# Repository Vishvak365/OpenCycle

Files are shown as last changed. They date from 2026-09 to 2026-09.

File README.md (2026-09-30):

# OpenCycle

An open-source GPS bike computer you print, solder and own.

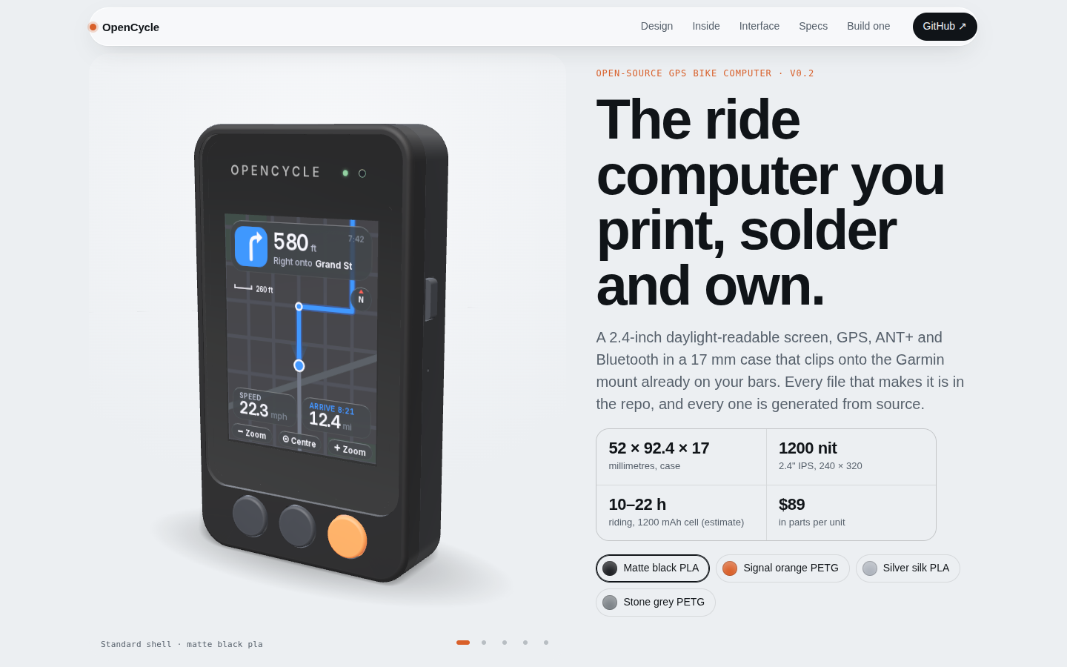
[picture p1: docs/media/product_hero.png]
OpenCycle v0.2, rendered from the CAD files


- **Screen:** 2.4" IPS TFT, 240 × 320, 1200 nit (Newhaven, ST7789), auto-dimmed by an ambient-light sensor.
- **Radios:** ESP32-S3 (Wi-Fi, Bluetooth to the phone, native USB) + Ezurio BL652 for ANT+ and Bluetooth sensors + u-blox MAX-M10S GPS with a 12 mm ceramic patch.
- **Also:** BMP581 barometer, I²S amp and sealed speaker, 3 soft keys + 2 side buttons, USB-C charging.
- **Battery:** 1200 mAh LiPo, ~10–22 h riding (estimate, not measured).
- **Case:** 52 × 92.4 × 17 mm, FDM-printed, Garmin quarter-turn mount; standard, aero and rugged shells.
- **Parts:** ~$89 per unit, every part priced and linked (Mouser + Digi-Key).

Everything is generated from source: the enclosure (CadQuery), the board **and** its schematic (KiCad 7 through Python + Freerouting), the BOMs, the print files and the 3D viewer.

## Status (v0.2)

| Area | State |
|---|---|
| Enclosure | Done. Fit-checked against placeholders and against every real part on the routed board. Print-ready STLs in [`print/`](print/README.md). |
| PCB | Routed, 4 layers. **DRC 0 errors / 0 unconnected**, ERC 0 errors, schematic netlist = board netlist. Gerbers, BOM and CPL in [`pcb/fab/`](pcb/fab). |
| Parts | Complete BOM with prices, links and specs: [`docs/sourcing/bom-v0.2.md`](docs/sourcing/bom-v0.2.md). |
| UI | "Lucent" design language, 10 screens: [`docs/UI.md`](docs/UI.md). |
| Firmware | Not started. The owner is finishing the UI first. Plan: [`docs/FIRMWARE.md`](docs/FIRMWARE.md). |

> **Ready to order a first prototype run, not yet built.** Nothing has been soldered or powered up. Treat the first five boards as prototypes and read the "not verified" list in [`pcb/README.md`](pcb/README.md) (RF, battery lead polarity, JLCPCB part rotations) before you pay.

## Build one

Step-by-step guides are in [`instructions/`](instructions/README.md):

1. [Order the parts](instructions/01-order-parts.md)
2. [Order the PCBs](instructions/02-order-pcb.md)
3. [Print the case](instructions/03-print-case.md)
4. [Assemble the board](instructions/04-assemble-board.md)
5. [Bring it up](instructions/05-bring-up.md)
6. [Final assembly](instructions/06-final-assembly.md)
7. [Next steps](instructions/07-next-steps.md)

## The board

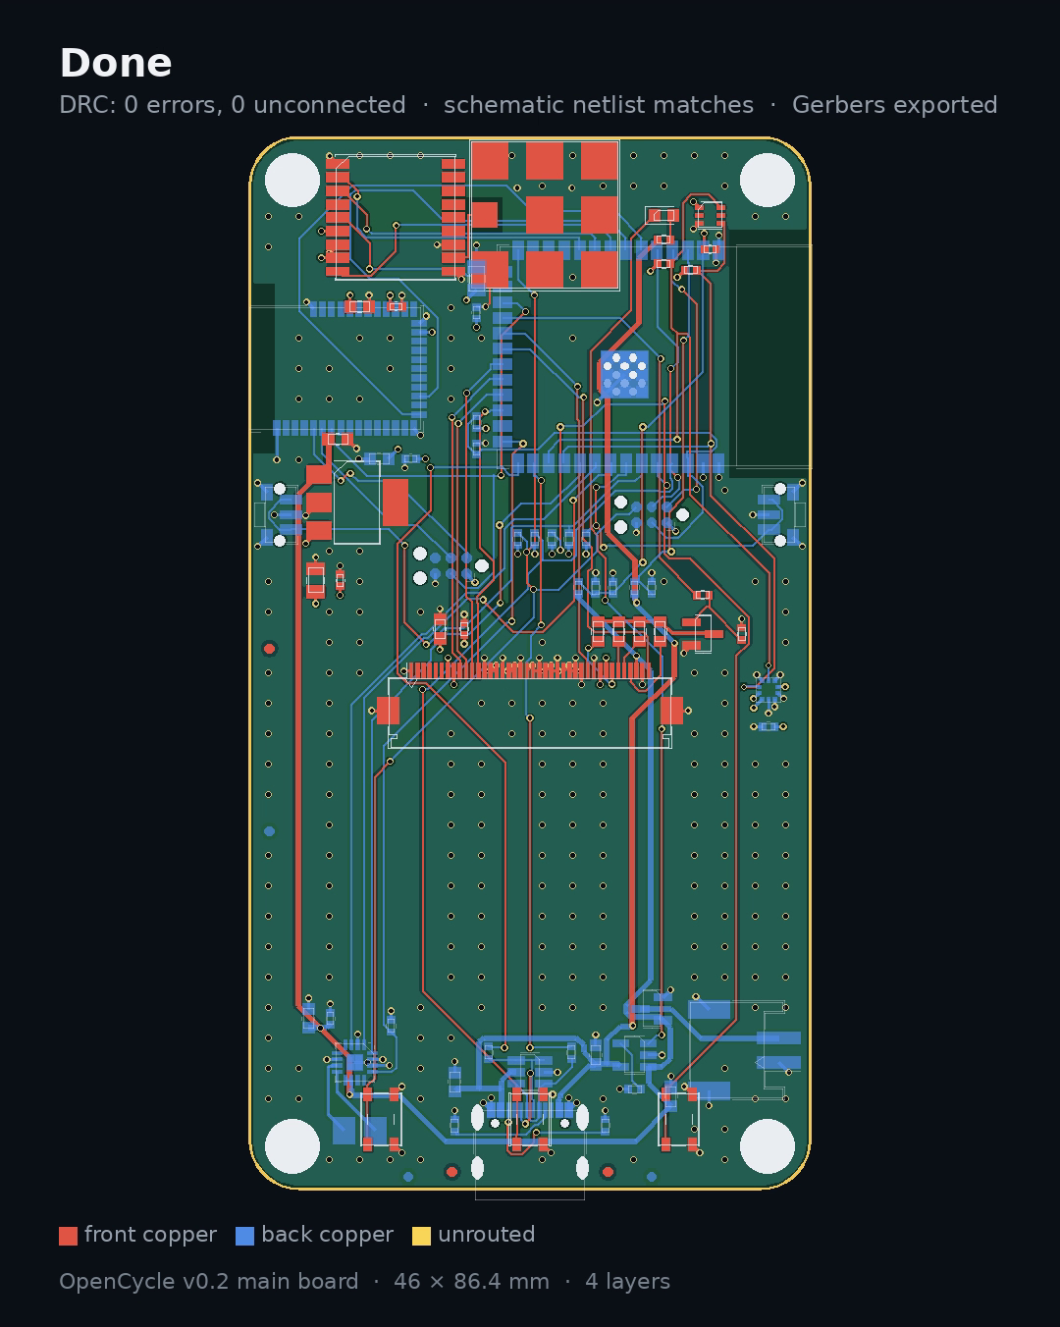
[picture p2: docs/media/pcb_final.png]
Routed v0.2 board


A time-lapse of the board being generated (placement, fan-out, routing, pours) is in [`docs/media/pcb_timelapse.mp4`](docs/media/pcb_timelapse.mp4).

## The interface

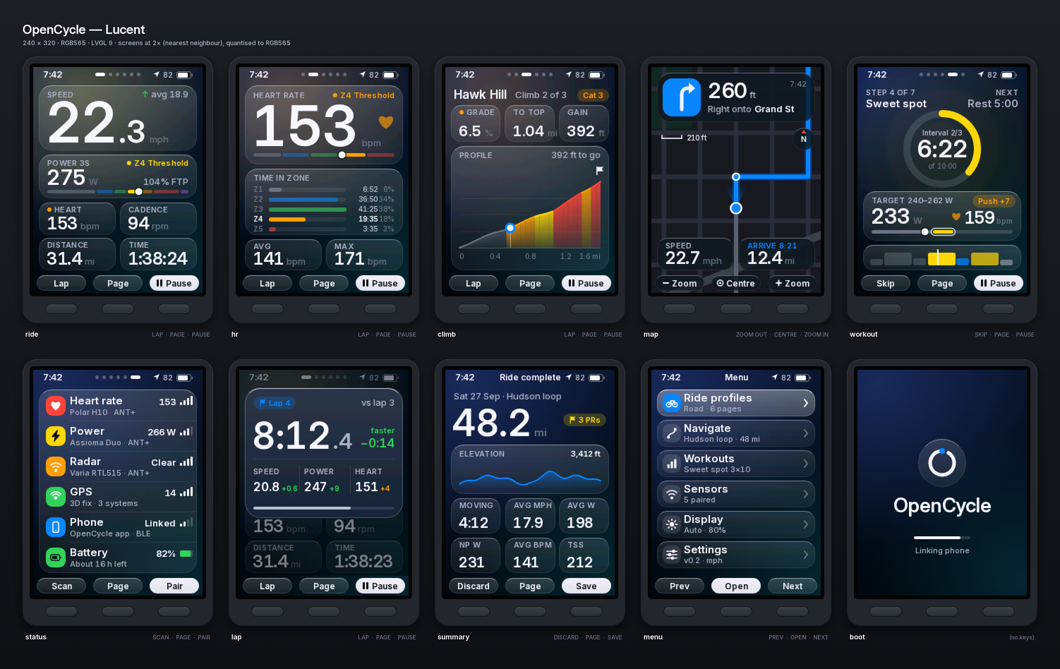
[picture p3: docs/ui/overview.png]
Lucent screens


## What's here

| Path | What it is |
|---|---|
| `cad/` | Parametric enclosure (CadQuery). `params.py` holds every dimension; `check_fit.py` and `board_fit.py` check it. |
| `pcb/` | `design.py` (parts, nets, placement, rules) → board, schematic, fab files. Status in `pcb/README.md`. |
| `print/` | Print-oriented STLs, STEP files and the cover-lens outline. |
| `viewer/` | three.js pages: `index.html` (studio viewer with net explorer) and `product.html` (product page). The Lucent reference renderer is `viewer/ui/screens_color.js`. |
| `instructions/` | How to order, build and bring up a unit. |
| `docs/` | Hardware, PCB, CAD, UI, sourcing and decision docs. Start with [`docs/README.md`](docs/README.md). |
| `tools/` | `build_all.sh` rebuilds everything; exporters for meshes, print files, BOM and the time-lapse. |
| `AGENTS.md` | Where the truth lives and what not to break, for AI agents and new contributors. |

## Quick start

```bash
# view the product (the generated assets are committed)
python3 -m http.server -d viewer 8000     # open http://localhost:8000/product.html or /index.html

# rebuild everything (CadQuery, KiCad 7, Java for Freerouting; see docs/SETUP.md)
./tools/build_all.sh
```

## Licence

No licence file has been chosen yet; until one is added, all rights are reserved by the author. The Inter typeface in `viewer/ui/fonts/` is used under the SIL Open Font License (`OFL-Inter.txt`).

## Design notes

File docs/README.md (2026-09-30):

# Documentation index

| Doc | Read it when |
|---|---|
| [../instructions/](../instructions/README.md) | You want to build one: order, print, assemble, bring up. |
| [SETUP.md](SETUP.md) | Installing the toolchain (CadQuery, KiCad 7, Freerouting). |
| [HARDWARE.md](HARDWARE.md) | What each part does and why, the ESP32 pin map, power budget. |
| [sourcing/](sourcing/README.md) | BOM with prices and links, part specs, stock problems, displays, market research. |
| [PCB.md](PCB.md) | Working on the board: stack-up, pipeline, placement, verification results. |
| [CAD.md](CAD.md) | Working on the enclosure: stack, front layout, variants. |
| [UI.md](UI.md) | The Lucent screen design language and the LVGL recipe. |
| [FIRMWARE.md](FIRMWARE.md) | Planning firmware. |
| [VIEWER.md](VIEWER.md) | Editing the three.js viewer. |
| [DECISIONS.md](DECISIONS.md) | Why things are the way they are, and what's still open. |
| [ROADMAP.md](ROADMAP.md) | What's next. |

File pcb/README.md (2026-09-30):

# OpenCycle main board v0.2 — status

**Ready to order a first prototype run** (5 boards): routed, DRC clean, schematic generated and netlist-matched, parts sourced, fab files exported. **Not yet built or tested** — treat the first run as a prototype and follow [`../instructions/05-bring-up.md`](../instructions/05-bring-up.md).

| What | Where |
|---|---|
| Board | `opencycle.kicad_pcb` (+ `.kicad_pro`, `.kicad_dru`, `fp-lib-table`, `sym-lib-table`: opens in KiCad 7+) |
| Schematic | `opencycle.kicad_sch`, PDF in `fab/opencycle_schematic.pdf` |
| Gerbers + drill | `fab/opencycle_v0.2_gerbers.zip` (upload to JLCPCB as-is) |
| Assembly | `fab/bom_jlcpcb.csv`, `fab/cpl_jlcpcb.csv`, `fab/assembly_front.pdf`, `fab/assembly_back.pdf` |
| Order list | `fab/bom_distributors.csv` and [`../docs/sourcing/bom-v0.2.md`](../docs/sourcing/bom-v0.2.md) |
| Checks | `drc_report.txt`, `erc_report.txt`, `check_place.py`, `check_netlist.py`, `../cad/board_fit.py` |

Everything is generated from `design.py` — do not hand-edit the board and then regenerate, you will lose the edit. If you do route by hand in KiCad, stop using the pipeline for that board and say so in `docs/DECISIONS.md`.

## Verified

- Pinouts of every IC/module against the manufacturer datasheet (see the header of `design.py` for the list and `docs/sourcing/part-specs.md` for details). Two errors in earlier notes were found and fixed: the BMP581 pin order and MAX-M10S pin 15.
- Land patterns drawn from datasheet drawings for the BMP581 and the Taoglas 12 mm patch; all other footprints from the KiCad 7 library.
- Mechanical fit of every real part (datasheet heights) against the enclosure, display, folded FFC, battery and speaker.
- DRC 0 errors / 0 unconnected; ERC 0 errors; schematic netlist == board netlist.

## Not verified (look at these before ordering / during bring-up)

1. **RF performance** of all three antennas (GPS patch ground is 46 mm wide and cut by the radio keep-outs; Taoglas characterised it on 50 × 50 mm). Expect to tune firmware (GPS LNA gain) and possibly move to a pin-fed patch later.
2. **Battery polarity** of the Adafruit lead vs. J2 (pin 1 −, pin 2 +). Q2 blocks a reversed cell, but measure before plugging in.
3. **JLCPCB rotation offsets** in `cpl_jlcpcb.csv` — JLC's preview shows each part; fix any that are rotated (common for SOT-23, QFN and connectors) in their tool before paying.
4. **RF_IN impedance**: 0.2 mm on the 1.0 mm JLC04101H-3313 stack-up is close to 50 Ω; confirm with the JLC impedance calculator or ask for impedance control.
5. **Backlight brightness** with 33 Ω ballasts: ≤ 45 mA per LED in the worst case (4.2 V, Vf 2.7 V), ~21 mA typical, so full brightness is only reached on a full battery. Don't lower the ballasts unless firmware caps the PWM duty from VBAT_SENSE: at 22 Ω the worst case is 68 mA per LED, above the 50 mA per-LED limit.
6. **Charging while running:** there is no USB power path — the system always runs from VBAT and the MCP73831 charges the cell and feeds the load in parallel (the same approach as Adafruit Feather boards). While the device is on and plugged in, the charger may not terminate (it holds 4.20 V). Fine for a few hours of charging; a power-path charger (e.g. BQ24072) is the v0.3 upgrade if this matters.
7. **Firmware**: nothing is written yet; the pin map is in `docs/HARDWARE.md`.

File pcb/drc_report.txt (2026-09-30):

** Drc report for opencycle.kicad_pcb **
** Created on 2026-09-30 06:21:55 **

** Found 6 DRC violations **
[lib_footprint_mismatch]: Footprint 'ESP32-S3-WROOM-1' does not match copy in library 'RF_Module'.
    Local override; Severity: warning
    @(36.2500 mm, 21.0000 mm): Footprint U1
[silk_edge_clearance]: Silkscreen clipped by board edge
    Rule: board setup constraints silk; Severity: warning
    @(49.0000 mm, 7.0000 mm): Line on Edge.Cuts
    @(49.1500 mm, 30.2000 mm): Line on B.Silkscreen
[silk_edge_clearance]: Silkscreen clipped by board edge
    Rule: board setup constraints silk; Severity: warning
    @(49.0000 mm, 7.0000 mm): Line on Edge.Cuts
    @(49.1500 mm, 11.8000 mm): Line on B.Silkscreen
[silk_edge_clearance]: Silkscreen clipped by board edge
    Rule: board setup constraints silk; Severity: warning
    @(3.0000 mm, 85.4000 mm): Line on Edge.Cuts
    @(3.0490 mm, 27.2070 mm): Line on B.Silkscreen
[silk_edge_clearance]: Silkscreen clipped by board edge
    Rule: board setup constraints silk; Severity: warning
    @(3.0000 mm, 85.4000 mm): Line on Edge.Cuts
    @(7.6210 mm, 16.7930 mm): Line on B.Silkscreen
[via_dangling]: Via is not connected or connected on only one layer
    Local override; Severity: warning
    @(45.6000 mm, 46.3875 mm): Via [I2C_SDA] on F.Cu - B.Cu

** Found 0 unconnected pads **

** Found 0 Footprint errors **

** End of Report **

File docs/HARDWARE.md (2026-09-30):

# Hardware (board v0.2, colour build)

Source of truth: [`pcb/design.py`](../pcb/design.py). Schematic: [`pcb/fab/opencycle_schematic.pdf`](../pcb/fab/opencycle_schematic.pdf) (generated from the same table, netlist-checked against the board). Prices, links and stock: [`sourcing/bom-v0.2.md`](sourcing/bom-v0.2.md).

## Block diagram

```
USB-C ─ ESD ─┬─ VBUS ── MCP73831 charger ──┐                  ┌─ AP7361C 3.3 V LDO ── +3V3 plane ─┐
             │                              ├── VBAT ─────────┼─ MAX98357A amp ── speaker          │
             └─ D+/D- (0R) ─ ESP32 USB      │                 └─ TFT backlight (4 × 33 R, PWM FET)  │
JST-PH ─ BATT+ ─ P-FET (reverse-battery) ───┘                                                      │
                                                                                                   │
   ┌──────────────── ESP32-S3-WROOM-1-N16R8 (UI, logging, Wi-Fi, BLE, USB) ◄──────────────────────┘
   │  SPI  ──► Newhaven 2.4" IPS TFT (ST7789, 240 × 320) via 40-pin FFC
   │  UART ──► u-blox MAX-M10S GPS ◄── 12 mm Taoglas patch
   │  UART ──► BL652 (nRF52832): ANT+ and BLE sensor bridge   [SWD on Tag-Connect J4]
   │  I²C  ──► BMP581 barometer, LTR-303 ambient light
   │  I²S  ──► MAX98357A class-D amp
   │  GPIO ◄── 3 front soft keys + 2 side buttons, battery / USB sense (ADC)
```

## Parts and why

| Ref | Part | Job | Why this one |
|---|---|---|---|
| U1 | Espressif ESP32-S3-WROOM-1-N16R8 | Main MCU: UI (LVGL), logging, Wi-Fi sync, BLE, native USB | Enough RAM (8 MB PSRAM) for two 150 KB frame buffers and map tiles; USB flashing without a programmer. Antenna at the right board edge. |
| U2 | Ezurio BL652-SA (nRF52832) | ANT+ and BLE sensor bridge | The ESP32 has no ANT+. Pre-certified module with integrated antenna at the left edge. |
| U3 | u-blox MAX-M10S | GPS / Galileo / BeiDou / GLONASS | Lowest-power receiver in its class (~25 mW tracking). |
| AE1 | Taoglas DSGP.1575.12.4.A.02 | 12 × 12 mm ceramic GPS patch | Best reception that fits the 15.6 mm top band; land pattern from the Taoglas datasheet. |
| J3 | Hirose FH12-40S-0.5SH(55) | 40-pin FFC connector for the display | Bottom contact, matches the Newhaven tail after it folds behind the panel. |
| — | Newhaven NHD-2.4-240320AF-CSXP | 2.4" IPS TFT 240 × 320, 1200 nit | In stock at Mouser, datasheet with full drawing; readable in daylight at full backlight. |
| Q1, R5–R10 | DMG2302UK + 4 × 33 Ω (0603) | Backlight PWM | LEDA from VBAT: ≤ 45 mA per LED even at 4.2 V with the lowest Vf (datasheet max 50 mA per LED / 200 mA total); ~21 mA typ. at 3.7 V. |
| U4 | Lite-On LTR-303ALS | Ambient light → auto backlight | Biggest lever on battery life with a TFT. Sits under a clear window in the lens mask. |
| U8 | Bosch BMP581 | Barometer: altitude, climb | Best-in-class noise; the only well-stocked option (Digi-Key). Next to the case vent. |
| U7 | MAX98357A | I²S class-D amp | Real sampled audio (alerts, turn prompts). |
| LS1 | Same Sky CMS-151125-078L100 | 15 × 11 mm IP67 speaker | Fires through the back-shell grille. |
| U6 | MCP73831-2 | Li-ion charger, 500 mA (R15 = 2 k) | Simple, proven. |
| U5 | Diodes AP7361C-33E (SOT-223) | 3.3 V, 1 A LDO | ESP32 Wi-Fi peaks ~500 mA. Note: the "E" (not "ER") package, pin 1 IN / 2 GND / 3 OUT. |
| Q2 | DMG2305UX | Reverse-battery protection | P-FET, gate to ground: a reversed cell can't damage the board. |
| J1, D2 | GCT USB4105 + USBLC6-2SC6 | USB-C with ESD | 5.1 k CC pull-downs for 5 V from any USB-C charger. |
| J2 | JST S2B-PH-SM4-TB | Battery socket | Matches the Adafruit 258 cell's JST-PH plug. Pin 1 −, pin 2 +. |
| SW1–SW3 | C&K PTS810 (2.5 mm) | Front soft keys | Top-actuated; the display draws their labels. |
| SW4, SW5 | Alps SKRTLAE010 | Side buttons (power/back, menu) | Side-actuated, sits behind the wall plungers. |
| J4, J5 | Tag-Connect TC2030-NL pads | BL652 SWD / ESP32 recovery UART | Nothing to assemble; one cable for all boards. |

## ESP32-S3 pin map

| GPIO | Net | Notes |
|---|---|---|
| IO0 | KEY_L | Strapping pin: hold the left key while resetting = download mode |
| IO1 / IO2 | VBAT_SENSE / VBUS_SENSE | ADC1 (1 M/1 M and 100 k/100 k dividers) |
| IO3 | AMP_EN | Strapping pin (JTAG source, only with eFuse); 100 k pull-down keeps the amp off at boot |
| IO4 / IO5 | KEY_C / KEY_R | RTC GPIOs: can wake from deep sleep |
| IO6 / IO7 | BTN_PWR / BTN_MENU | RTC GPIOs |
| IO8 / IO18 | I2C_SDA / I2C_SCL | 4.7 k pull-ups; BMP581 0x46, LTR-303 0x29 |
| IO9–IO14 | LCD_DC, CS, MOSI, SCK, TE, RST | IO10–IO12 are the FSPI IO_MUX pins (fast SPI) |
| IO21 | LCD_BL | Backlight PWM (LEDC) |
| IO15–IO17 | I2S_BCLK, LRCLK, DIN | |
| IO19 / IO20 | USB D− / D+ | Native USB (serial/JTAG + flashing) |
| IO38 / IO39 / IO40 / IO48 | GPS_TX (in) / GPS_RX (out) / GPS_RST / GPS_EXTINT | |
| IO41 / IO42 / IO47 | BLE_TX (in) / BLE_RX (out) / BLE_RST | BL652 UART on SIO_06 / SIO_08, reset on SIO_21 |
| TXD0 / RXD0 / EN | Console / reset | On Tag-Connect J5 for recovery |
| IO35–IO37 | — | Used by the octal PSRAM on the N16R8, not available |
| IO45 / IO46 | — | Strapping pins, left at their default pull-downs |

## Power budget (estimate, riding)

| Load | Avg current |
|---|---|
| GPS continuous tracking | 7–8 mA |
| ESP32-S3 (UI, BLE, logging; Wi-Fi only to sync) | 15–25 mA |
| BL652 ANT+/BLE sensors | 1–2 mA |
| TFT logic | ~10 mA |
| Backlight (auto-dimmed) | 20–85 mA (≤ 180 mA at 100 % PWM on a full battery) |
| **Total** | **~55–130 mA** |

With the 1200 mAh cell: **~10–22 h**. Sleep: ESP32 deep sleep + GPS backup mode + BL652 System OFF, in the tens of µA (plus the LDO's quiescent current). Details: [`sourcing/power-budget.md`](sourcing/power-budget.md).

## Things a reviewer should look at first

1. RF: the ESP32 and BL652 antennas are at the board edges with keep-outs, but the case walls and battery are close; the GPS patch ground is smaller than Taoglas's 50 × 50 mm test board. Nothing is measured yet.
2. Battery polarity at J2 (see [`instructions/05-bring-up.md`](../instructions/05-bring-up.md)); Q2 protects the board either way.
3. Backlight current: firmware should cap the PWM duty on a full battery if the panel gets warm.
4. No USB power path: the board always runs from the battery; the charger feeds cell and load in parallel and may not terminate while the device is on (see `pcb/README.md`).
5. The BMP581 INT pin is tied to ground (Bosch-recommended when unused): firmware must keep `INT_CONFIG.int_en = 0`.

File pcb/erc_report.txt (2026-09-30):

ERC report (2026-09-30T06:03:15+0000, Encoding UTF8)
Report includes: Errors, Warnings, Exclusions

***** Sheet /
[lib_symbol_issues]: The current configuration does not include the symbol library 'RF_Module'
    ; warning
    @(66.04 mm, 74.93 mm): Symbol U1 [ESP32-S3-WROOM-1]
[lib_symbol_issues]: The current configuration does not include the symbol library 'Device'
    ; warning
    @(50.80 mm, 119.38 mm): Symbol C1 [C]
[lib_symbol_issues]: The current configuration does not include the symbol library 'Connector_Generic'
    ; warning
    @(138.43 mm, 52.07 mm): Symbol J5 [Conn_01x06]
[lib_symbol_issues]: The current configuration does not include the symbol library 'Device'
    ; warning
    @(50.80 mm, 139.70 mm): Symbol C2 [C]
[lib_symbol_issues]: The current configuration does not include the symbol library 'Device'
    ; warning
    @(50.80 mm, 160.02 mm): Symbol R1 [R]
[lib_symbol_issues]: The current configuration does not include the symbol library 'Device'
    ; warning
    @(50.80 mm, 180.34 mm): Symbol C3 [C]
[lib_symbol_issues]: The current configuration does not include the symbol library 'Device'
    ; warning
    @(205.74 mm, 116.84 mm): Symbol C4 [C]
[lib_symbol_issues]: The current configuration does not include the symbol library 'RF_Bluetooth'
    ; warning
    @(231.14 mm, 74.93 mm): Symbol U2 [BL652]
[lib_symbol_issues]: The current configuration does not include the symbol library 'Device'
    ; warning
    @(205.74 mm, 137.16 mm): Symbol C5 [C]
[lib_symbol_issues]: The current configuration does not include the symbol library 'Connector'
    ; warning
    @(58.42 mm, 243.84 mm): Symbol J1 [USB_C_Receptacle_USB2.0_16P]
[lib_symbol_issues]: The current configuration does not include the symbol library 'Device'
    ; warning
    @(125.73 mm, 232.41 mm): Symbol R14 [R]
[lib_symbol_issues]: The current configuration does not include the symbol library 'Connector'
    ; warning
    @(208.28 mm, 163.83 mm): Symbol J4 [Conn_ARM_SWD_TagConnect_TC2030-NL]
[lib_symbol_issues]: The current configuration does not include the symbol library 'Device'
    ; warning
    @(125.73 mm, 252.73 mm): Symbol C14 [C]
[lib_symbol_issues]: The current configuration does not include the symbol library 'Device'
    ; warning
    @(50.80 mm, 283.21 mm): Symbol R11 [R]
[lib_symbol_issues]: The current configuration does not include the symbol library 'Device'
    ; warning
    @(50.80 mm, 303.53 mm): Symbol R12 [R]
[lib_symbol_issues]: The current configuration does not include the symbol library 'Battery_Management'
    ; warning
    @(135.89 mm, 276.86 mm): Symbol U6 [MCP73831-2-OT]
[lib_symbol_issues]: The current configuration does not include the symbol library 'Transistor_FET'
    ; warning
    @(203.20 mm, 233.68 mm): Symbol Q2 [DMG2301L]
[lib_symbol_issues]: The current configuration does not include the symbol library 'Regulator_Linear'
    ; warning
    @(205.74 mm, 251.46 mm): Symbol U5 [AP7361C-33E]
[lib_symbol_issues]: The current configuration does not include the symbol library 'Device'
    ; warning
    @(125.73 mm, 300.99 mm): Symbol R15 [R]
[lib_symbol_issues]: The current configuration does not include the symbol library 'Power_Protection'
    ; warning
    @(55.88 mm, 325.12 mm): Symbol D2 [USBLC6-2SC6]
[lib_symbol_issues]: The current configuration does not include the symbol library 'Device'
    ; warning
    @(198.12 mm, 275.59 mm): Symbol C11 [C]
[lib_symbol_issues]: The current configuration does not include the symbol library 'Device'
    ; warning
    @(328.93 mm, 99.06 mm): Symbol C6 [C]
[lib_symbol_issues]: The current configuration does not include the symbol library 'Device'
    ; warning
    @(125.73 mm, 321.31 mm): Symbol C15 [C]
[lib_symbol_issues]: The current configuration does not include the symbol library 'Device'
    ; warning
    @(328.93 mm, 119.38 mm): Symbol C7 [C]
[lib_symbol_issues]: The current configuration does not include the symbol library 'RF_GPS'
    ; warning
    @(344.17 mm, 64.77 mm): Symbol U3 [MAX-M10S]
[lib_symbol_issues]: The current configuration does not include the symbol library 'Device'
    ; warning
    @(265.43 mm, 232.41 mm): Symbol C17 [C]
[lib_symbol_issues]: The current configuration does not include the symbol library 'Device'
    ; warning
    @(50.80 mm, 349.25 mm): Symbol R13 [R]
[lib_symbol_issues]: The current configuration does not include the symbol library 'Device'
    ; warning
    @(198.12 mm, 295.91 mm): Symbol C12 [C]
[lib_symbol_issues]: The current configuration does not include the symbol library 'Device'
    ; warning
    @(125.73 mm, 341.63 mm): Symbol C16 [C]
[lib_symbol_issues]: The current configuration does not include the symbol library 'Device'
    ; warning
    @(265.43 mm, 252.73 mm): Symbol R18 [R]
[lib_symbol_issues]: The current configuration does not include the symbol library 'Device'
    ; warning
    @(198.12 mm, 316.23 mm): Symbol C13 [C]
[lib_symbol_issues]: The current configuration does not include the symbol library 'Device'
    ; warning
    @(265.43 mm, 273.05 mm): Symbol R19 [R]
[lib_symbol_issues]: The current configuration does not include the symbol library 'Connector_Generic_MountingPin'
    ; warning
    @(130.81 mm, 358.14 mm): Symbol J2 [Conn_01x02_MountingPin]
[lib_symbol_issues]: The current configuration does not include the symbol library 'Device'
    ; warning
    @(198.12 mm, 336.55 mm): Symbol R16 [R]
[lib_symbol_issues]: The current configuration does not include the symbol library 'Device'
    ; warning
    @(269.24 mm, 289.56 mm): Symbol D1 [LED]
[lib_symbol_issues]: The current configuration does not include the symbol library 'Device'
    ; warning
    @(265.43 mm, 306.07 mm): Symbol R2 [R]
[lib_symbol_issues]: The current configuration does not include the symbol library 'Device'
    ; warning
    @(198.12 mm, 356.87 mm): Symbol R17 [R]
[lib_symbol_issues]: The current configuration does not include the symbol library 'Sensor_Optical'
    ; warning
    @(355.60 mm, 238.76 mm): Symbol U4 [LTR-303ALS-01]
[lib_symbol_issues]: The current configuration does not include the symbol library 'Device'
    ; warning
    @(345.44 mm, 265.43 mm): Symbol C8 [C]
[lib_symbol_issues]: The current configuration does not include the symbol library 'Connector_Generic_MountingPin'
    ; warning
    @(435.61 mm, 95.25 mm): Symbol J3 [Conn_01x40_MountingPin]
[lib_symbol_issues]: The current configuration does not include the symbol library 'Device'
    ; warning
    @(345.44 mm, 285.75 mm): Symbol R3 [R]
[lib_symbol_issues]: The current configuration does not include the symbol library 'Device'
    ; warning
    @(345.44 mm, 306.07 mm): Symbol R4 [R]
[lib_symbol_issues]: The current configuration does not include the symbol library 'Device'
    ; warning
    @(430.53 mm, 167.64 mm): Symbol C9 [C]
[pin_to_pin]: Pins of type Bidirectional and Power output are connected
    ; warning
    @(345.44 mm, 330.20 mm): Symbol U8 Pin 5 [SDO, Bidirectional, Line]
    @(670.56 mm, 548.64 mm): Symbol #FLG01 Pin 1 [pwr, Power output, Line]
[lib_symbol_issues]: The current configuration does not include the symbol library 'Device'
    ; warning
    @(487.68 mm, 50.80 mm): Symbol C10 [C]
[pin_to_pin]: Pins of type Tri-state and Power input are connected
    ; warning
    @(365.76 mm, 327.66 mm): Symbol U8 Pin 7 [INT, Tri-state, Line]
    @(360.68 mm, 335.28 mm): Symbol U8 Pin 9 [VSS, Power input, Line]
[lib_symbol_issues]: The current configuration does not include the symbol library 'Device'
    ; warning
    @(487.68 mm, 71.12 mm): Symbol R5 [R]
[lib_symbol_issues]: The current configuration does not include the symbol library 'Device'
    ; warning
    @(345.44 mm, 351.79 mm): Symbol C20 [C]
[lib_symbol_issues]: The current configuration does not include the symbol library 'Device'
    ; warning
    @(487.68 mm, 91.44 mm): Symbol R6 [R]
[lib_symbol_issues]: The current configuration does not include the symbol library 'Device'
    ; warning
    @(487.68 mm, 111.76 mm): Symbol R7 [R]
[lib_symbol_issues]: The current configuration does not include the symbol library 'Device'
    ; warning
    @(487.68 mm, 132.08 mm): Symbol R8 [R]
[lib_symbol_issues]: The current configuration does not include the symbol library 'Audio'
    ; warning
    @(450.85 mm, 241.30 mm): Symbol U7 [MAX98357A]
[lib_symbol_issues]: The current configuration does not include the symbol library 'Device'
    ; warning
    @(438.15 mm, 270.51 mm): Symbol C18 [C]
[lib_symbol_issues]: The current configuration does not include the symbol library 'Transistor_FET'
    ; warning
    @(492.76 mm, 153.67 mm): Symbol Q1 [DMG2302U]
[lib_symbol_issues]: The current configuration does not include the symbol library 'Device'
    ; warning
    @(487.68 mm, 175.26 mm): Symbol R9 [R]
[pin_to_pin]: Pins of type Unspecified and Power input are connected
    ; warning
    @(453.39 mm, 254.00 mm): Symbol U7 Pin 17 [PAD, Unspecified, Line]
    @(448.31 mm, 254.00 mm): Symbol U7 Pin 3 [GND, Power input, Line]
[lib_symbol_issues]: The current configuration does not include the symbol library 'Device'
    ; warning
    @(438.15 mm, 290.83 mm): Symbol C19 [C]
[lib_symbol_issues]: The current configuration does not include the symbol library 'Device'
    ; warning
    @(438.15 mm, 311.15 mm): Symbol R20 [R]
[lib_symbol_issues]: The current configuration does not include the symbol library 'Device'
    ; warning
    @(547.37 mm, 50.80 mm): Symbol R10 [R]
[lib_symbol_issues]: The current configuration does not include the symbol library 'Device'
    ; warning
    @(443.23 mm, 327.66 mm): Symbol LS1 [Speaker]
[lib_symbol_issues]: The current configuration does not include the symbol library 'Switch'
    ; warning
    @(539.75 mm, 228.60 mm): Symbol SW1 [SW_Push]
[lib_symbol_issues]: The current configuration does not include the symbol library 'Switch'
    ; warning
    @(539.75 mm, 241.30 mm): Symbol SW2 [SW_Push]
[lib_symbol_issues]: The current configuration does not include the symbol library 'Switch'
    ; warning
    @(539.75 mm, 254.00 mm): Symbol SW3 [SW_Push]
[lib_symbol_issues]: The current configuration does not include the symbol library 'Switch'
    ; warning
    @(539.75 mm, 266.70 mm): Symbol SW4 [SW_Push]
[lib_symbol_issues]: The current configuration does not include the symbol library 'Switch'
    ; warning
    @(539.75 mm, 279.40 mm): Symbol SW5 [SW_Push]
[lib_symbol_issues]: The current configuration does not include the symbol library 'Device'
    ; warning
    @(534.67 mm, 295.91 mm): Symbol R21 [R]
[lib_symbol_issues]: The current configuration does not include the symbol library 'Device'
    ; warning
    @(534.67 mm, 316.23 mm): Symbol R22 [R]
[lib_symbol_issues]: The current configuration does not include the symbol library 'Device'
    ; warning
    @(534.67 mm, 336.55 mm): Symbol R23 [R]
[lib_symbol_issues]: The current configuration does not include the symbol library 'Device'
    ; warning
    @(596.90 mm, 232.41 mm): Symbol R25 [R]
[lib_symbol_issues]: The current configuration does not include the symbol library 'Device'
    ; warning
    @(534.67 mm, 356.87 mm): Symbol R24 [R]
[lib_symbol_issues]: The current configuration does not include the symbol library 'power'
    ; warning
    @(670.56 mm, 548.64 mm): Symbol #FLG01 [PWR_FLAG]
[lib_symbol_issues]: The current configuration does not include the symbol library 'power'
    ; warning
    @(693.42 mm, 548.64 mm): Symbol #FLG02 [PWR_FLAG]
[lib_symbol_issues]: The current configuration does not include the symbol library 'power'
    ; warning
    @(716.28 mm, 548.64 mm): Symbol #FLG03 [PWR_FLAG]

 ** ERC messages: 73  Errors 0  Warnings 73

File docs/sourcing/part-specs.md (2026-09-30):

# Part specs

Engineering data for every part considered. Units are mm unless noted. "Verified" / "Library" / "Open" are explained in [README.md](README.md).

---

## Colour build (v0.2)

### ESP32-S3-WROOM-1-N16R8 — main MCU
- Buy: Mouser 356-ESP32S3WRM1N16R8, $6.72, 47,727 in stock (Verified). Digi-Key ~$6.76.
- Size: **25.5 × 18.0 × 3.1**, PCB antenna at one short end (Verified, Mouser).
- Memory: 16 MB quad-SPI flash, 8 MB octal PSRAM. Dual-core LX7 at 240 MHz, 512 KB SRAM.
- Radio: Wi-Fi 802.11 b/g/n, BLE 5.0, 20.5 dBm. **No ANT+.**
- Supply: 3.0–3.6 V; Wi-Fi transmit peaks ~500 mA, so the regulator must handle 1 A.
- Operating temperature −40 to +65 °C (N16R8 variant).
- Interfaces: native USB (flash and debug over USB-C, no programmer needed), SPI, I²C, I²S, UART, PWM.
- Footprint: KiCad `RF_Module:ESP32-S3-WROOM-1`, 62 pads, fab body 18.1 × 25.6 (Library). Keep copper off every layer under the antenna and ≥ 15 mm clear around it where possible; antenna end at a board edge.
- Boot: GPIO0 strap (tie to a side button); EN with 10 k + 1 µF RC.

### Ezurio (Laird) BL652-SA-01-T/R — ANT+ / BLE coprocessor
- Buy: Mouser 239-BL652-SA-01-T/R, $10.40, 5,583 in stock (Verified). Newark $9.46. Digi-Key T/R ~$11.61 (1000 MOQ).
- Chip: Nordic nRF52832 (Mouser lists the part as Bluetooth v4.2; the chip supports BLE 5 with Nordic SoftDevices, including the ANT variants S212/S332).
- Size: fab body 14.1 × 10.1 (Library), integrated antenna, NFC pins.
- Footprint: KiCad `RF_Module:Laird_BL652`, 39 pads (Library).
- Programming: SWD via Tag-Connect pads, or from the ESP32 later.
- Link to ESP32: UART (TX/RX, optional RTS/CTS) plus a reset line.
- Note: ANT SoftDevices need Garmin's ANT+ licence for commercial products; free for development and hobby use.

### u-blox MAX-M10S-00B — GPS
- Buy: Mouser 377-MAX-M10S-00B, $9.12 (2,746 at the second check, 16,866 at the first); Digi-Key 672-MAX-M10S-00B-CT-ND $11.42, 4,987 (Verified). LCSC C4153167.
- Size: 9.7 × 10.1 × ~2.5, LCC-18 (Verified/Library). KiCad `RF_GPS:ublox_MAX`.
- Constellations: GPS, Galileo, BeiDou, GLONASS, QZSS, NavIC. Integrated TCXO, LNA, SAW.
- Pins (Verified, data sheet UBX-20035208 R02 Table 9): 1 GND, 2 TXD, 3 RXD, 4 TIMEPULSE, 5 EXTINT, 6 V_BCKP, 7 V_IO (must be tied to VCC), 8 VCC, 9 RESET_N, 10 GND, 11 RF_IN, 12 GND, 13 LNA_EN, 14 VCC_RF, **15 Reserved (leave open; KiCad's symbol calls it VIO_SEL)**, 16 SDA, 17 SCL, 18 SAFEBOOT_N (leave open).
- Power: ~25 mW continuous tracking (u-blox figure); Mouser lists "100 mA" as the maximum operating current.
- RF: 50 Ω RF_IN; for a passive patch, leave VCC_RF and LNA_EN open.

### Taoglas DSGP.1575.12.4.A.02 — GPS patch antenna (SMT) — used on v0.2
- Buy: Digi-Key, $4.25, 1,474 in stock (2026-09-30, via findchips). Newark 289. Mouser did not list stock.
- Size **12 × 12 × 4**, 3.3 g, ceramic, passive, GPS L1 / Galileo E1, 1575.42 ± 1.023 MHz, 2.73 dBi peak, 62 % efficiency, RHCP, tuned on a **50 × 50 mm** ground plane (ours is 46 × 86 but cut by the antenna keep-outs: expect less than datasheet performance).
- Pins: 1 = RF feed, 2–9 = ground.
- Land pattern (Verified from the §6.5 footprint drawing): eight 3.0 × 3.0 mm ground pads on a 4.5 mm grid around the centre, the feed pad 2.0 × 2.0 mm centred 4.9 mm from the centre on the feed side, 0.5 mm copper keep-out ring around the feed. Antenna underside: ground metallisation with a 2.0 × 0.8 mm feed contact at the edge (§5).
- The earlier 15 mm part (DSGP.1575.15.4.A.02) is not used any more.

### Newhaven NHD-2.4-240320AF-CSXP — 2.4" IPS TFT
- Buy: Mouser 763-24240320AFCSXP, **$15.86, 1,032 in stock** (Verified). Digi-Key: 0 in stock ($16.91). Newhaven direct $13.94. Touch variants: resistive -T $20.12, capacitive -CTP $32.08.
- Technology: IPS, transmissive, normally black, anti-glare; 1200 cd/m²; contrast 1500; 80° viewing all round; 262K colours; −20 to +70 °C operating.
- Controller: Sitronix ST7789VI. Interfaces: 8/16-bit 8080 parallel, 3/4-wire SPI.
- Mechanical (Verified, drawing Rev 2B 03/11/2025):
  - Outline 42.80 ± 0.2 × 59.91 ± 0.2 × 2.55 ± 0.2.
  - Bezel opening 38.92 × 51.16 (margins 1.94 sides, 1.92 top). Polariser 38.42 × 50.66 (2.19 / 2.17). Active area 36.72 × 48.96 (3.04 sides, 3.02 top, 7.93 bottom); active-area centre 27.50 below the top edge.
  - SUS304 frame 0.15.
  - FFC exits the bottom edge: EMI-shielded section 39.0 ± 0.2 wide, 13.2 long, then a tail 20.5 ± 0.07 wide. Unfolded, the tail end is 30.0 ± 0.5 below the panel; tail left edge 11.15 ± 0.3 from the outline's left edge (front view).
  - Contacts: 40 × 0.35 ± 0.03 wide at 0.50 ± 0.05 pitch (span 19.50 ± 0.05); pin 1 on the left in front view; PI stiffener 0.30 ± 0.03 on the opposite side; stiffened length ≥ 5.5; R0.3 corners.
  - Folded behind the panel: contact end 27.80 ± 0.3 above the panel's bottom edge; 11.15 ± 0.3 from the rear-view left edge; pin 40 left, pin 1 right; ≤ 0.8 extra thickness behind the panel; bend ~2.43.
- Pinout (Verified): 1 GND · 2–5 NC · 6 SDO · 7 VDD (3.3 V) · 8 VDDI (1.65–3.6 V) · 9 SDA · 10 CSX · 11 DCX/SCL · 12 WRX/DCX · 13 RDX · 14–29 DB0–DB15 · 30 RESX · 31–33 IM0–IM2 · 34–37 LEDK1–4 · 38 LEDA · 39 GND · 40 TE.
- 4-wire SPI: IM0 = 0, IM1 = 1, IM2 = 1.
- Logic supply ~10 mA typ (5–15 mA).
- Backlight: 4 LEDs in parallel, common anode, Vf 2.7 / 3.0 / 3.4 V (min/typ/max), If 160 mA typ, 200 mA max, 50,000 h to half brightness.
- Recommended connector: Molex 54132-4062 (bottom contact).
- [Datasheet](https://newhavendisplay.com/content/specs/NHD-2.4-240320AF-CSXP.pdf) · [Product page](https://newhavendisplay.com/2-4-tft-lcd-ips-high-brightness-display/). The drawing carries Newhaven's "do not reproduce" notice, so only the numbers are transcribed here.

### Hirose FH12-40S-0.5SH(55) — display FFC connector
- Buy: Mouser 798-FH12-40S-0.5SH55, $2.50, 25,967 (Verified). Bottom contact, right angle, ZIF, 0.5 mm pitch, gold, 500 mA, −40 to +85 °C.
- Footprint: KiCad `Connector_FFC-FPC:Hirose_FH12-40S-0.5SH_1x40-1MP_P0.50mm_Horizontal` (Library).
- Newhaven's recommended alternative: Molex 54132-4062, Mouser 538-54132-4062, $2.42, 30,165 in stock, bottom contact (no KiCad footprint).

### Diodes DMG2305UX-7 — reverse-battery P-FET (v0.2)
- Digi-Key DMG2305UX-7DICT-ND, $0.30, 75,458 in stock (2026-09-30). P-channel 20 V 4.2 A SOT-23, pinout 1 G · 2 S · 3 D (Diodes SOT-23 standard; KiCad symbol DMG2301L used, same pinout). Gate to GND, drain to the battery, source to VBAT.

### Diodes DMG2302UK-7 — backlight switch
- Mouser 621-DMG2302UK-7, $0.39, 238,766 (Verified). N-channel, SOT-23, 20 V, 2.8 A, 90 mΩ, Vgs(th) 0.3 V, 660 mW.
- Circuit: LEDA from 3.3 V (or VBAT); each LEDKx through its own ballast resistor to the drain; PWM on the gate from the ESP32 (LEDC peripheral).

### Lite-On LTR-303ALS-01 — ambient light sensor
- Mouser 859-LTR-303ALS-01, $0.68, 29,622 (Verified). I²C, 0.01–64k lux, 50/60 Hz flicker rejection, −30 to +70 °C.
- Footprint: KiCad `OptoDevice:Lite-On_LTR-303ALS-01` (Library), 2 × 2 ChipLED-6. Needs a clear window in the lens mask.

### Bosch BMP581 — barometer
- Buy: **Digi-Key 828-BMP581CT-ND, $3.07, 462** (Verified). Mouser 262-BMP581: 0 in stock, 159,933 on order.
- Package: 10-pin metal-lid LGA, 2.0 × 2.0 (1.9–2.1), height 0.75 typ (0.7–0.8) (Verified, datasheet).
- Pins (Verified against Table 28 of BST-BMP581-DS004-13, 2026-09-30): 1 VDDIO · 2 SCK · 3 VSS · 4 SDI · 5 SDO · 6 CSB · 7 INT · 8 VSS · 9 VSS · 10 VDD. **Correction:** an earlier version of this file listed a different (wrong) order.
- Supply: VDD 1.71–3.6 V, VDDIO 1.08–3.6 V. I²C address 0x46 (SDO = 0) or 0x47 (SDO = 1); SPI up to 12 MHz; I3C.
- Land pattern (Verified, datasheet §8.1–8.2 drawings): package pads 0.25 × 0.275 at ±0.7625 mm, 0.5 mm pitch; land = pad + 25 µm per side (0.30 × 0.325); top view pin 1 top-left, pins 10-9-8 along the top edge. Implemented in `pcb/lib/gen_footprints.py`. I²C: CSB to VDDIO, SDO to GND (0x46), INT to GND with the interrupt disabled (Bosch §6.2).
- Needs a vent to outside air: a hole in the case with a breathable membrane.

### Analog Devices / Maxim MAX98357AETE+T — I²S class-D amp
- Mouser 700-MAX98357AETE+T, $4.08, 10,971 (Verified; Mouser says it will stop carrying it). Digi-Key MAX98357AETE+TCT-ND $3.73, 30,936. LCSC C910544.
- TQFN-16 3 × 3, EP. 2.5–5.5 V supply (run from VBAT). 3.2 W into 4 Ω; ~1 W into 8 Ω at 3.7 V. THD+N 0.013 %.
- Pins (KiCad symbol): 1 DIN · 2 GAIN_SLOT · 3 GND · 4 SD_MODE · 7/8 VDD · 9 OUTP · 10 OUTN · 11/15 GND · 14 LRCLK · 16 BCLK · 17 EP (GND) · 5/6/12/13 NC.
- Gain: GAIN_SLOT to GND = 12 dB, to VDD = 6 dB, open = 9 dB, 100 k to GND = 15 dB, 100 k to VDD = 3 dB. SD_MODE high = left channel; low = shutdown.

### Same Sky CMS-151125-078L100 — speaker
- Mouser 490-CMS151125078L100, $2.96, 597 (Verified). Variants: -078S-67 spring contacts $2.25 (890); -078SP-67 solder pads $2.99 (1,392); -078L100A-67 wire + Molex 51021 $3.15 (796).
- **15 × 11 × 2.5**, 8 Ω, 0.7 W rated / 1.0 W max, 88–94 dB SPL (91 typ), resonance 800–1,200 Hz in a 1 cc enclosure, 100 Hz–20 kHz, IP67 front, PEEK cone, NdFeB magnet (Verified, datasheet).
- Polarity: cone moves forward with positive DC on "+".
- L100 = 32 AWG UL1571 wire leads, no connector. [Datasheet](https://www.mouser.com/datasheet/3/6118/1/cms-151125-078x-67.pdf).

### Microchip MCP73831T-2ACI/OT — charger
- Mouser 579-MCP73831T-2ACIOT, $0.76, 116,042 (Verified). LCSC C424093. SOT-23-5, 4.20 V, 15–500 mA set by R_PROG (2 kΩ → 500 mA), 3.75–6 V input.

### Diodes AP7361C-33E-13 — 3.3 V LDO (v0.2 uses the SOT-223 'E' part)
- Mouser 621-AP7361C-33E-13, $0.52, 733 in stock (2026-09-30). 1 A, SOT-223. Pinout (Verified, Diodes datasheet pin table): 1 IN, 2 GND (tab), 3 OUT — matches KiCad `AP7361C-33E`. The earlier 'ER' (SOT-223R) variant has a different pin order and is **not** used.
- Chosen because TI TLV75733PDBVR (1 A, SOT-23-5, 25 µA Iq, $0.36) had 0 stock until Dec 2026.

### GCT USB4105-GF-A — USB-C receptacle
- Mouser 640-USB4105-GF-A, $0.80, 420,427; Digi-Key 2073-USB4105-GF-ADKR-ND $0.80, 121,048 (Verified). USB 2.0, 16 contacts, top mount, right angle, 5 A.
- Footprint: KiCad `Connector_USB:USB_C_Receptacle_GCT_USB4105-xx-A_16P_TopMnt_Horizontal` (Library).

### ST USBLC6-2SC6 — USB ESD
- Mouser 511-USBLC6-2SC6, $0.49, 81,014 (Verified). LCSC C7519. SOT-23-6, 5.25 V working, 3.5 pF, 15 kV.

### C&K PTS810 SJM 250 SMTR LFS — front soft keys (v0.2)
- Mouser $0.52, 30,244 in stock (2026-09-30). 4.2 × 3.2 mm, **2.5 mm tall**, top-actuated, 250 gf (the "SJM 250" variant), SPST-NO, −40 to +85 °C.
- Footprint: KiCad `Button_Switch_SMD:SW_SPST_PTS810`. Mounted rotated 90° on the board so the USB-C receptacle's NPTH pegs (on the back) clear its pads.

### Alps SKRTLAE010 — side buttons
- Mouser 688-SKRTLA, $0.34, 2,396; Digi-Key ~$0.34, 432 (Verified). LCSC C110293.
- **4.5 × 3.55 × 3.3**, 1.6 N (160 gf), 100k cycles, −20 to +70 °C, guide bosses (NPTH pegs). Footprint: KiCad `Button_Switch_SMD:SW_Push_1P1T-MP_NO_Horizontal_Alps_SKRTLAE010` (Library). Its pegs sit 0.1 from its own pads, which triggers a hole-clearance DRC warning.

### Adafruit 258 — LiPo battery
- Mouser 485-258, $9.95, 388 (Verified). **34 × 62 × 5, 1200 mAh**, 23 g, 3.7 V nominal, JST-PH 2-pin, protection circuit (over-charge, over-discharge at 3.0 V, short). Charge at ≤ 500 mA (Verified, Adafruit).
- Other Mouser cells: TinyCircuits ASR00012 1000 mAh $9.95; TinyCircuits ASR00036 850 mAh $8.49; Adafruit 328 2500 mAh $14.95.

### JST S2B-PH-SM4-TB(LF)(SN) — battery connector
- Mouser 306-S2BPHSM4TBLFSN, $0.49, **269** (Verified). Matches the Adafruit JST-PH lead. KiCad `Connector_JST:JST_PH_S2B-PH-SM4-TB_1x02-1MP_P2.00mm_Horizontal`.
- **Check polarity:** Adafruit's JST-PH pinout differs from some other vendors' batteries.

### Lite-On LTST-C191KGKT — LED
- Mouser 859-LTST-C191KGKT, $0.15, 1.19 M (Verified). 0603, green 571 nm, 2 V, 20 mA, 35 mcd.

---

## Mono build (v0.1) parts not reused

| Part | Data |
|---|---|
| Sharp LS027B7DH01A | 2.7" 400 × 240 memory LCD, 1-bit. Pins 1 SCLK, 2 SI, 3 SCS, 4 EXTCOMIN, 5 DISP, 6 VDDA, 7 VDD, 8 EXTMODE, 9 VSS, 10 VSSA (Verified). 5 V panel (VDD/VDDA). Module ~62.8 × 42.82 × 1.6. Hirose FH12-10S-0.5SH connector. |
| Raytac MDBT50Q-1MV2 | nRF52840 module, 10 × 15.5 × 2.05, KiCad `RF_Module:Raytac_MDBT50Q`, 61 pads. SparkFun WRL-21605 $8.95; TME $6.92–9.45; not stocked at Digi-Key/Mouser. |
| Winbond W25Q128JVSIQ | 16 MB NOR, SOIC-8 208 mil. Digi-Key $2.88 (85,500); Mouser $3.94. LCSC C97521. |
| TI TPS61220DCKR | Adjustable boost, SC-70-6. LCSC C15421. Vout = 0.5 × (1 + R1/R2). |
| TI SN74LV1T34DCKR | Single buffer with TTL-level inputs (3.3 → 5 V), SC-70-5. LCSC C78541. |
| Torex XC6220B331MR-G | 700 mA LDO, 8 µA Iq, SOT-23-5. LCSC C86534. |
| Sunlord SWPA3012S4R7MT | 4.7 µH, 3 × 3 × 1.2. LCSC C83415. |
| ST LIS3DHTR | Accelerometer, LGA-16 3 × 3. Mouser $1.94 (150, then 0); Digi-Key 0. |
| Bosch BMP280 | Barometer, LGA-8 2 × 2.5. LCSC C83291; Digi-Key 0 stock / 10k MOQ. |
| Ole Wolff OWS-111535W50A-8 | 11 × 15 × 3.5 speaker, 8 Ω 1 W, 100 Hz–20 kHz, Digi-Key (price not shown). |
| Jauch LP603048JK+PCM / LP103048JU+PCM | 6 × 30 × 48 (~850 mAh) / 10 × 30 × 48 (~1500 mAh) LiPo with protection and wires, Digi-Key. |

## Open items
1. ~~Taoglas land pattern~~ — done from the §6.5 footprint drawing (12 mm part).
2. ~~BMP581 pad numbering~~ — done from Bosch's own §8.1–8.2 drawings (SparkFun's package not used).
3. BL652 ANT SoftDevice (firmware stage): the nRF52832 has 512 KB flash / 64 KB RAM; Nordic's combined ANT+BLE SoftDevice S332 needs roughly a third of that, so it fits, but the ANT SoftDevice licence terms (free for evaluation/hobby, key required for commercial products) must be read before any public firmware release.

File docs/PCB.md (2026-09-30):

# PCB (v0.2)

Status: **routed, DRC clean, schematic netlist-matched, fab files exported.** Not yet built. Review checklist and what is still unverified: [`pcb/README.md`](../pcb/README.md).

## Stack-up and rules

- 4 layers, 1.0 mm FR-4: F.Cu (front, display side) / In1 GND plane / In2 +3V3 plane / B.Cu (back, battery side). Order as JLCPCB **JLC04101H-3313** (or any 1.0 mm 4-layer).
- Outline 46 × 86.4 mm, 4 mm corner radius. M2 plated holes at (6.5, 6.5), (45.5, 6.5), (6.5, 85.9), (45.5, 85.9).
- Rules: 0.15 mm clearance / 0.2 mm default track, vias 0.5 / 0.3 mm, 0.3 mm copper to edge, min drill 0.2 mm (only the ESP32 thermal-pad vias). Power: VBAT / BATT+ / VBUS 0.5 mm, +3V3 0.4 mm, backlight 0.4 mm, speaker 0.3 mm.
- RF_IN (patch → GPS) is a 4 mm, 0.2 mm-wide trace on F.Cu directly over the In1 ground plane (≈ 50 Ω on a 0.1 mm prepreg; check with the JLC impedance calculator for the stack-up you order).
- Board coordinates: KiCad x right, y down, seen from the front. Enclosure CAD: `cad_x = x`, `cad_y = 92.4 − y`.

## Pipeline (all scripted; `tools/build_all.sh` runs it)

```bash
cd pcb
python3 build_pcb.py                       # design.py -> placed.kicad_pcb (+ local footprints, keep-outs, RF feed)
python3 check_place.py                     # courtyards, enclosure height zones, keep-outs, holes vs. other side
python3 fanout.py placed.kicad_pcb fanned.kicad_pcb      # escapes + a via for every GND / +3V3 pad
python3 autoroute.py fanned.kicad_pcb routed.kicad_pcb 60  # Freerouting 1.9 (headless) round trip
python3 finish.py routed.kicad_pcb opencycle.kicad_pcb   # rules, planes, pours, stitching, clean-up, DRC
python3 gen_schematic.py && python3 check_netlist.py     # schematic from design.py; netlist == board
python3 export_fab.py                      # Gerbers, drill, BOMs, CPL, assembly PDFs -> pcb/fab/
python3 export_viewer.py opencycle.kicad_pcb             # viewer/pcb.json + textures
```

| Script | What it does |
|---|---|
| `design.py` | Every part: symbol, footprint, side, position, rotation, pin → net, MPN, height. Keep-outs, height zones, rules. |
| `lib/gen_symbols.py`, `lib/gen_footprints.py` | Local symbols/footprints KiCad doesn't ship: BMP581 (from Bosch's drawing), Taoglas 12 mm patch (from Taoglas's drawing), speaker pads. |
| `check_place.py` | Fails on courtyard overlaps, parts too tall for the enclosure zone they sit in, parts in antenna keep-outs, screw/standoff clashes, through-holes under parts on the other side. |
| `fanout.py` | Stubs + vias from every plane pad to its plane, via-in-pad for the LDO tab, escapes for boxed-in pads (BMP581 I²C, backlight anode), stitching vias under the patch. |
| `autoroute.py` + `ses_import.py` | DSN export with net classes, Freerouting headless, SES import without the KiCad GUI. |
| `finish.py` | Re-applies the design rules, pours, removes dangling autorouter pieces, stitches outer GND pours to In1 on a 2.5 mm grid and into every island, DRC with `rules.kicad_dru`. |
| `gen_schematic.py`, `check_netlist.py` | Label-connected schematic from the same table; KiCad netlist export compared pin-by-pin with the board. |
| `export_fab.py`, `sourcing.py` | Fab package and distributor BOM (prices, links, stock). |

## Placement

- **Front, top band (above the display):** 12 mm patch (centre-right), MAX-M10S left of it (short RF feed), charge LED and light sensor on the right under lens-mask windows.
- **Front, under the display (≤ 2.15 mm tall; ≤ 1.3 mm under the folded FFC):** display connector J3 in the centre, LDO + caps on the left, backlight FET and ballasts on the right.
- **Front, bottom band:** three PTS810 keys under the key caps (turned 90° so the USB-C locating pegs clear them).
- **Back, top:** ESP32 module (antenna at the right edge) and BL652 (antenna at the left edge), each with a keep-out on every layer.
- **Back, middle (over the battery, ≤ 3.3 mm):** passives, Tag-Connect pads, side switches at the edges, BMP581 at the right edge beside the case vent.
- **Back, bottom:** USB-C (mouth 0.9 mm past the board edge), ESD, charger, reverse-battery FET, JST-PH socket, amp and speaker pads.

## Verification results (committed with the board)

| Check | Result | File |
|---|---|---|
| Placement (courtyards, heights, keep-outs, holes) | placement OK | `pcb/check_place.py` |
| KiCad DRC | **0 errors, 0 unconnected**, 6 warnings (ESP32 footprint deliberately differs from the library: keep-out replaced; 4 × module silk clipped at the board edge; 1 redundant BMP581 escape via on SDA, connected on B.Cu only, harmless) | `pcb/drc_report.txt` |
| Schematic vs. board | **netlist match: 55 nets, 282 pin connections** | `pcb/check_netlist.py` |
| ERC (KiCad 9 CLI) | **0 errors**; 3 explained warnings (BMP581 SDO/INT tied to GND, amp thermal pad) + library-table notices | `pcb/erc_report.txt` |
| Real parts vs. enclosure (3D) | **board fit OK** (67 parts, all three case styles) | `cad/board_fit.py` |

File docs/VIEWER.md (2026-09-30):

# 3D viewer

Two static pages (three.js r160 from jsDelivr via an import map), sharing the same generated assets:

- `viewer/index.html` — the studio viewer: finishes, variants, exploded view, PCB net explorer, every Lucent screen.
- `viewer/product.html` — the product page: a scroll-driven tour (hero → shells → exploded → board → back) with the device in a sticky studio stage, the live Lucent UI with working soft keys, specs and build steps. Serve the folder and open `/product.html`.

Inputs (all generated, don't hand-edit):
- `meshes.json` — base64 STL of the enclosure and mechanical parts (`tools/export_meshes.py`).
- `pcb.json` — every board part (position, size, side, height, nets, MPN), tracks, vias and pads (`pcb/export_viewer.py`, from the routed `pcb/opencycle.kicad_pcb`).
- `pcb_{front,back}_{color,orm}.png` — board textures at 24 px/mm: solder mask, copper under mask, ENIG pads, silkscreen. ORM = (occlusion, roughness, metalness).
- `ui/screens_color.js` + `ui/fonts/` — the Lucent screen renderer, drawn onto the 3D display and the "On-device screens" section.

Rendering notes:
- ACES tone mapping, RoomEnvironment reflections, soft shadow on a shadow-catcher floor.
- Printed parts use a patched `MeshPhysicalMaterial` that perturbs normals with 0.2 mm layer lines on walls and 45° top-skin lines on flat faces.
- The display is emissive (not tone-mapped) so its colours match the renderer.
- Board components are procedural boxes sized from each footprint's pads + fab outline, with heights from `design.py`.
- URL hashes: `#board`, `#exploded` open those views directly.

Serve locally: `python3 -m http.server -d viewer 8000`.

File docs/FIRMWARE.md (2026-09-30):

# Firmware plan (not started)

The owner is finishing the UI design first; nothing here is implemented yet.

## Stack

- **ESP32-S3 (main MCU):** ESP-IDF (FreeRTOS) + **LVGL 9**. ST7789 over SPI (FSPI IO_MUX pins, 40–80 MHz), two 150 KB frame buffers in PSRAM, partial refresh. Port `viewer/ui/screens_color.js` screen by screen following `docs/UI.md` (Lucent).
- **Storage:** LittleFS on the module's 16 MB flash (app partitions + data). Rides as FIT (Garmin FIT SDK), routes as GPX, map tiles pre-rendered by the phone app.
- **GPS (MAX-M10S):** UBX over UART (IO38 RX / IO39 TX), 1 Hz while riding; software backup when stopped; EXTINT on IO48 to wake it.
- **ANT+ / BLE sensors:** the **BL652 (nRF52832)** runs Nordic's SoftDevice S332 (ANT + BLE) as a sensor bridge and streams parsed data (HR, power, cadence, speed, radar) to the ESP32 over UART (IO41 RX / IO42 TX, reset IO47). Programmed over SWD through Tag-Connect J4. ANT licence terms must be checked before publishing.
- **BLE to the phone + Wi-Fi sync:** ESP32 native radios.
- **Sensors:** BMP581 (I²C 0x46, keep INT disabled — the pin is grounded) for altitude/climb; LTR-303 (0x29) for backlight auto-dimming.
- **Audio:** I²S (IO15/16/17) to the MAX98357A, amp enable on IO3; short PCM clips for alerts and turn prompts.
- **Keys:** five inputs with 10 k pull-ups; RTC-capable GPIOs so any key can wake from deep sleep. Holding the left key (IO0) at reset enters the ROM bootloader.
- **Power:** VBAT_SENSE (IO1, ÷2) and VBUS_SENSE (IO2, ÷2) on ADC1; backlight PWM on IO21 with a duty cap from VBAT_SENSE.

Full pin map: [`HARDWARE.md`](HARDWARE.md#esp32-s3-pin-map).

## Bring-up order

Follow [`instructions/05-bring-up.md`](../instructions/05-bring-up.md): rails → ESP32 over USB → I²C scan → display → GPS NMEA → BL652 over SWD → audio → keys → charging.

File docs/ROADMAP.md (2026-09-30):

# Roadmap

## v0.2 prototype (now)
- [x] Colour build parts chosen, pinouts verified against datasheets, all parts priced with links.
- [x] Enclosure v0.2 (52 × 92.4 × 17 mm), fit-checked against the real board; print files.
- [x] Board routed, DRC clean, schematic generated + netlist-matched, ERC clean; Gerbers, BOM, CPL.
- [x] Screen design language (Lucent) with 10 screens and an LVGL recipe.
- [ ] Order parts + boards, print, assemble, bring up ([instructions/](../instructions/README.md)).
- [ ] Measure: GPS fix / C/N0 in the case, BLE + Wi-Fi range, backlight current and temperature, battery life.

## Firmware (after the UI is final)
- [ ] ESP-IDF + LVGL: display, ride screen, page model, soft-key bar.
- [ ] GPS + FIT logging; BMP581 altitude; light-sensor backlight.
- [ ] BL652 ANT+/BLE bridge firmware + UART protocol.
- [ ] Map tiles and navigation; audio prompts.

## App
- [ ] Route import, tile generation, ride sync (React Native or Web Bluetooth).

## v0.3 ideas
- Power-path charger (run from USB without cycling the battery).
- Pin-fed or larger GPS patch if reception in the case is weak.
- Transflective display option if one becomes buyable in small quantities.

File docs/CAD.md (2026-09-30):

# Enclosure CAD (v0.2)

All dimensions: [`cad/params.py`](../cad/params.py). Geometry: [`cad/model.py`](../cad/model.py). Checks: [`cad/check_fit.py`](../cad/check_fit.py) (placeholder assembly) and [`cad/board_fit.py`](../cad/board_fit.py) (every real board part vs. the case). Print files: [`print/`](../print/README.md).

```bash
cd cad
python3 model.py                                   # out/step/*.step, out/stl/*.stl, full assemblies as STEP
python3 check_fit.py                               # must print OK for standard / aero / rugged
python3 board_fit.py ../pcb/opencycle.kicad_pcb    # must print "board fit: OK"
python3 ../tools/export_print.py                   # print-oriented STLs + STEP into print/
```

Body: **52 × 92.4 × 17 mm**, 7 mm plan radius, Garmin quarter-turn boss on the back.

## Stack, back to front (z, mm)

| z | Layer |
|---|---|
| −3.0 → 0.0 | Garmin quarter-turn boss (approximate — verify against a known mount before relying on it) |
| 0.0 → 1.5 | Back shell floor (1.0 mm under the battery pocket), speaker grille slots |
| 1.1 → 6.1 | LiPo 34 × 62 × 5 mm (Adafruit 258) in a 0.5 mm floor pocket |
| 1.8 → 4.3 | Speaker 15 × 11 × 2.5 mm (fires through the floor grille) |
| 6.75 → 10.0 | Back-side parts (ESP32 module 3.25 mm tall over the battery, 0.65 mm clearance) |
| 10.0 → 11.0 | PCB |
| 11.0 | Case split line with the O-ring |
| 11.0 → 13.0 | Front-side parts (≤ 2.15 mm under the display, ≤ 1.3 mm under the folded FFC); key switches 2.5 mm |
| 12.95 → 13.45 | Foam ring |
| 13.45 → 16.0 | Newhaven 2.4" TFT (2.55 mm) |
| 16.0 → 17.0 | Cover lens, black mask on the underside with windows for the screen, light sensor and charge LED |

## Front layout (CAD coordinates, y up from the bottom edge)

- Display outline x 4.6 → 47.4, y 16.89 → 76.8 (top band 15.6 mm); active area 36.72 × 48.96 mm.
- 12 mm GPS patch centre (27.2, 83.0), tucked under the lens ledge in a relief pocket in the bezel.
- Front keys: 9 mm caps at x 13.76 / 26.0 / 38.24, y 8.7, 0.8 mm proud; each sits on a PTS810 switch with a retaining flange under the 1.5 mm bezel face.
- Side buttons at y 58.4 (left: power/back, right: menu); switch stems 0.1 mm from the plungers.
- USB-C mouth 2.1 mm behind the case face with a 12.8 × 7.0 × 1.9 mm counterbore so any USB-C plug overmold reaches.
- Barometer vent: 0.8 mm hole in the right wall at y 44 (cover with a breathable PTFE sticker).

## Variants

- **Standard:** 1.5 mm back-edge radius, 1.2 mm front radius.
- **Aero:** 4.5 mm back-edge radius, 2.5 mm front radius.
- **Rugged:** standard shells + 2 mm TPU bumper with corner guards, 0.6 mm lens lip, knurled TPU button covers.

Printing: see [`print/README.md`](../print/README.md).

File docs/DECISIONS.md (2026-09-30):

# Decisions and open questions

Append new entries at the bottom. Format: date — decision — why.

## Decided

- 2026-09-29 — Build a custom device rather than buy (a GEOID CC700 Pro is ~$70 and a DIY unit costs more). Why: open-source project and learning; target long battery life and open firmware as differentiators.
- 2026-09-29 — Sharp 2.7" memory LCD (1-bit) for v1. Why: sunlight-readable, microwatt power, proven in hobby projects. Colour MIP (JDI) is the v2 candidate.
- 2026-09-29 — nRF52840 module (Raytac MDBT50Q) for BLE + ANT+. Why: pre-certified, one chip for both sensor protocols.
- 2026-09-29 — u-blox MAX-M10S GPS. Why: lowest-power multi-constellation receiver in its class.
- 2026-09-29 — 16 MB QSPI flash instead of microSD. Why: no card slot to seal in a printed case.
- 2026-09-29 — Add I²S speaker (MAX98357A + 11 × 15 mm speaker, ~$4). Cost: battery narrowed from 34 to 30 mm.
- 2026-09-29 — 4-layer board with GND and 3V3 planes. Why: RF parts and routing density.
- 2026-09-29 — Source from Digi-Key/Mouser where possible. Swaps agreed: BMP280 → LPS22HH, HRO USB-C → GCT USB4105, Sunlord inductor → Taiyo Yuden NR3015, GPS patch → Taoglas DSGP.1575.15.4.A.02.

## Open (as of 2026-09-29, v0.1; superseded by the v0.2 decisions below)

- Module source: MDBT50Q from SparkFun (no board change) vs u-blox NINA-B306 (Digi-Key/Mouser, needs a new footprint).
- Battery: 6 mm (~850 mAh, 16 mm case) vs 8 mm (~1100 mAh, current) vs 10 mm (~1500 mAh, +2 mm case).
- Sharp LS027 availability (Digi-Key showed 0 stock / 28-week lead). Fallbacks: Mouser, Tindie, AliExpress.
- Assembly: JLCPCB PCBA (needs LCSC part numbers) vs hand/US assembly from Digi-Key parts.
- Front light for night riding.
- License (likely CERN-OHL-S hardware + MIT software).

- 2026-09-30 — Colour display direction (candidate v0.2): ESP32-S3-WROOM-1-N16R8 + BL652 (nRF52832) as ANT+ coprocessor + Newhaven NHD-2.4-240320AF-CSXP IPS TFT. Parts sourced from Mouser + Digi-Key only; see sourcing/bom-colour-v0.2.md (since replaced by sourcing/bom-v0.2.md). Why: colour UI, Wi-Fi, LVGL headroom; ANT+ kept via coprocessor. Cost: ~10–22 h battery vs ~100 h.
- 2026-09-30 — Front layout: buttons on the front, under the screen; keep a 12 mm ceramic patch GPS antenna under the top band (~15 mm top border, ~52 × 92 mm body) rather than a chip antenna. Why: best GPS reception; the owner accepted the taller top band. Power button on the left side. Button arrangement still being chosen from the D1–D4 mockups.
- 2026-09-30 — Controls: three unlabelled front soft keys under the screen, with context labels drawn in a bar at the bottom of the display (e.g. ride: Lap / Page / Start; map: zoom out / re-centre / zoom in), plus two side buttons (left: power/back, right: menu). Five switches total.
- 2026-09-30 — Colour build (v0.2) is the design going forward: ESP32-S3-WROOM-1-N16R8 + BL652 (ANT+/BLE) + MAX-M10S + Newhaven NHD-2.4-240320AF-CSXP. The mono v0.1 files stay in git history only. Why: owner chose colour + Wi-Fi; ANT+ kept via the BL652.
- 2026-09-30 — Screen UI language "Lucent" (glass cards over deep navy, Inter, colour only for meaning) replaces the first colour pass "Meridian". Why: owner found Meridian too Tron-like; asked for Apple Liquid Glass but more functional. Glass is faked without blur so LVGL can reproduce it 1:1 (docs/UI.md §5).
- 2026-09-30 — GPS antenna: Taoglas DSGP.1575.12.4.A.02 (12 × 12 × 4 mm SMT patch, Digi-Key) under a 15.6 mm top band, fed by a 4 mm trace from the MAX-M10S next to it. Why: best reception that still fits the band; the land pattern comes from the Taoglas datasheet §6.5.
- 2026-09-30 — Front soft keys: C&K PTS810 top-actuated switches (4.2 × 3.2 × 2.5 mm), mounted rotated 90° so the USB-C receptacle's locating pegs clear the centre switch. Side buttons stay Alps SKRTLAE010.
- 2026-09-30 — Radios at opposite edges: ESP32 antenna at the right edge, BL652 antenna at the left edge, each with a copper keep-out on all layers; the GPS patch sits between them at the top.
- 2026-09-30 — Protection and power: P-FET (DMG2305UX) reverse-battery protection, 1 A AP7361C LDO, MCP73831 500 mA charger, backlight from VBAT through four 33 Ω 0603 ballasts and a PWM FET (≤ 45 mA per LED worst case, within the panel's 200 mA total).
- 2026-09-30 — Battery: Adafruit 258 (1200 mAh, 34 × 62 × 5 mm, protected, JST-PH) in a 0.5 mm floor pocket. Connector wired pin 1 = −, pin 2 = + (common JST-PH LiPo convention); Q2 blocks a reversed cell.
- 2026-09-30 — Programming: ESP32 over native USB-C; BL652 over SWD with a Tag-Connect TC2030-NL footprint (no connector to buy per board). A second TC2030 footprint carries the ESP32 UART0/EN/IO0 for recovery.
- 2026-09-30 — Board process: 4 layers (In1 GND, In2 +3V3), 1.0 mm, 0.15 mm clearance, 0.5/0.3 mm vias, 0.2 mm drills in the ESP32 thermal pad. Routed with Freerouting after a scripted fan-out; DRC 0 errors / 0 unconnected; schematic generated from the same table and netlist-checked against the board.
- 2026-09-30 — Sourcing: two vendors. Mouser for almost everything, Digi-Key for the BMP581, the 12 mm patch and the DMG2305UX. JLCPCB for bare boards (+ stencil); assembly by hand/hot plate or by a US assembler from the distributor BOM (JLC PCBA possible via MPN matching, not verified part by part).

## Open (as of 2026-09-30, after the v0.2 board)

- First prototype bring-up: nothing is built yet. See instructions/05-bring-up.md for the checklist.
- GPS/Wi-Fi/BLE antenna performance is not measured; the patch ground plane is far smaller than Taoglas's 50 × 50 mm test board.
- Battery polarity: check the Adafruit lead against J2 with a meter before first plug-in (Q2 protects either way).
- License (CERN-OHL-S for hardware + MIT for software suggested).
- Front light for night riding is not needed with the backlit TFT; dropped.

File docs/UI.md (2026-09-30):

# On-device UI — "Lucent"

**Status:** design reference. It renders in the browser only; there is no firmware yet. Pixel values here were checked against the renderer, not against a real panel.

- **Source of truth:** [`viewer/ui/screens_color.js`](../viewer/ui/screens_color.js). The 3D viewer and the screenshots below both render from it, and the firmware (LVGL 9 on the ESP32-S3) is meant to port it 1:1. If this document and the code disagree, the code wins, so fix the document.
- **Screenshots:** [`docs/ui/`](ui/). `overview.png` shows every screen in a device frame with the three front keys. Each screen also has `<id>.png` (1×) and `<id>@3x.png` (nearest neighbour). Every frame is quantised to RGB565 before export, so gradient banding in the PNGs is what the panel will show.
  - Regenerate: serve the repo root with `python3 -m http.server 8765`, then run `node docs/ui/shoot.mjs`. This needs Playwright with Chromium, installed locally or globally.
  - [`docs/ui/harness.html`](ui/harness.html) sets the frame time used for each screen.
  - [`docs/ui/make_fonts.py`](ui/make_fonts.py) rebuilds the bundled fonts.
- **Replaces "Meridian".** The earlier neon, chamfered language was dropped after owner review ("like Tron… trying way too hard"). The API, screen ids, soft-key mapping and data model are unchanged.
- The monochrome renderer for the old Sharp memory LCD, `viewer/ui/screens.js`, is legacy.

overview

## Display facts

| | |
|---|---|
| Panel | 2.4" IPS TFT, ST7789, 1200 nit |
| Resolution | **240 × 320 px, portrait**, ≈ 166 ppi (1 px ≈ 0.153 mm) |
| Colour | RGB565 (16-bit) |
| Frame buffer | 150 KB. Use two partial draw buffers (240 × 40) in internal RAM. Keep the wallpaper, fonts and A8 bitmaps in flash or PSRAM |
| Input | 3 unlabelled front keys under the screen (L / C / R), a left side button (power/back) and a right side button (menu) |

## 1. Design language: Lucent

*Frosted glass floating over deep colour.* Lucent borrows the calm of Apple's Liquid Glass and watchOS widgets, and builds it only from things a microcontroller can draw cheaply and honestly.

Principles:

1. **Function first.** Every data page has one hero number (80 px, ≈ 8.9 mm cap height) and a small set of tiles. Values are white, labels are grey, and units are dimmer still. A rider should be able to read the screen in half a second at speed and in sunlight.
2. **Glass, not glow.** Content sits on translucent rounded panels over a soft, dark backdrop. Depth comes from layering, a fill gradient, a 1 px inner edge and a 1 px top highlight. Nothing is blurred at runtime and nothing glows.
3. **Colour means something.** The chrome is neutral. Chroma appears only for effort zones, gradient, the route and selection (one blue accent), and status (good / warn / bad). The one ambient use of colour is the **zone light**, a soft wash in the current zone colour behind the glass. It is still information: the whole page warms as your effort climbs.
4. **Soft geometry.** Large radii (18 px cards, 14 px tiles, full capsules for keys, chips and gauges). No chamfers, ticks or brackets.
5. **Quiet motion.** Things slide and settle without bounce. The only loop is the heartbeat, which beats at your real heart rate.
6. **Keys are glass pills** centred over the physical keys. The primary action is the one near-white pill.

## 2. Palette

Values are snapped to RGB565 (truncation, the same as `lv_color_to_16`). The hex column is what the panel shows. Put them in one `theme.h` table. Where translucency is used, it is written as an opacity (`opa`) on top of these colours. It is never baked into a new colour.

| Token | Hex | RGB565 | Use |
|---|---|---|---|
| `night` | `#081429` | `0x08A5` | backdrop top; lap sheet base |
| `deep` | `#000810` | `0x0042` | backdrop bottom; scrim |
| `glowA` | `#293C84` | `0x29F0` | backdrop cool light (baked, top left) |
| `glowB` | `#084952` | `0x0A4A` | backdrop teal light (baked, bottom right) |
| `ink` | `#080C10` | `0x0862` | label on the prominent key, icon on light tiles, knob ring |
| `text` | `#F7F7FF` | `0xF7BF` | numerals, primary text, prominent key fill |
| `text2` | `#ADB2C6` | `0xAD98` | labels, secondary text |
| `text3` | `#6B7584` | `0x6BB0` | units, captions, inactive |
| `glass` | `#FFFFFF` | `0xFFFF` | glass fill / edge / highlight (always with an opa) |
| `mapGlass` | `#101821` | `0x10C4` | card fill over the live map (opa 78–84 %) |
| `accent` | `#0886FF` | `0x0C3F` | route ahead, selection, progress, rider |
| `good` | `#31D35A` | `0x368B` | on target, faster, GPS OK |
| `warn` | `#FF9E08` | `0xFCE1` | off target, slower, low battery |
| `bad` | `#FF4539` | `0xFA27` | compass north, errors |
| `z1` | `#8C96A5` | `0x8CB4` | Z1 recovery |
| `z2` | `#0886FF` | `0x0C3F` | Z2 endurance |
| `z3` | `#31D35A` | `0x368B` | Z3 tempo |
| `z4` | `#FFD708` | `0xFEA1` | Z4 threshold |
| `z5` | `#FF9E08` | `0xFCE1` | Z5 VO2 max |
| `z6` | `#FF4539` | `0xFA27` | Z6 anaerobic |
| `z7` | `#BD59F7` | `0xBADE` | Z7 neuromuscular |
| `mapBg` / `road` / `roadMajor` | `#181821` / `#292C39` / `#39414A` | `0x18C4` / `0x2967` / `0x3A09` | map ground and streets |
| `water` / `park` | `#102039` / `#102821` | `0x1107` / `0x1144` | map areas |
| `routeDone` / `routeEdge` | `#5A6173` / `#083C84` | `0x5B0E` / `0x09F0` | travelled route; 2 px darker edge of the route ahead |

The zone colours follow Apple's dark-mode system colours, so they are familiar and hold up against the dark backdrop. The same colours carry across scales:

- HR zones use `z1 z2 z3 z5 z6`.
- Gradient uses `z3` (< 3 %), `z4` (< 6 %), `z5` (< 9 %), `z6` (< 12 %) and `z7` (steeper).
- The accent is the same blue as `z2`. The two never compete on one screen: the map has no zones, and zone screens use no accent.

## 3. Type

One OFL family: **Inter** (rsms/inter). It is a neutral grotesk close to SF Pro in spirit.

- **Inter Display** (optical size 32) is used for numerals ≥ 20 px.
- **Inter** (optical size 14) is used for text.
- Static TTFs are built from the Google Fonts variable font by `docs/ui/make_fonts.py`, which:
  - instances the two optical sizes at weights 500 and 600,
  - **freezes tabular figures into the cmap**, so changing numbers never jitter (lv_font_conv does not apply OpenType features), and
  - subsets the fonts to the ranges below.
- The files live in `viewer/ui/fonts/`, with the licence in `OFL-Inter.txt`.
- Letter-spacing maps to LVGL `text_letter_space`. Negative values are fine.

| Token | Face | Weight | px | Tracking | Use |
|---|---|---|---|---|---|
| `hero` | Inter Display | 600 | 80 | −2 | ride speed, heart rate |
| `heroDec` | Inter Display | 600 | 44 | −1 | decimal part of the hero (".3"), on the same baseline |
| `xl` | Inter Display | 600 | 52 | −1.5 | lap time, summary distance |
| `timer` | Inter Display | 600 | 34 | −0.8 | workout countdown inside the ring |
| `lg` | Inter Display | 600 | 30 | −0.5 | power value, turn distance |
| `md` | Inter Display | 600 | 24 | −0.5 | tile values (also 20–21 px variants for 3-up tiles) |
| `sm` | Inter | 600 | 17 | 0 | compact values (lap stats, climb title) |
| `title` | Inter | 600 | 15 | 0 | list items, workout step |
| `body` | Inter | 500 | 13 | 0 | units after big numbers, secondary text |
| `label` | Inter | 600 | 11 | +0.3 | UPPERCASE field labels |
| `key` | Inter | 600 | 12 | 0 | soft-key labels (Title Case) |
| `caption` | Inter | 500 | 10–11 | 0 | axes, sub-lines, time-in-zone rows |

lv_font_conv (4 bpp), for example:

```bash
# numerals only (hero, heroDec, xl, timer, lg): digits . : − + % and space
lv_font_conv --bpp 4 --size 80 --no-compress --format lvgl --font InterDisplay-SemiBold.ttf \
  -r 0x20,0x25,0x2B,0x2D-0x3A,0x2212 -o font_hero_80.c
# text faces: printable ASCII plus · × – — ’ … • ← ↑ → ↓ − ° and NBSP
lv_font_conv --bpp 4 --size 13 --format lvgl --font Inter-Medium.ttf \
  -r 0x20-0x7E,0xA0,0xB0,0xB7,0xD7,0x2013,0x2014,0x2019,0x2022,0x2026,0x2190-0x2193,0x2212 -o font_body_13.c
```

Budget: about 14 fonts. The numeral-only faces are small (the 80 px face is about 25 KB at 4 bpp), and the text faces run 8–20 KB each. All of them fit in flash (XIP).

## 4. Spacing, radii, layout grid

| Token | Value | Notes |
|---|---|---|
| grid | 4 px | all offsets are multiples of 2, most of 4 |
| `margin` | 8 px | screen edge to card; content column x 8..232 (224 px) |
| `gutter` | 6 px | between tiles; two-up tile = 109 px, three-up = 70/71/71 px |
| `pad` | 12 px | card inner padding (text starts at card x + 12) |
| status bar | y 0..22 | clock at x 14 baseline 15; page dots centred at y 8; battery at x 203 |
| content | y 24..288 | nothing is drawn below y 288 except the keys |
| key area | y 292..320 (`BAR` = 28) | pills at y 295, 70 × 22, centred on x 40 / 120 / 200 |
| `R.card` | 18 | hero and large cards (sheet 22) |
| `R.field` | 14 | tiles, list rows (`R.row`) |
| `R.pill` | 11 | keys (= half height); chips and gauge segments are capsules too |
| `R.tile` | 9 | 26–28 px icon tiles |

## 5. Glass in LVGL (how every effect is built)

LVGL 9 has no backdrop blur, and we do not want one: it would mean reading back the frame buffer and running a multi-pass filter on every refresh. Lucent fakes glass with three honest layers.

### 5.1 Backdrop, pre-rendered and already soft

The backdrop is a full-screen `lv_image` of a 240 × 320 RGB565 bitmap in flash (150 KB, `LV_COLOR_FORMAT_RGB565`). The bitmap is:

- a vertical gradient `night → deep`,
- plus two large radial lights (`glowA` at (30, 20) r 230, opa 55 %; `glowB` at (230, 300) r 210, opa 45 %),
- baked offline with a **4 × 4 ordered dither**, so the gradient does not band in 565.

The renderer bakes the same bitmap once at start-up (`bakeWallpaper`). Because the backdrop is already blurry, a translucent panel over it looks frosted: there is no detail behind it that would reveal the missing blur.

### 5.2 Zone light (ride, heart, climb, workout)

The zone light is a soft wash in the current zone colour behind the glass.

- One 240 × 200 **A8** bitmap with a radial falloff (≈ 47 KB, 1, 0.55 at 45 % radius, 0 at the edge) is drawn as an `lv_image` with `image_recolor` = zone colour and `image_opa` = 24 % (12 % on the workout page, 22 % on climb).
- Changing zone only changes a style property. The bitmap never changes.
- It is blended at runtime without dither, so expect slight banding (visible in the renders).

### 5.3 Glass panel

A glass panel is one `lv_obj` plus one child for the highlight:

```c
// recipe: GLASS.card (values from screens_color.js)
lv_style_set_radius(&st_glass, 18);
lv_style_set_bg_color(&st_glass, lv_color_white());
lv_style_set_bg_grad(&st_glass, &grad_glass);      // VER, stop0 = white opa 38 (15 %), stop1 = white opa 18 (7 %)
lv_style_set_bg_opa(&st_glass, LV_OPA_COVER);      // per-stop opa carries the translucency (LVGL 9 grad stops have opa)
lv_style_set_border_width(&st_glass, 1);
lv_style_set_border_color(&st_glass, lv_color_white());
lv_style_set_border_opa(&st_glass, 26);            // 10 %: the inner edge
lv_style_set_shadow_width(&st_glass, 0);           // no shadow on panels
// highlight child: same size, IGNORE_LAYOUT, not clickable
lv_style_set_bg_opa(&st_hi, LV_OPA_TRANSP);
lv_style_set_border_side(&st_hi, LV_BORDER_SIDE_TOP);
lv_style_set_border_width(&st_hi, 1);
lv_style_set_border_opa(&st_hi, 87);               // 34 %: the specular line along the top edge
lv_style_set_radius(&st_hi, 18);
```

If the gradient stop opacities misbehave on a given LVGL build, the fallback is a flat `bg_opa` at the average value (≈ 11 %). This loses a little depth but nothing else.

| Recipe | Fill top → bottom | Edge | Highlight | Used for |
|---|---|---|---|---|
| `card` | white 15 % → 7 % | 10 % | 34 % | hero, power, lists, profile |
| `field` | white 12 % → 6 % | 9 % | 28 % | tiles, menu rows |
| `raised` | white 26 % → 16 % | 14 % | 50 % | selected menu row |
| `key` | white 18 % → 10 % | 12 % | 40 % | soft-key pills |
| `prominent` | `text` 96 % → 90 % | — | — | primary key (ink label) |
| `map` | `mapGlass` 84 % → 78 % | white 10 % | white 26 % | cards and keys over the live map: **plain translucent fill, no blur** |
| `sheet` | `night` 100 % (opaque), then `card` on top | white 14 % | white 45 % | lap sheet (must read over anything) |

**Shadows:** only the lap sheet has one (`shadow_width 18`, `shadow_ofs_y 6`, black opa 45 %). It is drawn only while the sheet is visible. LVGL caches shadow shapes (`LV_DRAW_SW_SHADOW_CACHE_SIZE`), so set that cache to at least 22 so the sheet's corner shadow is reused while it slides.

**Corners:** LVGL radii are circular arcs, not Apple's continuous-curvature squircle. At 14–22 px on this panel the difference is sub-pixel, so we accept it.

### 5.4 Components

| Component | LVGL |
|---|---|
| **Field (tile)** | glass `field`, UPPERCASE `label` at (x+12, y+14), value baseline at y+h−8, unit after it in `body`/`text3`. An optional 3 px zone dot before the label carries meaning. The value stays white |
| **Gauge** | a row of capsule `lv_obj`s, one per zone (radius = h/2, 5 px tall, 2 px apart). The active one is at opa 100 %, the others at 40 %. The knob is a circle `lv_obj` (white, r 5.5) over an `ink` circle at 70 % (r 7). A target window is a transparent capsule with a 1.5 px white border at 85 % |
| **Ring** | `lv_arc`, width 10, `arc_rounded`, background arc white at 12 %, indicator in the zone colour |
| **Chip** | capsule 18 px tall, fill = colour at 22 %, label 11 px/600 in the colour, optional 11 px icon |
| **Key pill** | glass `key` 70 × 22 radius 11, label `key` Title Case, optional 8–10 px glyph (pause bars, −, +, ◎). The primary is `prominent` with an `ink` label |
| **Status bar** | clock 13/600 at (14, 15); page control = 5 px dots at 30 %, the current one a 14 × 5 capsule; battery = 21 × 10 rounded outline at 45 % with a level fill (warn under 20 %) |
| **Icons** | A8 bitmaps drawn with `image_recolor`, 11–26 px |

## 6. Screens

The coordinates below are for the 240 × 320 frame. Every screen reserves y 292..320 for the key pills, and content ends at y 288 or above.

### ride — keys: Lap · Page · **Pause**
- Zone light in the current power-zone colour.
- **Speed card** (8, 26, 224 × 92):
  - `SPEED` label at (20, 43); trend `↑ avg 18.9` on the right (arrow in `good`/`warn`).
  - Hero `22` + `.3` with its baseline at y 107, x 17; `mph` after it in `body`/`text3`.
- **Power card** (8, 124, 224 × 62):
  - `POWER 3S` label at y 140; zone chip (`● Z4 Threshold` in the zone colour) right-aligned.
  - `275` in `lg` with its baseline at y 167, then `W`; `104% FTP` on the right.
  - 7-zone gauge at (20, 174, 200 × 5); the axis runs from 0 to 1.6 × FTP.
- **Tiles**, 109 × 46: Heart (zone dot) at (8, 192), Cadence at (123, 192), Distance at (8, 242), Time at (123, 242).

### hr — keys: Lap · Page · **Pause**
- Zone light in the HR-zone colour.
- **HR card** (8, 26, 224 × 112):
  - Label and zone chip at y 44.
  - Hero with its baseline at y 112, then `bpm`.
  - Heart icon 24 px at (196, 66). It beats at the measured BPM (scale 1 → 1.14, opa 60 → 100 %, exp decay).
  - 5-zone gauge at (20, 122).
- **Time in zone card** (8, 144, 224 × 94): 5 rows at a 14 px pitch from y 168. Each row has:
  - the zone name (10 px),
  - a capsule bar at x 42 (110 × 6, zone colour at 55 %, the current zone at 100 %, on a white 8 % track),
  - the time right-aligned at x 196,
  - the share of the ride at x 220.
- **Tiles**: Avg at (8, 244) and Max at (123, 244), 109 × 44.

### climb — keys: Lap · Page · **Pause**
- Zone light in the current gradient colour (22 %).
- **Title row**: `Hawk Hill` (17/600) at (12, 45); `Climb 2 of 3` in `body`; `Cat 3` chip (`z5`) right-aligned at y 31.
- **Tiles** (y 54, h 52, widths 70/71/71 at x 8/84/161): Grade (gradient-colour dot), To top, Gain. Values use Display 21 px.
- **Profile card** (8, 112, 224 × 176):
  - `PROFILE` label, and `ft to go` on the right.
  - The profile spans x 20..220, y 162..256. Each segment is filled with a vertical gradient in its gradient colour (85 % → 18 %) and has a 2 px top line.
  - Ridden segments go grey (`text3`, 45 % → 8 %).
  - 1 px guides at white 6 %; the axis line at white 25 %; axis labels in `caption` at y 272.
  - Summit flag at the top right.
  - Rider: accent dot (r 7.5) with a white core (r 4.5), and a 1 px white 50 % drop line to the axis.

### map — keys: − Zoom · ◎ Centre · + Zoom (no primary)
- **Map**: full-bleed, heading-up, at k = 0.5 × zoom around the rider at (120, 200).
  - Streets are 6 px `road` and arterials 10 px `roadMajor`, with `water` and `park` areas.
  - Route ahead: 10 px `routeEdge` under 6 px `accent`. Travelled route: 6 px `routeDone`.
  - Rider puck: a white disc (r 9) with an accent core (r 6.5), and a 34 px heading cone (accent 45 % → 0, one `lv_image` A8).
- **Turn card** (8, 8, 224 × 70, `map` glass, r 20):
  - Accent tile 54 × 54 r 14 at (16, 16) with a 5 px white rounded arrow.
  - Distance in `lg` at (80, 44).
  - `Right onto` (`text2`) followed by the **street** (13/600) at y 64.
  - Clock at the top right in 11 px `text3`.
- **Scale bar** at (14, 96), with its label to the right.
- **Compass** (`map` glass disc, 32 px) at (216, 102). The red N needle rotates by −heading.
- **Bottom tiles** (`map` glass, 108 × 46) at (8, 242) and (124, 242): Speed, and `ARRIVE 8:21` (accent label) with distance to go.
- The key pills use the `map` glass recipe here, so they read over the map.

### workout — keys: Skip · Page · **Pause**
- Zone light in the target colour at 12 %, centred on the ring.
- **Header**: `STEP 4 OF 7` label and `Sweet spot` (`title`) on the left; `NEXT` and `Rest 5:00` on the right.
- **Ring** at centre (120, 116), r 50, width 10, showing interval progress:
  - `Interval 2/3` (10/600) at y 97.
  - Countdown in `timer` with its baseline at y 128.
  - `of 10:00` at y 144.
- **Target card** (8, 176, 224 × 70):
  - `TARGET 240–262 W` label; status chip on the right (`On target` in `good`, or `Push +n` / `Ease −n` in `warn`).
  - Power in `lg` with its baseline at y 222.
  - Heart value `md` with a beating icon, right-aligned.
  - Full-width gauge at y 231: neutral grey outside the window, the target colour inside it, and a white window outline.
- **Session card** (8, 252, 224 × 36): steps as rounded blocks whose height is the intensity. Past steps are white 16 %, the current one is its colour at full, and future ones are at 70 %. A 2 px white "now" line marks the position.

### status (sensors) — keys: Scan · Page · **Pair**
- One grouped glass list (8, 28, 224 × 260) with six 43 px rows. Hairlines (white 8 %) are inset to x 52.
- Each row has:
  - a 28 px coloured icon tile (r 9, white glyph; `ink` glyph on yellow and green),
  - the name (`title`) and a sub-line (11 px `text2`),
  - the value right-aligned at x 202,
  - 4 signal bars at x 208 (white; empty bars at 20 %), or a battery capsule.

### lap (overlay on ride) — keys: Lap · Page · **Pause**
- **Timeline** (loops every 6 s):
  - 0–0.35 s: the sheet slides from above to y 26 (`settle`, no bounce).
  - It holds until 4.4 s.
  - 4.4–4.75 s: it slides out (`inOut`).
- **Scrim**: `deep` at 50 % × progress over y 0..292.
- **Sheet** (8, 26, 224 × 184, r 22, `sheet` + `card` glass, the only shadow in the UI):
  - Header: `Lap 4` chip (accent, flag icon) and `vs lap 3` on the right.
  - Lap time in `xl` with its baseline at y+86, plus `.4` in `lg` `text2`.
  - `faster` and `−0:14` in `good` on the right.
  - Hairline, then 3 stat columns (Speed / Power / Heart), each with its delta in `good` or `warn`.
  - Auto-dismiss capsule (4 px) at y+168 that shrinks over the hold.

### summary — keys: Discard · Page · **Save**
- **Status title**: `Ride complete`.
- **Header**: `Sat 27 Sep · Hudson loop` (`body`, `text2`) at y 42.
- **Distance**: `48.2` in `xl` with its baseline at y 94, then `mi`. A `3 PRs` chip (`z4`, flag icon) sits on the right at y 62.
- **Elevation card** (8, 106, 224 × 70):
  - Label and `3,412 ft`.
  - The trace is a 2 px accent line with an accent fill (60 % → 4 %).
  - The trace draws itself left to right over 1.5 s.
- **3 × 2 tiles** (70/71/71 × 50, rows at y 182 and 238): Moving, Avg mph, Avg W, NP W, Avg bpm, TSS. The units are in the labels because a 71 px tile cannot fit "17.9 mph" at 20 px.

### menu — keys: Prev · **Open** · Next
- **Status title**: `Menu`.
- **Rows**: six glass `field` rows (224 × 38, r 14) at a 43 px pitch from y 28.
- **Selection**: a `raised` glass row that glides 220 ms (`ease_out`) to the new row.
- **Each row**: a 26 px icon tile (white 12 %, or accent when selected), the name (`title`) at y+17, a sub-line (11 px) at y+31, and a chevron at x 217–221.

### boot — no keys
- **Timeline** (6 s loop):
  - 0–0.8 s: the backdrop fades up from black.
  - 0.5–1.3 s: the mark and wordmark fade in and rise 10 px (`settle`).
  - 1.2–4.6 s: the progress runs.
  - 5.2–6 s: everything fades out.
- **Mark**: a 68 px glass disc at (120, 132), holding a 5 px white ring (r 17) with a small gap and an accent dot at the top.
- **Wordmark**: `OpenCycle` in Inter Display 28/600 with its baseline at y 202.
- **Progress**: an 80 × 4 capsule at (80, 236).
- **Status line** (11 px `text2`) at y 260: `Finding satellites` → `Connecting sensors` → `Linking phone` → `Ready`.

## 7. Soft-key mapping

| Screen | Left | Centre | Right (primary unless noted) |
|---|---|---|---|
| ride, hr, climb, lap | Lap | Page | **Pause** |
| map | Zoom out | Centre | Zoom in (no primary) |
| workout | Skip | Page | **Pause** |
| status | Scan | Page | **Pair** |
| summary | Discard | Page | **Save** |
| menu | Prev | **Open** (centre is primary) | Next |
| boot | — | — | — |

`Page` cycles through ride → hr → climb → map → workout → status (`PAGES`). The left side button is back/power, and the right side button opens the menu. A key press gives feedback: the pill flips to `raised` for 120 ms. This is not shown in the renders.

## 8. Motion

All motion is a pure function of `t` in the renderer. The firmware uses `lv_anim` with the named path.

| What | Duration | Path |
|---|---|---|
| lap sheet in / out | 350 / 350 ms | `settle` (≈ `ease_out` quartic, no overshoot) / `ease_in_out` |
| menu selection glide | 220 ms | `ease_out` |
| page change | 200 ms cross-fade of the content layer (optional; a hard cut is fine) | `ease_out` |
| heartbeat | 60 / BPM | exp decay, scale 1.14 → 1 |
| summary trace reveal | 1.5 s | `ease_in_out` |
| zone light colour change | 400 ms | recolour cross-fade (`image_recolor` animated) |
| boot | 6 s | see above |

## 9. Constraints and open risks

- **Blending cost.** Every glass pixel is an alpha blend over the backdrop, which is also a blend over the zone light. When a number changes, LVGL redraws that area: image → A8 recolour blend → gradient fill → border → text.
  - The ESP32-S3 with software rendering should manage the per-second updates easily.
  - Full-screen redraws (page change, lap sheet slide) are about 3 blend passes over 76,800 px, estimated at 25–40 ms per frame. Not yet measured. If it is too slow, drop the lap sheet to an 8 fps slide or pre-render the static card chrome into an `lv_canvas` layer.
- **Gradient stop opacity.** The glass relies on LVGL 9 gradients having per-stop `opa`. The fallback (flat `bg_opa`) is documented in 5.3.
- **Banding.** The runtime blends are not dithered (LVGL 9 removed `LV_DITHER_GRADIENT`), so the zone light shows faint 565 steps. The baked backdrop is dithered. If the banding is objectionable on the real panel, bake one dithered backdrop per zone colour (7 × 150 KB = 1 MB flash) and drop the runtime A8 light.
- **Sunlight.** The design has dark translucent panels on a 1200-nit IPS. White numerals on about 15 % glass stay high contrast. But the `text3` units (≈ 4.2:1 on glass) and 10 px captions are the weakest elements, and need checking outdoors on the real panel. A light theme is *not* implemented. The tokens allow one: the backdrop becomes a pale bitmap, the glass becomes black at 4–8 % with a white 60 % highlight, and the text flips. This is untested.
- **Glyph coverage.** The fonts are subset to the ranges in section 3. Street names with accents (é, ü, ß…) need `0xA0–0xFF` added to the text faces (≈ +6 KB each).
- **Map rendering.** The live vector map with 6–10 px roads, round joins and translucent cards over it is the heaviest screen, and has not been profiled. Tiles and style are not decided (see `docs/FIRMWARE.md`).
- **Nothing here is verified on hardware.** Pixel sizes, contrast and timing are from the browser renderer only.

## Adding a screen

1. Add `{ id, name, desc }` to `SCREENS`, labels to `SOFTKEYS`, and the primary index to `PRIMARY` (and to `PAGES` if `Page` should reach it).
2. Write `DRAW.<id>(d, t, data)` using only `glass`, `field`, `gauge`, `ring`, `chip`, `icon` and text tokens. Keep content inside y 24..288.
3. Add a representative time to `SHOT_T` in `docs/ui/harness.html`, run `node docs/ui/shoot.mjs`, and look at the 1× PNG before committing.

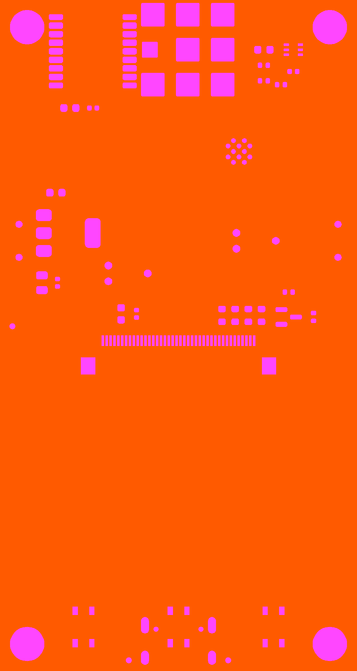
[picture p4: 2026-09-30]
viewer/pcb_front_orm.png

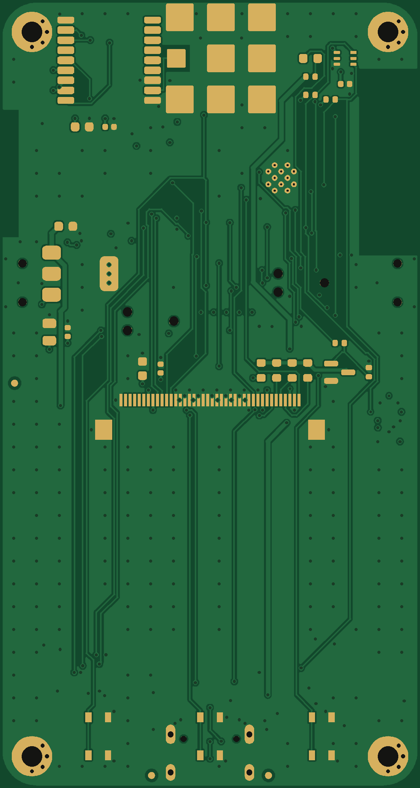
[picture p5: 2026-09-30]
viewer/pcb_front_color.png

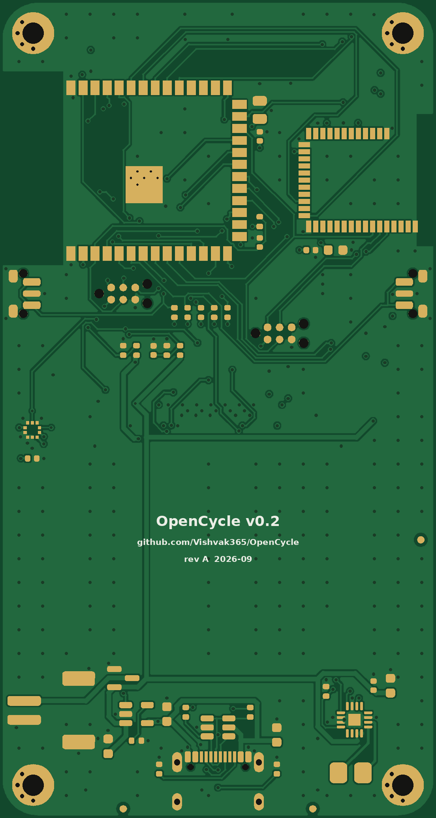
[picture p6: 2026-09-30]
viewer/pcb_back_color.png

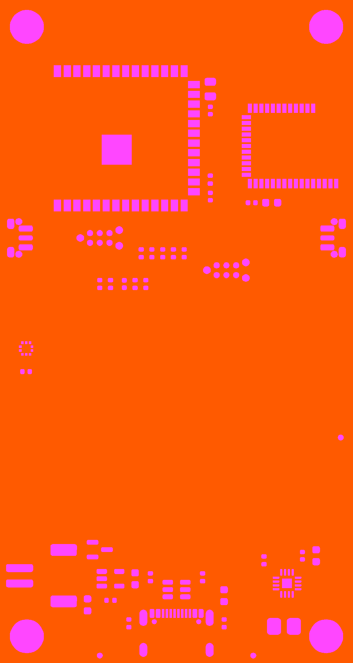
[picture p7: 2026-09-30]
viewer/pcb_back_orm.png

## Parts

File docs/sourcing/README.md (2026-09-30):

# Sourcing

Everything gathered while choosing and pricing parts. **Snapshot date: 2026-09-29/30 (v0.2 board parts re-checked 2026-09-30).** Prices are qty-1 USD, and stock moves daily, so re-check before ordering.

| File | Contents |
|---|---|
| [bom-v0.2.md](bom-v0.2.md) | **The board you order.** Every part on the v0.2 board plus the off-board items, with Mouser/Digi-Key part numbers, links, prices, stock and datasheets, grouped by function, with a cost roll-up. Generated from `pcb/design.py` + `pcb/sourcing.py`. |
| [../../pcb/fab/bom_distributors.csv](../../pcb/fab/bom_distributors.csv) | Same list as a spreadsheet, with quantities for 5 boards (import into a Mouser/Digi-Key cart). |
| [part-specs.md](part-specs.md) | Per-part engineering data for both builds: dimensions, pinouts, footprints, supply, datasheet links, and what's verified vs. still open. |
| [bom-mono-v0.1.md](bom-mono-v0.1.md) | The original Sharp memory-LCD build: LCSC (JLCPCB) numbers, then the Digi-Key/Mouser pricing pass. |
| [displays.md](displays.md) | Every display option looked at (mono, colour MIP, e-paper, TFT, OLED), with sources, prices, power, and availability. |
| [stock-issues-and-alternatives.md](stock-issues-and-alternatives.md) | Parts that were out of stock or rejected, why, and what replaced them. |
| [power-budget.md](power-budget.md) | Current-draw estimates and battery-life tables for both builds. |
| [market-reference.md](market-reference.md) | Commercial bike computers and existing open-source projects used as reference points. |

## Ordering rules

- Use at most three reputable vendors: **Mouser** (primary), **Digi-Key** (secondary), **Adafruit** (breakouts and dev hardware). Avoid marketplace sellers for production parts.
- Two vendors cover the v0.2 board: **Mouser** (everything else) and **Digi-Key** (BMP581, Taoglas 12 mm patch, DMG2305UX P-FET).
- Order the thin-stock parts first: BMP581 (462 at Digi-Key), AP7361C-33E-13 (733 at Mouser), JST-PH SMT header (269 at Mouser), speaker (597 at Mouser).
- Buy spares of the MAX98357A now; Mouser is dropping it from its catalogue.

## Verification levels used in these docs

- **Verified:** read from the distributor page or the manufacturer datasheet/drawing during this pass.
- **Library:** geometry taken from the official KiCad library footprint (assumed correct, not re-checked against the datasheet).
- **Open:** still needs checking; listed at the end of each file.

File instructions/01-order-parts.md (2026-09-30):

# 1 · Order the parts

The full list with prices, stock and links: [`docs/sourcing/bom-v0.2.md`](../docs/sourcing/bom-v0.2.md). The same list as a spreadsheet with quantities for **5 boards** (plus spares for tiny passives): [`pcb/fab/bom_distributors.csv`](../pcb/fab/bom_distributors.csv).

## Electronics — two carts

1. **Mouser** (almost everything, ~$73 per unit): open the CSV, filter `Vendor = Mouser`, and paste *Vendor part number* + *Qty to order* into Mouser's **BOM Tool** (or Quick Order). This includes the display (NHD-2.4-240320AF-CSXP) and the Adafruit 258 battery.
2. **Digi-Key** (~$8 per unit): BMP581 barometer, Taoglas DSGP.1575.12.4.A.02 patch antenna, DMG2305UX-7 P-FET.

Order the thin-stock parts first and buy spares: BMP581 (hard to hand-solder — get 2 extra), MAX98357A (Mouser is phasing it out), AP7361C-33E-13, the JST PH socket, the speaker.

**Don't substitute:** `AP7361C-33E-13` (SOT-223, pin 1 = IN). The similar `AP7361C-33ER-13` has a different pin order and would be wired wrong.

## Mechanical bits

| Item | Where | Notes |
|---|---|---|
| Cover lens, 1.0 mm clear acrylic/PC, 48.0 × 75.9 mm, 5 mm corners | SendCutSend / Ponoko (upload `print/cover_lens_outline.dxf`) | Or cut from a 1 mm sheet with a knife and file. |
| Black vinyl or paint for the lens mask | any | Mask template: `print/step/lens_mask.step` (screen window + two small windows top-right). |
| M2 × 5 mm + M2 × 6 mm pan-head screws | any | 4 of each. |
| 1.2 mm nitrile O-ring cord (~280 mm) | any | Case seal. |
| 0.5 mm closed-cell foam tape | any | 2 mm strips around the display. |
| ePTFE vent sticker (3–5 mm) | any | Over the barometer vent hole. |
| Acoustic mesh 12 × 9 mm | any | Under the speaker grille. |

## Tools (one-time)

- Soldering iron with a fine tip, flux, 0.3 mm solder, tweezers, magnifier or microscope.
- **Hot plate or hot-air station** + the JLC stencil (step 2): needed for the BMP581 (LGA-10), MAX98357A (QFN), ESP32 module ground pad.
- Solder paste: SAC305 for the back side, **low-temperature (Sn42Bi58, 138 °C)** for the front side (see step 4).
- Multimeter; a current-limited bench supply (or a USB-C power meter).
- **Tag-Connect TC2030-IDC-NL** cable + a SWD probe (J-Link EDU Mini, or an nRF52 DK) to program the BL652. The ESP32 flashes over USB-C.
- USB-C data cable.

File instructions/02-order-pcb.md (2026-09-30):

# 2 · Order the boards (JLCPCB)

Upload [`pcb/fab/opencycle_v0.2_gerbers.zip`](../pcb/fab/opencycle_v0.2_gerbers.zip) at jlcpcb.com → *Order now*. It detects 4 layers and a 46 × 86.4 mm board.

| Option | Choose | Why |
|---|---|---|
| Layers | 4 | GND and 3.3 V planes |
| Thickness | **1.0 mm** | The enclosure stack is built around 1.0 mm |
| Impedance control / stack-up | **JLC04101H-3313** (or ask for impedance control) | The GPS feed (RF_IN) is a 0.2 mm trace over In1; check ~50 Ω in JLC's calculator |
| Surface finish | **ENIG** | Flat pads for the LGA barometer, QFN amp and 0.5 mm FFC connector |
| Via covering | Tented | Default |
| Min via / hole | 0.3 mm vias; the ESP32 thermal pad has 0.2 mm holes (JLC standard for 4-layer) | |
| Mark on PCB ("order number") | "Specify a location" or "Remove" | The back is crowded |
| Stencil | **Yes**, framework-less, top **and** bottom (or two stencils) | Needed for paste on both sides |
| Quantity | 5 | |

## If JLCPCB should assemble it (optional)

Upload [`pcb/fab/bom_jlcpcb.csv`](../pcb/fab/bom_jlcpcb.csv) and [`pcb/fab/cpl_jlcpcb.csv`](../pcb/fab/cpl_jlcpcb.csv). JLC matches parts by the *Manufacturer Part Number* column. Expect some parts to be "global sourcing" or not stocked (the BL652, the Taoglas patch, the BMP581); either let JLC source them or send them your own (consigned parts).

**Check every rotation in JLC's 3D preview before paying** — KiCad and JLC disagree on the zero orientation of some packages (SOT-23, QFN, connectors). Pin 1 dots must match the silkscreen/assembly drawing.

Two sides of assembly costs more; a cheaper split is JLC for the back side (modules, QFN, LGA) and your iron for the front side.

## Check before paying

- JLC's Gerber viewer shows the rounded 46 × 86.4 mm outline, four M2 holes, and antenna cut-outs in the inner planes at the left and right edges.
- Four copper layers present (F.Cu, In1 GND, In2 3V3, B.Cu).

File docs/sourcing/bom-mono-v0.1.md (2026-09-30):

# Mono build (v0.1) — Sharp memory LCD

The first design, as implemented in `pcb/design.py`. Kept for reference; the current design is the [v0.2 colour build](bom-v0.2.md).

## LCSC / JLCPCB numbers (first pass, for JLC assembly)

| Ref | Part | LCSC | Notes |
|---|---|---|---|
| U1 | Raytac MDBT50Q-1MV2 | — | Not stocked by LCSC; JLC global sourcing or hand-place |
| U2 | u-blox MAX-M10S-00B | C4153167 | Verified |
| U3 | Winbond W25Q128JVSIQ | C97521 | |
| J1 | HRO TYPE-C-31-M-12 | C165948 | |
| D1 | USBLC6-2SC6 | C7519 | |
| J2 | JST SM02B-SRSS-TB | C160402 | |
| U4 | MCP73831T-2ACI/OT | C424093 | Verified |
| U5 | XC6220B331MR-G | C86534 | Verified |
| U6 | TPS61220DCKR | C15421 | TPS61222 not found at LCSC |
| L1 | Sunlord SWPA3012S4R7MT | C83415 | |
| U7–U11 | SN74LV1T34DCKR | C78541 | Verified |
| J3 | Hirose FH12-10S-0.5SH(55) | C506791 | Verified |
| U12 | Bosch BMP280 | C83291 | |
| U13 | ST LIS3DH | C15134 | |
| U14 | MAX98357AETE+T | C910544 | Verified |
| SW1–3 | Alps SKRTLAE010 | C110293 | Verified |
| AE1 | 15 mm patch | — | Hand-solder |
| LS1 | 11 × 15 speaker | — | Ole Wolff OWS-111535TA-8A at LCSC C5705967 (~$1.44) |
| D2 | Green 0603 LED | C72043 | |
| Passives | 100 nF C1525 · 1 µF C52923 · 4.7 µF C23733 · 10 µF 0603 C19702 · 10 k C25744 · 5.1 k C25905 · 4.7 k C25900 · 2 k C4109 · 1 k C11702 · 1 M C26083 · 100 k C25741 | | 110 k: match by value |

## Digi-Key / Mouser pass (qty 1)

| Part | Where | Price | Stock |
|---|---|---|---|
| MAX-M10S-00B | Mouser 377-MAX-M10S-00B / DK 672-MAX-M10S-00B-CT-ND | $9.12 / $11.42 | 16,866 / 4,987 |
| Taoglas DSGP.1575.15.4.A.02 | DK 931-DSGP.1575.15.4.A.02TR-ND | $5.43 | 427 |
| W25Q128JVSIQ | DK 256-W25Q128JVSIQTR-ND / Mouser 454-W25Q128JVSIQTR | $2.88 / $3.94 | 85,500 / 5,302 |
| GCT USB4105-GF-A | DK 2073-USB4105-GF-ADKR-ND | $0.80 | 121,048 |
| MAX98357AETE+T | DK MAX98357AETE+TCT-ND | $3.73 | 30,936 |
| Hirose FH12-10S-0.5SH(55) | DK/Mouser 798-FH12-10S-0.5SH55 | $1.75 | 6,378 |
| Alps SKRTLAE010 | Digi-Key | ~$0.34 | 432 |
| LIS3DHTR | Mouser 511-LIS3DHTR | $1.94 | 150 (DK 0) |
| Sharp LS027B7DH01 | DK 425-2907-ND | $32.24 | 0, 28-week lead |
| Raytac MDBT50Q-1MV2 | SparkFun WRL-21605 | $8.95 | in stock |
| u-blox NINA-B306-00B (alt. module) | DK ~$8.11–9.93 / Mouser $8.12–8.65 | | DK 203 |

Estimated parts cost: **$85–95 per unit** at qty 1, excluding PCB and case.

## Swaps agreed for v0.1 (not applied to the board)
BMP280 → LPS22HH · HRO USB-C → GCT USB4105 · Sunlord inductor → Taiyo Yuden NR3015 4.7 µH · pin-fed patch → Taoglas DSGP (SMT). LPS22HH later turned out to be out of stock everywhere mainstream; see [stock-issues-and-alternatives.md](stock-issues-and-alternatives.md).

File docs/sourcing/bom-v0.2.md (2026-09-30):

# Bill of materials — board v0.2 (colour build)

_Generated from `pcb/design.py` + `pcb/sourcing.py` by `tools/gen_bom_md.py`. Do not edit by hand._

Prices are quantity-1 USD. **Checked** = read from the distributor on that date; **typical** = commodity part stocked in the millions, price not re-read. Stock moves daily: check the cart before you order.

Machine-readable versions: [`pcb/fab/bom_distributors.csv`](../../pcb/fab/bom_distributors.csv) (order list) and [`pcb/fab/bom_jlcpcb.csv`](../../pcb/fab/bom_jlcpcb.csv) (assembly).

## Radios and GPS

| Refs | Qty | Part | MPN | Buy | Price | Checked | Notes |
|---|---|---|---|---|---|---|---|
| AE1 | 1 | Taoglas 12 x 12 x 4 mm GPS L1 / Galileo E1 ceramic patch, SMT | `DSGP.1575.12.4.A.02` | [Digi-Key DSGP.1575.12.4.A.02](https://www.digikey.com/en/products/result?keywords=DSGP.1575.12.4.A.02) · [datasheet](https://www.taoglas.com/datasheets/DSGP.1575.12.4.A.02.pdf) | $4.25 | 2026-09-30, 1,474 in stock | 12 mm ceramic patch, feed toward the receiver. RF_IN is a short hand-placed 0.2 mm trace over the In1 ground plane. |
| U1 | 1 | ESP32-S3 module, 16 MB flash, 8 MB octal PSRAM, PCB antenna | `ESP32-S3-WROOM-1-N16R8` | [Mouser 356-ESP32S3WRM1N16R8](https://www.mouser.com/c/?q=356-ESP32S3WRM1N16R8) · [datasheet](https://www.espressif.com/sites/default/files/documentation/esp32-s3-wroom-1_wroom-1u_datasheet_en.pdf) | $6.72 | 2026-09-30, 47,727 in stock | Main MCU: UI, logging, Wi-Fi, BLE, native USB. PCB antenna at the right board edge with a copper keep-out. |
| U2 | 1 | Ezurio (Laird) BL652, nRF52832 module, integrated antenna | `BL652-SA-01-T/R` | [Mouser 239-BL652-SA-01-T/R](https://www.mouser.com/c/?q=239-BL652-SA-01-T/R) · [datasheet](https://www.ezurio.com/wireless-modules/bluetooth-modules/bluetooth-5-modules/bl652-series-bluetooth-v5-nfc-module) | $10.40 | 2026-09-30, 5,583 in stock | nRF52832 module running an ANT+/BLE sensor bridge; talks to the ESP32 over UART. |
| U3 | 1 | u-blox M10 GNSS module, LCC-18 | `MAX-M10S-00B` | [Mouser 377-MAX-M10S-00B](https://www.mouser.com/c/?q=377-MAX-M10S-00B) · [datasheet](https://content.u-blox.com/sites/default/files/MAX-M10S_DataSheet_UBX-20035208.pdf) | $9.12 | 2026-09-30, 2,746 in stock | u-blox M10. Pin 15 is 'Reserved' on the MAX-M10S (KiCad names it VIO_SEL): left open. |

## Display and backlight

| Refs | Qty | Part | MPN | Buy | Price | Checked | Notes |
|---|---|---|---|---|---|---|---|
| J3 | 1 | Hirose 40-pin 0.5 mm bottom-contact FFC connector | `FH12-40S-0.5SH(55)` | [Mouser 798-FH12-40S-0.5SH55](https://www.mouser.com/c/?q=798-FH12-40S-0.5SH55) · [datasheet](https://www.hirose.com/product/series/FH12) | $2.50 | 2026-09-30, 25,967 in stock | Newhaven NHD-2.4-240320AF-CSXP, bottom-contact FFC. Pin 1 left. Cable enters from below after folding behind the panel. |
| Q1 | 1 | N-MOSFET 20 V SOT-23 (backlight PWM) | `DMG2302UK-7` | [Mouser 621-DMG2302UK-7](https://www.mouser.com/c/?q=621-DMG2302UK-7) · [datasheet](https://www.diodes.com/assets/Datasheets/DMG2302UK.pdf) | $0.39 | 2026-09-30, 238,766 in stock | Backlight PWM switch |
| R5, R6, R7, R8 | 4 | Yageo resistor 33R 0603 | `RC0603FR-0733RL` | [Mouser 603-RC0603FR-0733RL](https://www.mouser.com/c/?q=603-RC0603FR-0733RL) | $0.10 | typical | Backlight LED 1 ballast (0603 for dissipation) |
| R9 | 1 | Yageo resistor 100R 0402 | `RC0402FR-07100RL` | [Mouser 603-RC0402FR-07100RL](https://www.mouser.com/c/?q=603-RC0402FR-07100RL) | $0.10 | typical |  |
| R10 | 1 | Yageo resistor 100k 0402 | `RC0402FR-07100KL` | [Mouser 603-RC0402FR-07100KL](https://www.mouser.com/c/?q=603-RC0402FR-07100KL) | $0.10 | typical | Backlight off while the ESP32 boots |

## Power, USB, battery

| Refs | Qty | Part | MPN | Buy | Price | Checked | Notes |
|---|---|---|---|---|---|---|---|
| D1 | 1 | Green LED 0603 | `LTST-C191KGKT` | [Mouser 859-LTST-C191KGKT](https://www.mouser.com/c/?q=859-LTST-C191KGKT) · [datasheet](https://optoelectronics.liteon.com/upload/download/DS22-2000-229/LTST-C191KGKT.pdf) | $0.15 | 2026-09-30, 1,190,000 in stock | Charge LED behind the lens window (lit while charging). |
| D2 | 1 | USB ESD protection, SOT-23-6 | `USBLC6-2SC6` | [Mouser 511-USBLC6-2SC6](https://www.mouser.com/c/?q=511-USBLC6-2SC6) · [datasheet](https://www.st.com/resource/en/datasheet/usblc6-2.pdf) | $0.49 | 2026-09-30, 81,014 in stock | USB ESD |
| J1 | 1 | GCT USB-C receptacle, USB 2.0, top mount | `USB4105-GF-A` | [Mouser 640-USB4105-GF-A](https://www.mouser.com/c/?q=640-USB4105-GF-A) · [datasheet](https://gct.co/files/drawings/usb4105.pdf) | $0.80 | 2026-09-30, 420,427 in stock | USB 2.0 (ESP32 native USB) + charging |
| J2 | 1 | JST PH 2-pin side-entry SMT header | `S2B-PH-SM4-TB(LF)(SN)` | [Mouser 306-S2BPHSM4TBLFSN](https://www.mouser.com/c/?q=306-S2BPHSM4TBLFSN) · [datasheet](https://www.jst-mfg.com/product/pdf/eng/ePH.pdf) | $0.49 | 2026-09-30, 269 in stock | JST-PH battery socket for the Adafruit 258 cell. Pin 1 = -, pin 2 = + (common JST-PH LiPo convention). Q2 blocks a reversed battery; still check polarity with a meter before first plug-in. |
| Q2 | 1 | P-MOSFET 20 V 4.2 A SOT-23 (reverse battery) | `DMG2305UX-7` | [Digi-Key DMG2305UX-7DICT-ND](https://www.digikey.com/en/products/result?keywords=DMG2305UX-7DICT-ND) · [datasheet](https://www.diodes.com/assets/Datasheets/DMG2305UX.pdf) | $0.30 | 2026-09-30, 75,458 in stock | Reverse-battery protection (P-FET, gate to GND) |
| R2 | 1 | Yageo resistor 1k 0402 | `RC0402FR-071KL` | [Mouser 603-RC0402FR-071KL](https://www.mouser.com/c/?q=603-RC0402FR-071KL) | $0.10 | typical |  |
| R11, R12 | 2 | Yageo resistor 5.1k 0402 | `RC0402FR-075K1L` | [Mouser 603-RC0402FR-075K1L](https://www.mouser.com/c/?q=603-RC0402FR-075K1L) | $0.10 | typical |  |
| R13, R14 | 2 | Yageo resistor 0R 0402 | `RC0402JR-070RL` | [Mouser 603-RC0402JR-070RL](https://www.mouser.com/c/?q=603-RC0402JR-070RL) | $0.10 | typical | USB D+ link (0R, lets the ESD part sit next to the connector) |
| R15 | 1 | Yageo resistor 2k 0402 | `RC0402FR-072KL` | [Mouser 603-RC0402FR-072KL](https://www.mouser.com/c/?q=603-RC0402FR-072KL) | $0.10 | typical | 500 mA charge current |
| R16, R17 | 2 | Yageo resistor 1M 0402 | `RC0402FR-071ML` | [Mouser 603-RC0402FR-071ML](https://www.mouser.com/c/?q=603-RC0402FR-071ML) | $0.10 | typical | Battery voltage divider |
| R18, R19 | 2 | Yageo resistor 100k 0402 | `RC0402FR-07100KL` | [Mouser 603-RC0402FR-07100KL](https://www.mouser.com/c/?q=603-RC0402FR-07100KL) | $0.10 | typical | USB present detect |
| U5 | 1 | 3.3 V 1 A LDO, SOT-223 | `AP7361C-33E-13` | [Mouser 621-AP7361C-33E-13](https://www.mouser.com/c/?q=621-AP7361C-33E-13) · [datasheet](https://www.diodes.com/assets/Datasheets/AP7361C.pdf) | $0.52 | 2026-09-30, 733 in stock | 1 A LDO (ESP32 Wi-Fi peaks ~500 mA) |
| U6 | 1 | Li-ion charger 4.20 V, SOT-23-5 | `MCP73831T-2ACI/OT` | [Mouser 579-MCP73831T-2ACIOT](https://www.mouser.com/c/?q=579-MCP73831T-2ACIOT) · [datasheet](https://ww1.microchip.com/downloads/en/DeviceDoc/MCP73831-Family-Data-Sheet-DS20001984H.pdf) | $0.76 | 2026-09-30, 116,042 in stock | Li-ion charger, 4.20 V, 500 mA |

## Sensors

| Refs | Qty | Part | MPN | Buy | Price | Checked | Notes |
|---|---|---|---|---|---|---|---|
| R3, R4 | 2 | Yageo resistor 4.7k 0402 | `RC0402FR-074K7L` | [Mouser 603-RC0402FR-074K7L](https://www.mouser.com/c/?q=603-RC0402FR-074K7L) | $0.10 | typical |  |
| U4 | 1 | Lite-On ambient light sensor, I2C | `LTR-303ALS-01` | [Mouser 859-LTR-303ALS-01](https://www.mouser.com/c/?q=859-LTR-303ALS-01) · [datasheet](https://optoelectronics.liteon.com/upload/download/DS86-2013-0004/LTR-303ALS-01_DS_V1.pdf) | $0.68 | 2026-09-30, 29,622 in stock | Ambient light sensor behind the lens window; auto-dims the backlight. I2C 0x29. |
| U8 | 1 | Bosch barometric pressure sensor, LGA-10 2 x 2 mm | `BMP581` | [Digi-Key 828-BMP581CT-ND](https://www.digikey.com/en/products/result?keywords=828-BMP581CT-ND) · [datasheet](https://www.bosch-sensortec.com/media/boschsensortec/downloads/datasheets/bst-bmp581-ds004.pdf) | $3.07 | 2026-09-30, 462 in stock | Barometer, I2C 0x46. No vias/traces under it (Bosch). Next to the vent in the right wall. |

## Audio

| Refs | Qty | Part | MPN | Buy | Price | Checked | Notes |
|---|---|---|---|---|---|---|---|
| LS1 | 1 | Same Sky 15 x 11 x 2.5 mm speaker, 8 ohm 0.7 W, IP67, wire leads | `CMS-151125-078L100` | [Mouser 490-CMS151125078L100](https://www.mouser.com/c/?q=490-CMS151125078L100) · [datasheet](https://www.mouser.com/datasheet/3/6118/1/cms-151125-078x-67.pdf) | $2.96 | 2026-09-30, 597 in stock | Pads for the speaker's 32 AWG leads (red = +). |
| R20 | 1 | Yageo resistor 100k 0402 | `RC0402FR-07100KL` | [Mouser 603-RC0402FR-07100KL](https://www.mouser.com/c/?q=603-RC0402FR-07100KL) | $0.10 | typical | Amp off until firmware enables it |
| U7 | 1 | I2S class-D amplifier, TQFN-16 | `MAX98357AETE+T` | [Mouser 700-MAX98357AETE+T](https://www.mouser.com/c/?q=700-MAX98357AETE+T) · [datasheet](https://www.analog.com/media/en/technical-documentation/data-sheets/MAX98357A-MAX98357B.pdf) | $4.08 | 2026-09-30, 10,971 in stock | I2S class-D amp, 12 dB (GAIN to GND); SD_MODE high = left channel |

## Keys

| Refs | Qty | Part | MPN | Buy | Price | Checked | Notes |
|---|---|---|---|---|---|---|---|
| R1, R21, R22, R23, R24, R25 | 6 | Yageo resistor 10k 0402 | `RC0402FR-0710KL` | [Mouser 603-RC0402FR-0710KL](https://www.mouser.com/c/?q=603-RC0402FR-0710KL) | $0.10 | typical | Key pull-ups |
| SW1, SW2, SW3 | 3 | C&K top-actuated tact switch 4.2 x 3.2 x 2.5 mm | `PTS810 SJM 250 SMTR LFS` | [Mouser 611-PTS810SJM250SMTR](https://www.mouser.com/c/?q=611-PTS810SJM250SMTR) · [datasheet](https://www.ckswitches.com/media/1476/pts810.pdf) | $0.52 | 2026-09-30, 30,244 in stock | Front soft key (KEY_L). Top-actuated, 2.5 mm tall. Turned 90 deg so the USB-C locating pegs clear its pads. |
| SW4, SW5 | 2 | Alps side-actuated tact switch | `SKRTLAE010` | [Mouser 688-SKRTLA](https://www.mouser.com/c/?q=688-SKRTLA) · [datasheet](https://tech.alpsalpine.com/e/products/detail/SKRTLAE010/) | $0.34 | 2026-09-30, 2,396 in stock | Left side: power / back |

## Capacitors

| Refs | Qty | Part | MPN | Buy | Price | Checked | Notes |
|---|---|---|---|---|---|---|---|
| C1, C12 | 2 | 22 uF 25 V X5R 0805 | `CL21A226MAQNNNE` | [Mouser 187-CL21A226MAQNNNE](https://www.mouser.com/c/?q=187-CL21A226MAQNNNE) | $0.22 | typical |  |
| C2, C5, C7, C8, C10, C13, C17, C19, C20 | 9 | 100 nF 16 V X7R 0402 | `CL05B104KO5NNNC` | [Mouser 187-CL05B104KO5NNNC](https://www.mouser.com/c/?q=187-CL05B104KO5NNNC) | $0.10 | typical |  |
| C3 | 1 | 1 uF 16 V X5R 0402 | `CL05A105KO5NNNC` | [Mouser 187-CL05A105KO5NNNC](https://www.mouser.com/c/?q=187-CL05A105KO5NNNC) | $0.10 | typical | EN reset delay (10k x 1uF) |
| C4, C6, C9, C11, C18 | 5 | 10 uF 10 V X5R 0603 | `CL10A106KP8NNNC` | [Mouser 187-CL10A106KP8NNNC](https://www.mouser.com/c/?q=187-CL10A106KP8NNNC) | $0.12 | typical |  |
| C14, C15, C16 | 3 | 4.7 uF 16 V X5R 0603 | `CL10A475KO8NNNC` | [Mouser 187-CL10A475KO8NNNC](https://www.mouser.com/c/?q=187-CL10A475KO8NNNC) | $0.10 | typical |  |

## Off the board

| Item | Qty | Buy | Price | Notes |
|---|---|---|---|---|
| Newhaven 2.4 in IPS TFT 240 x 320, ST7789, 1200 nit, 40-pin FFC | 1 | [Mouser 763-24240320AFCSXP](https://www.mouser.com/c/?q=763-24240320AFCSXP) · [datasheet](https://newhavendisplay.com/content/specs/NHD-2.4-240320AF-CSXP.pdf) | $15.86 | checked 2026-09-30, 1,032 in stock. Plugs into J3. |
| Adafruit 258 LiPo 1200 mAh 34 x 62 x 5 mm, protected, JST-PH | 1 | Mouser 485-258 | $9.95 | checked 2026-09-30, 388 in stock |
| M2 x 5 mm pan-head screws (stainless) | 4 | any e.g. McMaster 92000A017 | $0.10 | PCB to back shell |
| M2 x 6 mm pan-head screws (stainless) | 4 | any | $0.10 | front bezel to back shell (through the corner posts) |
| 1.0 mm clear acrylic or polycarbonate cover lens, 48.0 x 75.9 mm, 5 mm corner radius | 1 | SendCutSend / Ponoko cad/out/stl/cover_lens.step | $3.00 | black mask: vinyl or paint on the inside, window per cad/out/stl/lens_mask.stl |
| Closed-cell foam tape 0.5 mm, 2 mm strips | 1 | any | $1.00 | display gasket |
| Nitrile O-ring cord 1.2 mm | 1 | any | $1.00 | case seal, ~280 mm length, ends glued |
| Breathable PTFE vent sticker, 3-5 mm | 1 | any e.g. Amazon 'ePTFE vent patch' | $0.50 | over the 0.8 mm barometer vent |
| Acoustic mesh / speaker membrane 12 x 9 mm | 1 | any | $0.50 | under the speaker grille |
| PLA / PETG / TPU filament | 1 | any | $2.00 | ~35 g for a standard case |

## Cost for one unit (parts only)

| Vendor | Subtotal |
|---|---|
| Mouser | $72.95 |
| Digi-Key | $7.62 |
| any | $5.80 |
| SendCutSend / Ponoko | $3.00 |
| **Total** | **$89.37** |

Not included: PCBs (JLCPCB, 5 boards 4-layer 1.0 mm ≈ $15–25 + shipping), stencil (≈ $8), tools (see [instructions/01-order-parts.md](../../instructions/01-order-parts.md)).

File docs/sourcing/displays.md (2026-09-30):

# Display options

## Comparison

| Option | Colour | Direct sun | Night | Screen power | Refresh | Price | Board impact |
|---|---|---|---|---|---|---|---|
| Sharp LS027B7DH01A memory LCD (2.7", 400×240) | 1-bit | Excellent | Needs front light | ~0.05–0.2 mW | Fast | $15–35 | 5 V: boost + 5 level shifters |
| JDI LPM027M128C colour MIP (2.7", 400×240) | 8 colours | Excellent | Front-light versions exist | ~0.1–0.5 mW | Fast | $25–65 | 3.0 V: no boost/shifters |
| E-paper 2.9" (296×128) | 1-bit / 4-grey | Excellent | Needs light | ~0 static | 0.3 s partial, 1–2 s full | $10–20 | Small |
| Transflective colour TFT (2.0–2.4") | Full | Good (backlight off) | Backlight | 15–30 mW + backlight | Fast | $15–35 | Bigger MCU |
| **IPS TFT, high brightness (chosen for v0.2)** | Full | OK at 1200 nit, backlight-hungry | Great | ~33 mW logic + up to ~500 mW backlight | Fast | ~$16 | Bigger MCU |
| OLED | Full | Poor | Great | 20–150 mW | Fast | $5–20 | Colour panels ≤ ~1.5" |

## Sources found

**Sharp LS027B7DH01(A)**
- [AliExpress LS027B7DH01A](https://www.aliexpress.com/item/1005005611440829.html) · [Tindie SIKTEC board](https://www.tindie.com/products/siktec/new-sharp-memory-lcd-27inch-400x240-display-ls027/) · [Amazon](https://www.amazon.com/2-7in-400X240-LS027B7DH01A-LS027B7DH01-Display/dp/B0F1FRLBHP)
- [Adafruit 4694 breakout](https://adafruit.com/product/4694): $44.95, out of stock at the check; includes 3 V regulator, 5 V boost, level shifting.
- Digi-Key LS027B7DH01 425-2907-ND: $32.24, 0 stock, 28-week lead. Mouser lists 852-LS027B7DH01 (stock not shown).
- Pinout verified from the Sharp datasheet (alldatasheet mirror). Used in the Playdate.

**JDI LPM027M128C (colour MIP)**
- [AliExpress](https://www.aliexpress.com/item/1005009104635881.html) · [Switch Science](https://www.switch-science.com/catalog/5395/): ¥9,460, sold out / discontinued; confirms **3.0 V supply** and a backlight.
- Reference projects: [pizero_bikecomputer](https://github.com/hishizuka/pizero_bikecomputer/blob/master/doc/hardware_installation.md) uses this panel; drivers [JDI_MIP_Display](https://github.com/Gbertaz/JDI_MIP_Display), [memory-lcd-spi](https://github.com/andelf/memory-lcd-spi).

**E-paper**
- [2.9" partial refresh 4-grey (AliExpress)](https://www.aliexpress.com/i/3256801652983286.html) · [2.9" 296×128 (AliExpress)](https://www.aliexpress.com/item/32811674328.html) · [GDEY029T94 with touch and front light](https://buyepaper.com/products/gdey029t94-ft01)

**Transflective / sunlight-readable TFT**
- [DisplayModule 2.0" transflective ST7789](https://www.displaymodule.com/products/2-0-inch-240x320-tft-st7789-spi-mcu-rgb-dm-tft20-435)
- Newhaven [NHD-2.4-240320CF-CSXN#-F](https://newhavendisplay.com/2-4-inch-sunlight-readable-tft-without-touchscreen/): 1000 nit, transmissive TN, parallel only, $16.64, same 42.8 × 59.91 × 2.55 outline.
- Newhaven [2.4" sunlight-readable resistive](https://newhavendisplay.com/2-4-inch-sunlight-readable-resistive-tft-display/).
- Many AliExpress "sunlight readable" listings are just bright transmissive panels.

**IPS TFT (+ touch)**
- **[Newhaven NHD-2.4-240320AF-CSXP](https://newhavendisplay.com/2-4-tft-lcd-ips-high-brightness-display/)**: IPS, 1200 nit, SPI, $13.94 direct / $15.86 Mouser. Full data in [part-specs.md](part-specs.md).
- [Adafruit 2090 2.8" + cap touch](https://adafruit.com/product/2090): $29.95, CST026 touch, 4-LED backlight, board 81.3 × 62.5.
- [Waveshare 2.8" ST7789 + touch](https://www.waveshare.com/2.8inch-capacitive-touch-lcd.htm) · [BuyDisplay 2.8" ST7789V capacitive](https://www.buydisplay.com/2-8-inch-tft-lcd-display-capacitive-touch-screen-st7789v-spi-240x320) · [AliExpress search](https://www.aliexpress.com/w/wholesale-2.8-capacitive-touch-screen.html)

## Why IPS TFT for v0.2
It's cheap, in stock at Mouser, well documented (drawing, pinout, backlight data), SPI with ST7789 (LVGL driver exists), and the same outline family as Newhaven's sunlight-readable TN panel. The cost is backlight power; the ambient-light sensor handles auto-dimming.

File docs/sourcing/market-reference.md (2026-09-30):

# Market reference

Prices as seen 2026-09-29.

## Commercial bike computers

| Device | Price seen | Screen | Notes |
|---|---|---|---|
| [GEOID CC700 Pro](https://bicyclingaustralia.com.au/?p=42178) | $69–85 AliExpress sale ([Slickdeals $68.90](https://slickdeals.net/f/20018094-geoid-cc700-pro-bike-computer-gps-2-8-touchscreen-navigation-69-free-shipping-68-9)); ~$99 list | 2.8" colour touch, 240 × 320 | Dual-band GNSS, offline maps, Wi-Fi/BLE/ANT+, IPX7, 8 GB, DJI camera control ([specs](https://e-katalog.kz/GEOID-CC700-PRO.htm)). Weak: resolution, contrast, no live tracking. |
| GEOID CC700 (non-Pro) | ~$52–60 | 2.8" colour, buttons | |
| [iGPSPORT iGS630S](https://force.dev.programia.eu/EN/bike-computer-igpsport-igs630s) | ~$160–200 | 2.8" colour 240 × 400, buttons | Dual-band, 45 h battery. [iGS630 review](https://thesweetcyclists.com/igpsport-igs630-gps-bike-computer-review/) (35 h, $219 list). |
| [Magene C606 / V2](https://the5krunner.com/2024/03/14/magene-c606-review/) | ~$160 | 2.8" colour touch | Climb tracker, radar, workouts; app rough. [C606 V2 features](https://bike-addict.co.za/products/magene-c606-v2-smart-gps-bike-computer). |
| Coospo BC107 / CS300 | < £100 ([road.cc](https://road.cc/buyers-guide/best-cheap-cycling-computers)) | mono / 2.4" colour | Budget. |
| Garmin Edge 540 / 1050 | ~$300 / $700 | 2.6" / 3.5" colour | Reference for features and battery (~26 h on the 540). |

Takeaway: a DIY build doesn't beat these on price. At one unit, a CC700-class device costs ~$95–165 in parts plus ~$100–300 in prototype overhead. The case for OpenCycle is open firmware, repairability, battery life (mono), and learning.

## Open-source projects

| Project | Hardware | Notes |
|---|---|---|
| [OpenTrailPaper](https://www.cnx-software.com/2026/09/05/opentrailpaper-transforms-lilygo-t5-e-paper-s3-pro-devkit-into-a-diy-e-paper-bike-computer/) | LILYGO T5 E-Paper S3 Pro (ESP32-S3, 4.7" e-paper, M10/L76K GNSS) | Offline maps, GPX, FIT, BLE sensors, phone apps; < 8 h battery; 129 × 69 × 11 dev kit. |
| [bike-computer-32](https://github.com/lspr98/bike-computer-32) | ESP32-C3 | OSM offline maps, GPX rendering. |
| [Yōkai](https://github.com/mrmattuschka/yokai) | ESP32 + e-paper | Komoot BLE navigation display, no GPS. |
| [ESP32 GPS bike computer (Printables)](https://www.printables.com/model/147944-gps-bicycle-computer-w-esp32-speedometer-sd-loggin) | ESP32, 128 × 64 LCD | SD logging, Qi charging. |
| [HITSZ Bike-Computer](https://github.com/MaxwellJay256/Bike-Computer) | ESP32, ESP-IDF | Student project. |
| [pizero_bikecomputer](https://github.com/hishizuka/pizero_bikecomputer) | Raspberry Pi Zero + JDI colour MIP | Mature software; reference for the MIP panel. |

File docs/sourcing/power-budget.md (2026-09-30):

# Power budget

Estimates from datasheets and typical figures; replace with measurements once hardware exists.

## Mono build (nRF52840 + Sharp memory LCD)

| Load | Avg current while riding |
|---|---|
| GPS (MAX-M10S, continuous) | 7–8 mA |
| nRF52840: BLE/ANT+ sensors, logging | 1.5–3 mA |
| Sharp LCD + 5 V boost, 1–2 updates/s | 0.1–0.2 mA |
| Sensors, flash, LDO Iq, battery divider | ~0.1 mA |
| **Total** | **~10–11 mA** |

| Battery | Ride time |
|---|---|
| 30 × 48 × 6 (~850 mAh) | ~70–80 h |
| 30 × 48 × 8 (~1100 mAh) | ~90–100 h |
| 30 × 48 × 10 (~1500 mAh) | ~130 h |

Standby with GPS off: tens of µA (months).

## Colour build (ESP32-S3 + BL652 + IPS TFT)

| Load | Avg current while riding |
|---|---|
| GPS | 7–8 mA |
| ESP32-S3: BLE, UI, logging; Wi-Fi only to sync | 15–25 mA |
| BL652 ANT+/BLE sensor links | 1–2 mA |
| TFT logic (ST7789, datasheet typ.) | ~10 mA |
| Backlight, auto-dimmed (full = 160 mA / 1200 nit) | 20–80 mA |
| **Total** | **~55–125 mA** |

| Battery | Ride time |
|---|---|
| Adafruit 258, 1200 mAh (34 × 62 × 5) | ~10–22 h |
| Adafruit 328, 2500 mAh (needs a thicker case) | ~20–45 h |

The backlight dominates. The levers are auto-dimming (ambient light sensor), a lower default brightness, a shorter screen timeout, and later a transflective panel.

## Reference points
- Garmin Edge 540: ~26 h rated. Coros Dura: ~120 h with solar.
- ESP32-S3 Wi-Fi transmit peaks ~500 mA, which sets the 1 A LDO choice.

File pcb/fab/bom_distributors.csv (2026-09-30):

Vendor | Vendor part number | Manufacturer | MPN | Description | Qty per board | Qty to order (5 boards) | Unit price USD | Line total (1 board) | Price checked | Stock seen | Designators | Link | Datasheet
Mouser | 485-258 |  |  | Adafruit 258 LiPo 1200 mAh 34 x 62 x 5 mm, protected, JST-PH | 1 | 5 | 9.95 | 9.95 | 2026-09-30 |  | checked 2026-09-30, 388 in stock
Mouser | 621-AP7361C-33E-13 | Diodes | AP7361C-33E-13 | 3.3 V 1 A LDO, SOT-223 | 1 | 5 | 0.52 | 0.52 | 2026-09-30 | 733 | U5 | https://www.mouser.com/c/?q=621-AP7361C-33E-13 | https://www.diodes.com/assets/Datasheets/AP7361C.pdf
Mouser | 239-BL652-SA-01-T/R | Ezurio | BL652-SA-01-T/R | Ezurio (Laird) BL652, nRF52832 module, integrated antenna | 1 | 5 | 10.40 | 10.40 | 2026-09-30 | 5583 | U2 | https://www.mouser.com/c/?q=239-BL652-SA-01-T/R | https://www.ezurio.com/wireless-modules/bluetooth-modules/bluetooth-5-modules/bl652-series-bluetooth-v5-nfc-module
Mouser | 187-CL05A105KO5NNNC | Samsung | CL05A105KO5NNNC | 1 uF 16 V X5R 0402 | 1 | 7 | 0.10 | 0.10 | typical |  | C3 | https://www.mouser.com/c/?q=187-CL05A105KO5NNNC
Mouser | 187-CL05B104KO5NNNC | Samsung | CL05B104KO5NNNC | 100 nF 16 V X7R 0402 | 9 | 47 | 0.10 | 0.90 | typical |  | C2 C5 C7 C8 C10 C13 C17 C19 C20 | https://www.mouser.com/c/?q=187-CL05B104KO5NNNC
Mouser | 187-CL10A106KP8NNNC | Samsung | CL10A106KP8NNNC | 10 uF 10 V X5R 0603 | 5 | 27 | 0.12 | 0.60 | typical |  | C4 C6 C9 C11 C18 | https://www.mouser.com/c/?q=187-CL10A106KP8NNNC
Mouser | 187-CL10A475KO8NNNC | Samsung | CL10A475KO8NNNC | 4.7 uF 16 V X5R 0603 | 3 | 17 | 0.10 | 0.30 | typical |  | C14 C15 C16 | https://www.mouser.com/c/?q=187-CL10A475KO8NNNC
Mouser | 187-CL21A226MAQNNNE | Samsung | CL21A226MAQNNNE | 22 uF 25 V X5R 0805 | 2 | 12 | 0.22 | 0.44 | typical |  | C1 C12 | https://www.mouser.com/c/?q=187-CL21A226MAQNNNE
Mouser | 490-CMS151125078L100 | Same Sky | CMS-151125-078L100 | Same Sky 15 x 11 x 2.5 mm speaker, 8 ohm 0.7 W, IP67, wire leads | 1 | 5 | 2.96 | 2.96 | 2026-09-30 | 597 | LS1 | https://www.mouser.com/c/?q=490-CMS151125078L100 | https://www.mouser.com/datasheet/3/6118/1/cms-151125-078x-67.pdf
Mouser | 621-DMG2302UK-7 | Diodes | DMG2302UK-7 | N-MOSFET 20 V SOT-23 (backlight PWM) | 1 | 7 | 0.39 | 0.39 | 2026-09-30 | 238766 | Q1 | https://www.mouser.com/c/?q=621-DMG2302UK-7 | https://www.diodes.com/assets/Datasheets/DMG2302UK.pdf
Mouser | 356-ESP32S3WRM1N16R8 | Espressif | ESP32-S3-WROOM-1-N16R8 | ESP32-S3 module, 16 MB flash, 8 MB octal PSRAM, PCB antenna | 1 | 5 | 6.72 | 6.72 | 2026-09-30 | 47727 | U1 | https://www.mouser.com/c/?q=356-ESP32S3WRM1N16R8 | https://www.espressif.com/sites/default/files/documentation/esp32-s3-wroom-1_wroom-1u_datasheet_en.pdf
Mouser | 798-FH12-40S-0.5SH55 | Hirose | FH12-40S-0.5SH(55) | Hirose 40-pin 0.5 mm bottom-contact FFC connector | 1 | 5 | 2.50 | 2.50 | 2026-09-30 | 25967 | J3 | https://www.mouser.com/c/?q=798-FH12-40S-0.5SH55 | https://www.hirose.com/product/series/FH12
Mouser | 859-LTR-303ALS-01 | Lite-On | LTR-303ALS-01 | Lite-On ambient light sensor, I2C | 1 | 5 | 0.68 | 0.68 | 2026-09-30 | 29622 | U4 | https://www.mouser.com/c/?q=859-LTR-303ALS-01 | https://optoelectronics.liteon.com/upload/download/DS86-2013-0004/LTR-303ALS-01_DS_V1.pdf
Mouser | 859-LTST-C191KGKT | Lite-On | LTST-C191KGKT | Green LED 0603 | 1 | 7 | 0.15 | 0.15 | 2026-09-30 | 1190000 | D1 | https://www.mouser.com/c/?q=859-LTST-C191KGKT | https://optoelectronics.liteon.com/upload/download/DS22-2000-229/LTST-C191KGKT.pdf
Mouser | 377-MAX-M10S-00B | u-blox | MAX-M10S-00B | u-blox M10 GNSS module, LCC-18 | 1 | 5 | 9.12 | 9.12 | 2026-09-30 | 2746 | U3 | https://www.mouser.com/c/?q=377-MAX-M10S-00B | https://content.u-blox.com/sites/default/files/MAX-M10S_DataSheet_UBX-20035208.pdf
Mouser | 700-MAX98357AETE+T | Analog Devices | MAX98357AETE+T | I2S class-D amplifier, TQFN-16 | 1 | 5 | 4.08 | 4.08 | 2026-09-30 | 10971 | U7 | https://www.mouser.com/c/?q=700-MAX98357AETE+T | https://www.analog.com/media/en/technical-documentation/data-sheets/MAX98357A-MAX98357B.pdf
Mouser | 579-MCP73831T-2ACIOT | Microchip | MCP73831T-2ACI/OT | Li-ion charger 4.20 V, SOT-23-5 | 1 | 5 | 0.76 | 0.76 | 2026-09-30 | 116042 | U6 | https://www.mouser.com/c/?q=579-MCP73831T-2ACIOT | https://ww1.microchip.com/downloads/en/DeviceDoc/MCP73831-Family-Data-Sheet-DS20001984H.pdf
Mouser | 763-24240320AFCSXP | Newhaven Display | NHD-2.4-240320AF-CSXP | Newhaven 2.4 in IPS TFT 240 x 320, ST7789, 1200 nit, 40-pin FFC | 1 | 5 | 15.86 | 15.86 | 2026-09-30 | 1032 | (display, plugs into J3) | https://www.mouser.com/c/?q=763-24240320AFCSXP | https://newhavendisplay.com/content/specs/NHD-2.4-240320AF-CSXP.pdf
Mouser | 611-PTS810SJM250SMTR | C&K | PTS810 SJM 250 SMTR LFS | C&K top-actuated tact switch 4.2 x 3.2 x 2.5 mm | 3 | 15 | 0.52 | 1.56 | 2026-09-30 | 30244 | SW1 SW2 SW3 | https://www.mouser.com/c/?q=611-PTS810SJM250SMTR | https://www.ckswitches.com/media/1476/pts810.pdf
Mouser | 603-RC0402FR-07100KL | Yageo | RC0402FR-07100KL | Yageo resistor 100k 0402 | 4 | 22 | 0.10 | 0.40 | typical |  | R10 R18 R19 R20 | https://www.mouser.com/c/?q=603-RC0402FR-07100KL
Mouser | 603-RC0402FR-07100RL | Yageo | RC0402FR-07100RL | Yageo resistor 100R 0402 | 1 | 7 | 0.10 | 0.10 | typical |  | R9 | https://www.mouser.com/c/?q=603-RC0402FR-07100RL
Mouser | 603-RC0402FR-0710KL | Yageo | RC0402FR-0710KL | Yageo resistor 10k 0402 | 6 | 32 | 0.10 | 0.60 | typical |  | R1 R21 R22 R23 R24 R25 | https://www.mouser.com/c/?q=603-RC0402FR-0710KL
Mouser | 603-RC0402FR-071KL | Yageo | RC0402FR-071KL | Yageo resistor 1k 0402 | 1 | 7 | 0.10 | 0.10 | typical |  | R2 | https://www.mouser.com/c/?q=603-RC0402FR-071KL
Mouser | 603-RC0402FR-071ML | Yageo | RC0402FR-071ML | Yageo resistor 1M 0402 | 2 | 12 | 0.10 | 0.20 | typical |  | R16 R17 | https://www.mouser.com/c/?q=603-RC0402FR-071ML
Mouser | 603-RC0402FR-072KL | Yageo | RC0402FR-072KL | Yageo resistor 2k 0402 | 1 | 7 | 0.10 | 0.10 | typical |  | R15 | https://www.mouser.com/c/?q=603-RC0402FR-072KL
Mouser | 603-RC0402FR-074K7L | Yageo | RC0402FR-074K7L | Yageo resistor 4.7k 0402 | 2 | 12 | 0.10 | 0.20 | typical |  | R3 R4 | https://www.mouser.com/c/?q=603-RC0402FR-074K7L
Mouser | 603-RC0402FR-075K1L | Yageo | RC0402FR-075K1L | Yageo resistor 5.1k 0402 | 2 | 12 | 0.10 | 0.20 | typical |  | R11 R12 | https://www.mouser.com/c/?q=603-RC0402FR-075K1L
Mouser | 603-RC0402JR-070RL | Yageo | RC0402JR-070RL | Yageo resistor 0R 0402 | 2 | 12 | 0.10 | 0.20 | typical |  | R13 R14 | https://www.mouser.com/c/?q=603-RC0402JR-070RL
Mouser | 603-RC0603FR-0733RL | Yageo | RC0603FR-0733RL | Yageo resistor 33R 0603 | 4 | 22 | 0.10 | 0.40 | typical |  | R5 R6 R7 R8 | https://www.mouser.com/c/?q=603-RC0603FR-0733RL
Mouser | 306-S2BPHSM4TBLFSN | JST | S2B-PH-SM4-TB(LF)(SN) | JST PH 2-pin side-entry SMT header | 1 | 7 | 0.49 | 0.49 | 2026-09-30 | 269 | J2 | https://www.mouser.com/c/?q=306-S2BPHSM4TBLFSN | https://www.jst-mfg.com/product/pdf/eng/ePH.pdf
Mouser | 688-SKRTLA | Alps Alpine | SKRTLAE010 | Alps side-actuated tact switch | 2 | 12 | 0.34 | 0.68 | 2026-09-30 | 2396 | SW4 SW5 | https://www.mouser.com/c/?q=688-SKRTLA | https://tech.alpsalpine.com/e/products/detail/SKRTLAE010/
Mouser | 640-USB4105-GF-A | GCT | USB4105-GF-A | GCT USB-C receptacle, USB 2.0, top mount | 1 | 5 | 0.80 | 0.80 | 2026-09-30 | 420427 | J1 | https://www.mouser.com/c/?q=640-USB4105-GF-A | https://gct.co/files/drawings/usb4105.pdf
Mouser | 511-USBLC6-2SC6 | ST | USBLC6-2SC6 | USB ESD protection, SOT-23-6 | 1 | 7 | 0.49 | 0.49 | 2026-09-30 | 81014 | D2 | https://www.mouser.com/c/?q=511-USBLC6-2SC6 | https://www.st.com/resource/en/datasheet/usblc6-2.pdf
Digi-Key | 828-BMP581CT-ND | Bosch | BMP581 | Bosch barometric pressure sensor, LGA-10 2 x 2 mm | 1 | 5 | 3.07 | 3.07 | 2026-09-30 | 462 | U8 | https://www.digikey.com/en/products/result?keywords=828-BMP581CT-ND | https://www.bosch-sensortec.com/media/boschsensortec/downloads/datasheets/bst-bmp581-ds004.pdf
Digi-Key | DMG2305UX-7DICT-ND | Diodes | DMG2305UX-7 | P-MOSFET 20 V 4.2 A SOT-23 (reverse battery) | 1 | 7 | 0.30 | 0.30 | 2026-09-30 | 75458 | Q2 | https://www.digikey.com/en/products/result?keywords=DMG2305UX-7DICT-ND | https://www.diodes.com/assets/Datasheets/DMG2305UX.pdf
Digi-Key | DSGP.1575.12.4.A.02 | Taoglas | DSGP.1575.12.4.A.02 | Taoglas 12 x 12 x 4 mm GPS L1 / Galileo E1 ceramic patch, SMT | 1 | 5 | 4.25 | 4.25 | 2026-09-30 | 1474 | AE1 | https://www.digikey.com/en/products/result?keywords=DSGP.1575.12.4.A.02 | https://www.taoglas.com/datasheets/DSGP.1575.12.4.A.02.pdf
SendCutSend / Ponoko | cad/out/stl/cover_lens.step |  |  | 1.0 mm clear acrylic or polycarbonate cover lens, 48.0 x 75.9 mm, 5 mm corner radius | 1 | 5 | 3.00 | 3.00 | estimate |  | black mask: vinyl or paint on the inside, window per cad/out/stl/lens_mask.stl
any | e.g. McMaster 92000A017 |  |  | M2 x 5 mm pan-head screws (stainless) | 4 | 20 | 0.10 | 0.40 | estimate |  | PCB to back shell
any |  |  |  | M2 x 6 mm pan-head screws (stainless) | 4 | 20 | 0.10 | 0.40 | estimate |  | front bezel to back shell (through the corner posts)
any |  |  |  | Closed-cell foam tape 0.5 mm, 2 mm strips | 1 | 5 | 1.00 | 1.00 | estimate |  | display gasket
any |  |  |  | Nitrile O-ring cord 1.2 mm | 1 | 5 | 1.00 | 1.00 | estimate |  | case seal, ~280 mm length, ends glued
any | e.g. Amazon 'ePTFE vent patch' |  |  | Breathable PTFE vent sticker, 3-5 mm | 1 | 5 | 0.50 | 0.50 | estimate |  | over the 0.8 mm barometer vent
any |  |  |  | Acoustic mesh / speaker membrane 12 x 9 mm | 1 | 5 | 0.50 | 0.50 | estimate |  | under the speaker grille
any |  |  |  | PLA / PETG / TPU filament | 1 | 5 | 2.00 | 2.00 | estimate |  | ~35 g for a standard case

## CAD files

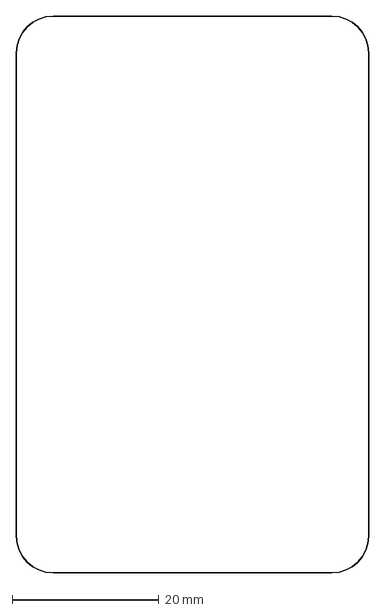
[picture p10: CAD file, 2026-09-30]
print/cover_lens_outline.dxf
48.0 x 75.9 mm

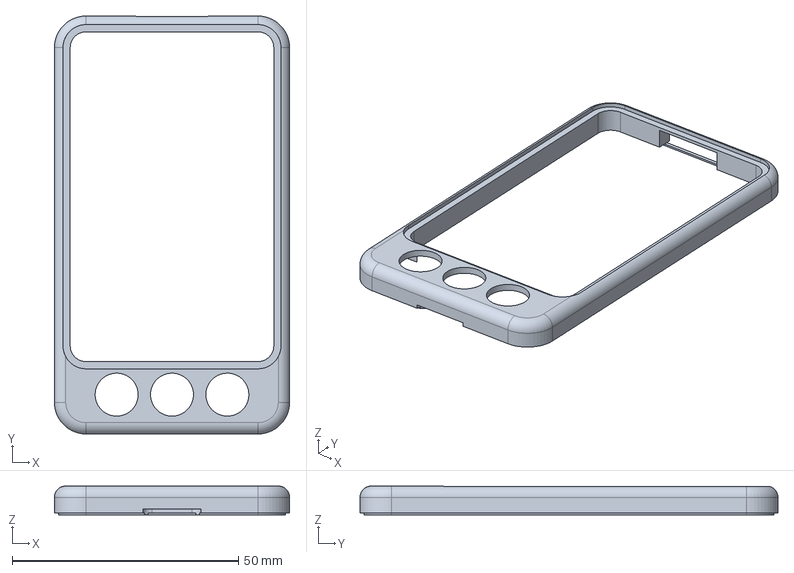
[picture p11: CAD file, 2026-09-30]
print/step/front_bezel_aero.step
52.0 x 92.4 x 6.40 mm

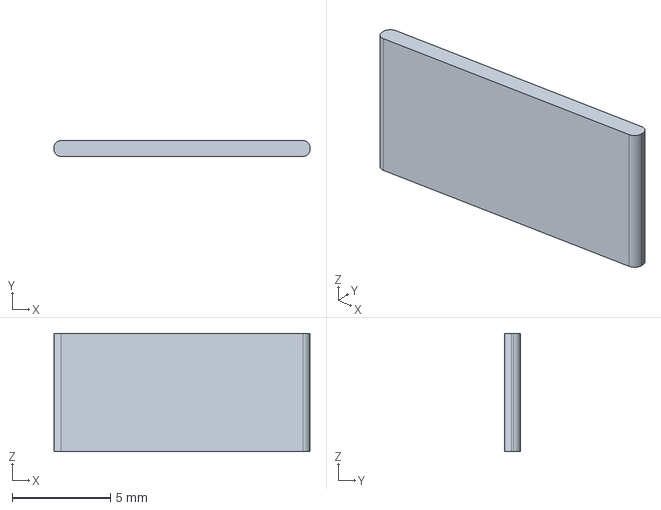
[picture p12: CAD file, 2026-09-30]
print/step/usb_flap.step
13.0 x 0.8 x 6.00 mm

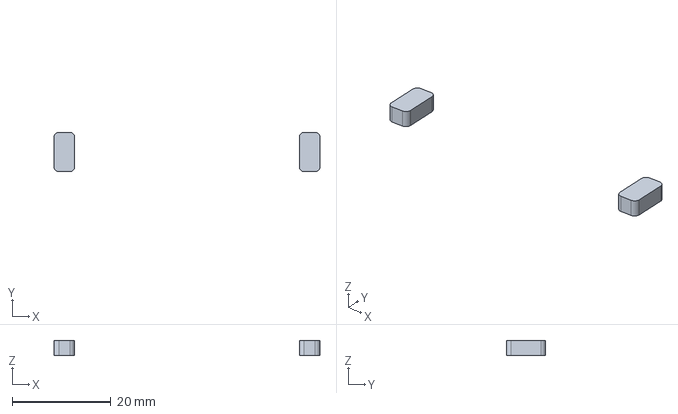
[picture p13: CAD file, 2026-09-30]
print/step/side_buttons_x2.step
54.0 x 8.00 x 3.00 mm

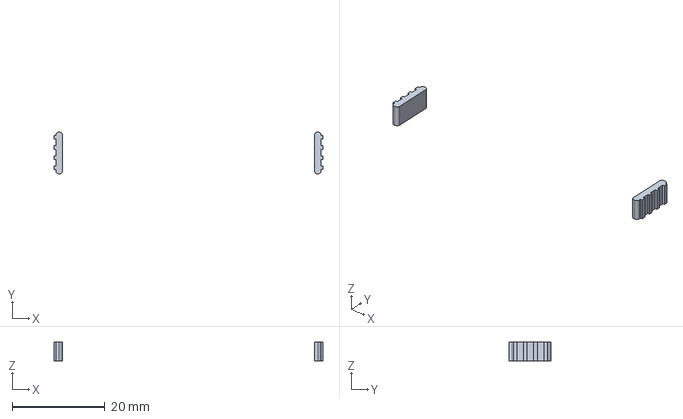
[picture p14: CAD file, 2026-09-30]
print/step/button_covers_rugged.step
58.0 x 9.00 x 4.00 mm

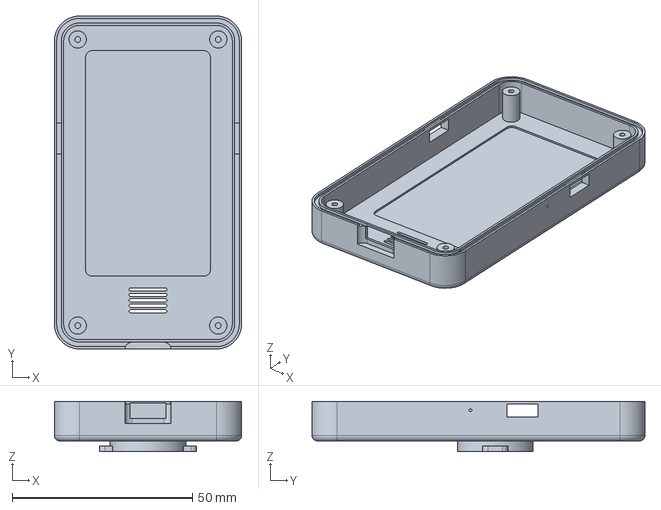
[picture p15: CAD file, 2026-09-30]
print/step/back_shell_standard.step
52.0 x 92.4 x 14.0 mm

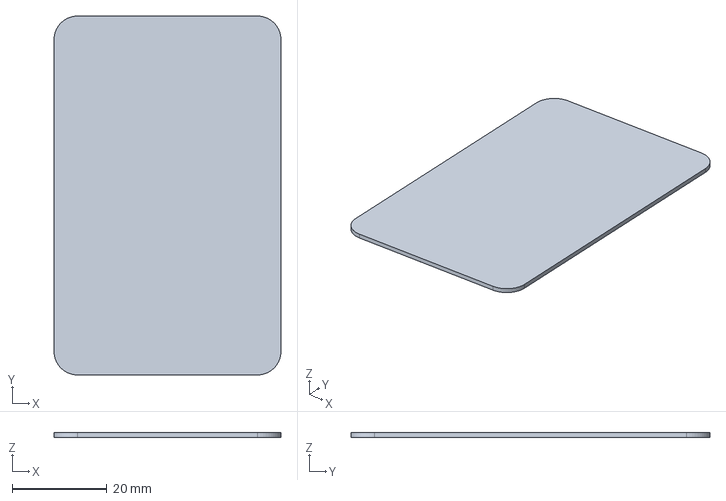
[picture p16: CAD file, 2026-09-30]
print/step/cover_lens.step
48.0 x 75.9 x 1.00 mm

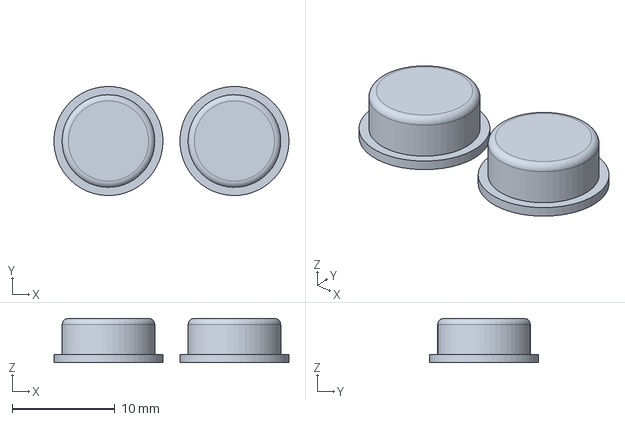
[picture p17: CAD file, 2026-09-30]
print/step/key_caps_x2.step
22.8 x 10.6 x 4.30 mm

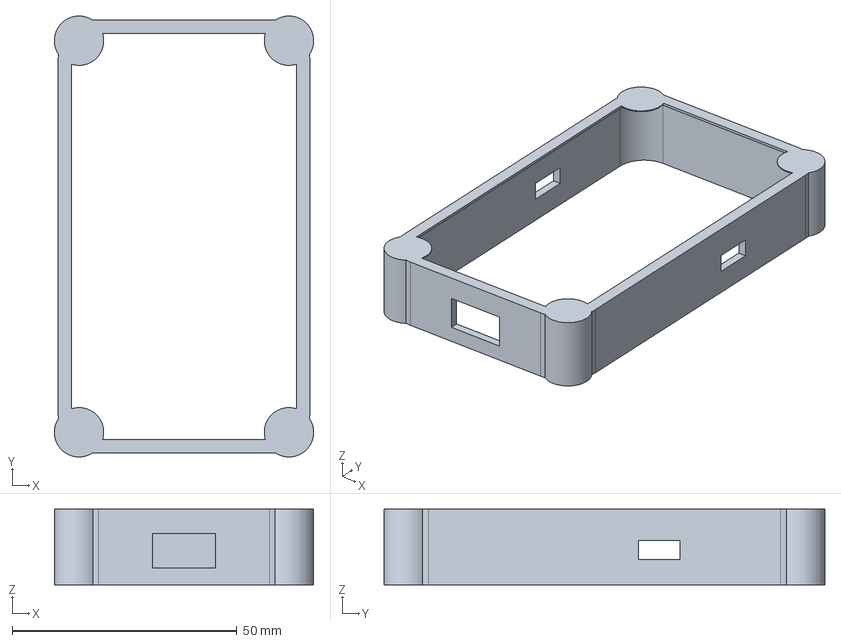
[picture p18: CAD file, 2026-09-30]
print/step/bumper_rugged.step
57.7 x 98.1 x 16.8 mm

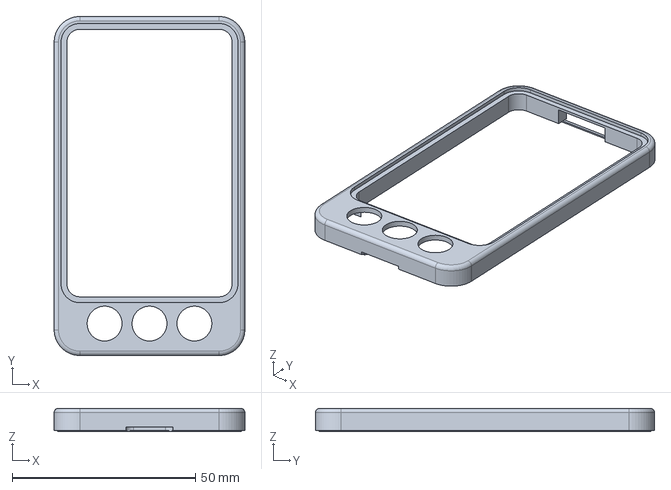
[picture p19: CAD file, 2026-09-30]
print/step/front_bezel_standard.step
52.0 x 92.4 x 6.40 mm

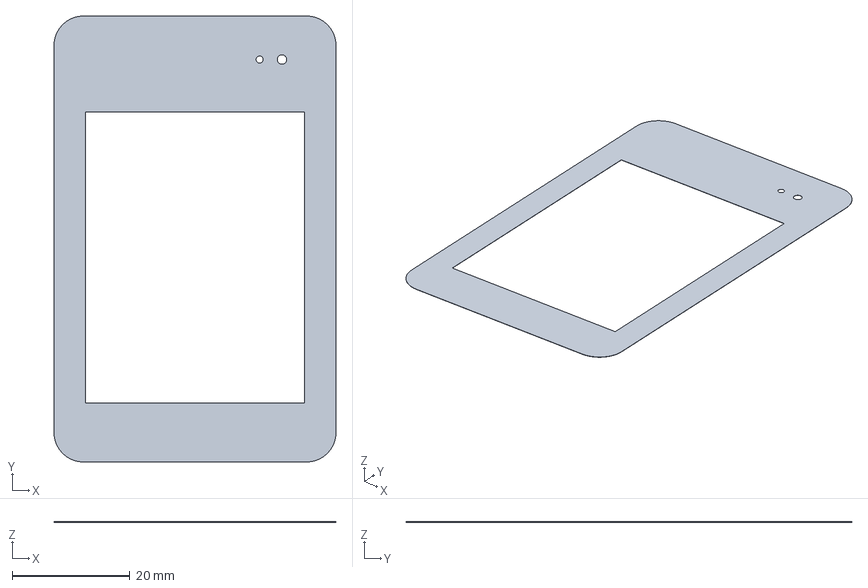
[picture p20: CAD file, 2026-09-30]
print/step/lens_mask.step
48.0 x 75.9 x 0.05 mm

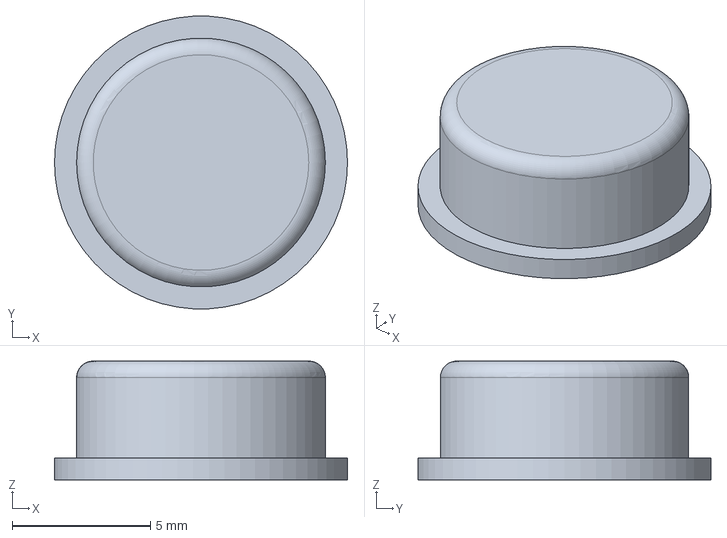
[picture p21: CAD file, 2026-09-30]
print/step/key_cap_primary.step
10.6 x 10.6 x 4.30 mm

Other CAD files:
print/step/back_shell_aero.step
print/back_shell_aero.stl
print/back_shell_standard.stl
print/bumper_rugged.stl
print/button_covers_rugged.stl
print/front_bezel_aero.stl
print/front_bezel_standard.stl
print/key_cap_primary.stl
print/key_caps_x2.stl
print/side_buttons_x2.stl
print/usb_flap.stl

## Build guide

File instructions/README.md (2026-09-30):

# Build instructions — OpenCycle v0.2

The path from this repo to a working bike computer. Follow the files in order; each one ends with a check you should pass before moving on.

| Step | File | Time | Cost (first unit) |
|---|---|---|---|
| 1 | [01-order-parts.md](01-order-parts.md) — electronics from Mouser + Digi-Key, battery, lens, small hardware, tools | 1 h to order, ~1 week to arrive | ~$89 parts + tools |
| 2 | [02-order-pcb.md](02-order-pcb.md) — boards (and optionally assembly) from JLCPCB | 30 min to order, 1–2 weeks | ~$25–40 for 5 bare boards + stencil |
| 3 | [03-print-case.md](03-print-case.md) — shells, keys, buttons | ~5 h printer time | ~$1 filament |
| 4 | [04-assemble-board.md](04-assemble-board.md) — solder both sides | 3–5 h | — |
| 5 | [05-bring-up.md](05-bring-up.md) — first power-on, rail checks, each chip answers | 2 h | — |
| 6 | [06-final-assembly.md](06-final-assembly.md) — display, lens, battery, close the case | 1 h | — |
| 7 | [07-next-steps.md](07-next-steps.md) — firmware plan, UI, open questions | — | — |

Order steps 1 and 2 on the same day; print the case while you wait.

Everything referenced here is generated and committed: Gerbers and BOMs in [`pcb/fab/`](../pcb/fab), print files in [`print/`](../print), the parts list with links in [`docs/sourcing/bom-v0.2.md`](../docs/sourcing/bom-v0.2.md).

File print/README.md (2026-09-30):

# Print files

Generated by `tools/export_print.py` from `cad/` — do not edit the STLs; change `cad/params.py` and re-export. Every file is already oriented for printing (flat side on the bed). STEP copies for editing are in `step/`.

| File | Qty | Material | Orientation | Notes |
|---|---|---|---|---|
| `back_shell_standard.stl` | 1 | PETG (or ASA; PLA softens on a black device in sun) | rim down | Floor, grille and Garmin boss print as the top surfaces; no supports. The USB-C counterbore and button holes bridge. |
| `front_bezel_standard.stl` | 1 | PETG / PLA | front face down | Smooth bed finish on the visible face. Key holes are 9.5 mm; check the caps slide freely. |
| `back_shell_aero.stl`, `front_bezel_aero.stl` | 1 each | as above | as above | Alternative style with larger edge radii (print instead of the standard pair). |
| `bumper_rugged.stl` | 1 | TPU 95A | as modelled | Optional rugged sleeve; slides over the standard shells. |
| `button_covers_rugged.stl` | 1 | TPU 95A | as modelled | Only with the bumper. |
| `key_caps_x2.stl` | 1 | PETG / PLA | flange down | Left and centre keys. |
| `key_cap_primary.stl` | 1 | PETG / PLA in the accent colour | flange down | Right key (start / pause). |
| `side_buttons_x2.stl` | 1 | PETG or TPU | flat | Power (left) and menu (right) plungers. |
| `usb_flap.stl` | 1 | TPU 95A | flat | Optional dust flap for the USB-C port. |

Not printed: `step/cover_lens.step` and `cover_lens_outline.dxf` (1.0 mm clear acrylic or polycarbonate, laser-cut, 48.0 × 75.9 mm with 5 mm corners) and `step/lens_mask.step` (the black print on the lens underside with windows for the screen, light sensor and charge LED — use black vinyl or paint with the windows masked).

## Settings that worked in the model

- 0.2 mm layers, 0.4 mm nozzle, 4 walls, 5 top / 4 bottom layers, 30 % gyroid.
- Shells: no supports needed. If your printer struggles with the 10 mm USB bridge, enable supports only for that opening.
- TPU: 20–25 mm/s, no retraction tricks needed.
- Check fit before assembly: the PCB drops onto the four standoffs, the key caps rise freely in the bezel, the side plungers move 0.25 mm and click the switches.

Estimated material: ~14 cm³ (back) + ~5 cm³ (bezel) + keys ≈ 25 g PETG per standard case.

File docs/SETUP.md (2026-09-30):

# Toolchain setup

Tested on Ubuntu 24.04, Python 3.11, KiCad 7.0.11.

```bash
# KiCad 7 (pcbnew Python module, kicad-cli, symbol + footprint libraries)
sudo apt-get install -y --no-install-recommends kicad kicad-footprints kicad-symbols

# Python packages
pip install cadquery numpy scipy numba pillow kiutils cairosvg imageio imageio-ffmpeg

# Freerouting (autorouter): needs Java 17+ and a virtual display for headless runs
sudo apt-get install -y openjdk-21-jre-headless xvfb
# pcb/autoroute.py downloads freerouting-1.9.0.jar into pcb/ on first run (git-ignored)

# Optional: KiCad 9 CLI for ERC only (KiCad 7's CLI has no ERC). Extract it next to KiCad 7
# instead of upgrading, because the pipeline scripts use the KiCad 7 Python API.
#   add the kicad-9.0-releases PPA, `apt-get download kicad`, `dpkg -x kicad_*.deb /opt/kicad9`,
#   then: LD_LIBRARY_PATH=/opt/kicad9/usr/lib/x86_64-linux-gnu /opt/kicad9/usr/bin/kicad-cli sch erc ...
```

Notes:
- The PCB scripts import `pcbnew`, which ships with KiCad and targets the **KiCad 7** API (`FP_SHAPE`, `FP_ZONE`, `SetProperty`). KiCad 8/9 renamed some of these; porting is a small job.
- `pcb/design.py` expects KiCad libraries at `/usr/share/kicad/footprints/` and `/usr/share/kicad/symbols/`. On macOS/Windows change `FP` in `design.py` and `LIB` in `symlib.py`.
- The board opens in KiCad 7+ directly (`pcb/opencycle.kicad_pro`); `fp-lib-table` and `sym-lib-table` in `pcb/` point at the local library.
- Viewer and UI renders: a static file server (`python3 -m http.server -d viewer`); screenshots use Playwright + Chromium (`docs/ui/shoot.mjs`).

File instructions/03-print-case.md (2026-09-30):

# 3 · Print the case

Files and settings: [`print/README.md`](../print/README.md). Short version:

1. Print `back_shell_standard.stl` (rim down) and `front_bezel_standard.stl` (front face down) in PETG: 0.2 mm layers, 4 walls, 30 % gyroid, no supports.
2. Print `key_caps_x2.stl` and `key_cap_primary.stl` (accent colour), flange down, and `side_buttons_x2.stl` flat.
3. Optional: `bumper_rugged.stl` + `button_covers_rugged.stl` in TPU; `usb_flap.stl` in TPU.

## Check

- The bare PCB drops onto the four standoffs of the back shell and the M2 × 5 screws bite.
- Key caps slide through the bezel holes without catching; the flange stops them.
- The two halves close with the O-ring cord in the groove (try it before you have electronics inside).
- A USB-C cable plug reaches fully into the counterbore (with the board fitted in step 6).

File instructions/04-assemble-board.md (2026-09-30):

# 4 · Assemble the board

Use the assembly drawings: [`pcb/fab/assembly_front.pdf`](../pcb/fab/assembly_front.pdf) and [`pcb/fab/assembly_back.pdf`](../pcb/fab/assembly_back.pdf) (reference designators are on the fab layer, not the silkscreen). The BOM with designators: [`pcb/fab/bom_jlcpcb.csv`](../pcb/fab/bom_jlcpcb.csv).

The board has parts on both sides. Solder the **back first** with normal paste, then the **front with low-temperature paste**, so the first side never re-melts.

## 1 · Back side (battery side) — SAC305 paste, stencil, hot plate

Parts: U1 ESP32-S3 module, U2 BL652, U8 BMP581, U7 MAX98357A, U6 charger, Q2, D2, J1 USB-C, J2 JST-PH, SW4/SW5 side switches, and all back-side passives.

1. Tape the board down, align the **bottom** stencil, spread paste once.
2. Place parts with tweezers. Orientation: pin-1 marks per `assembly_back.pdf`. The ESP32 antenna overhangs nothing — it ends flush with the right board edge; the BL652 antenna end is at the left edge.
3. Reflow on the hot plate (back side up). Let it cool completely.
4. Inspect: no bridges on the BMP581 and the QFN; ESP32 and BL652 castellations wetted along every edge; USB-C shell tabs soldered.

## 2 · Front side (display side) — low-temperature paste (Sn42Bi58), hot air

Parts: AE1 GPS patch, U3 MAX-M10S, J3 FFC connector, U4 light sensor, D1 LED, U5 LDO, Q1 + R5–R10 backlight, SW1–SW3 key switches, front-side passives.

1. Support the board on a frame so the back-side parts hang free; align the **top** stencil and paste.
2. Place parts. **J3**: latch side toward the bottom edge, pin 1 on the left. **AE1**: the feed side (single small pad) faces the GPS module on the left. **SW1–SW3** are turned 90° (that's intentional).
3. Reflow with hot air (or an iron for the leaded parts). Keep the back side below ~180 °C.
4. Solder the speaker leads to the LS1 pads on the back (red = +, marked "+") once the case is ready (step 6).

## Check

- No solder bridges anywhere on J3 (0.5 mm pitch) — use flux and a drag tip if needed.
- Nothing is tall enough to foul the case: all parts are within the height zones the placement check enforces; if you substitute a part, check its height against `docs/CAD.md`.

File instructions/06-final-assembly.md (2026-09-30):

# 6 · Final assembly

1. **Lens:** apply the black mask to the inside of the 1.0 mm lens (screen window + the two small windows top-right). Glue the lens into the bezel pocket (thin bead of clear silicone or 3M VHB strip on the ledge).
2. **Display:** stick the 0.5 mm foam strips around the display frame; place the display face-down into the bezel window; the FFC tail exits at the bottom.
3. **Keys:** drop the three key caps into the bezel holes from the inside (accent cap on the right).
4. **Vent and speaker:** put the ePTFE sticker over the 0.8 mm vent inside the right wall of the back shell and the acoustic mesh over the speaker grille; set the speaker (cone toward the grille) on its foam in the pocket at the bottom of the shell. Solder its leads to LS1 on the board (red to "+").
5. **Battery:** place the Adafruit 258 in the floor pocket, leads toward the bottom. Plug it into J2 **after** checking polarity again.
6. **Board:** fold the display FFC 180° behind the panel and insert it into J3 (contacts toward the board), close the latch. Lower the board onto the standoffs (display side up) and fix it with 4 × M2 × 5.
7. **Side buttons:** insert the two plungers from the inside of the back shell.
8. **Seal and close:** lay the 1.2 mm O-ring cord in the groove (glue the ends), press the bezel onto the back shell, fix it with 4 × M2 × 6 through the corner posts.
9. Clip it into a Garmin quarter-turn mount and check it locks. The mount boss is an approximation — if it's loose, adjust `MOUNT_*` in `cad/params.py`.

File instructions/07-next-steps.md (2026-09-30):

# 7 · Next steps

## Firmware (not started — by design)

The owner wants to finish the UI design before firmware work starts. When it does:

- **ESP32-S3:** ESP-IDF + LVGL 9. Display ST7789 over SPI at 40–80 MHz with two PSRAM frame buffers; the UI spec is [`docs/UI.md`](../docs/UI.md) (Lucent) and the reference renderer is `viewer/ui/screens_color.js`. Pin map: [`docs/HARDWARE.md`](../docs/HARDWARE.md).
- **Storage:** FIT files for rides (Garmin FIT SDK), GPX routes, map tiles; LittleFS on the 16 MB flash.
- **GPS:** UBX over UART; power-save / backup mode when stopped.
- **BL652:** Nordic SDK with the ANT+BLE SoftDevice (S332): forwards heart-rate, power, cadence and radar data to the ESP32 over UART. Read the ANT licence terms before publishing firmware.
- **Phone app:** routes, tile generation, ride sync (Web Bluetooth or React Native).

## Hardware follow-ups after the first build

- Measure GPS time-to-fix and C/N0 in the case; BLE/Wi-Fi range with the case closed.
- Measure backlight current and panel temperature at 100 % PWM; adjust the 33 Ω ballasts if needed.
- Check the Garmin mount fit; tweak `cad/params.py`.
- Choose a licence (CERN-OHL-S for hardware + MIT for software is the working plan).

Open questions live in [`docs/DECISIONS.md`](../docs/DECISIONS.md).

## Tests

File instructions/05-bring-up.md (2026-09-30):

# 5 · Bring-up (first power-on)

Do these in order and stop at the first failure. Numbers are what the design expects; small deviations are fine.

## Before any power

1. Visual inspection under magnification, both sides.
2. Resistance to GND (meter, board unpowered): **VBAT** (C16), **+3V3** (C12), **VBUS** (C14) — each should read more than ~1 kΩ after the caps charge. A few ohms = short; find it before continuing.
3. **Battery polarity:** with the meter on the Adafruit 258 plug, find the red (+) lead. Compare with J2: **pin 2 = +, pin 1 = −** (see `assembly_back.pdf`). If the cable is the other way round, move the two crimp pins in the JST housing (lift the latch tabs) rather than forcing it. Q2 protects the board if you get it wrong, but check anyway.

## Power from a bench supply (no battery yet)

4. Supply **3.7 V, 100 mA current limit** into J2 (+ on pin 2). Expect < 60 mA once the ESP32 idles. +3V3 must read 3.30 V ± 2 % at C12. VBAT at C16 reads the supply voltage (Q2 conducting).
5. **Do not plug in USB-C while the bench supply is connected**: the charger would try to charge the supply. The board has no USB-to-system power path — it always runs from VBAT (battery), and USB only charges the battery and carries data.
6. Disconnect the supply and connect the real battery (polarity checked in step 3). Current draw at idle matches step 4.

## ESP32

7. Connect USB-C to a computer (battery connected): a new USB device `303a:1001` (Espressif USB JTAG/serial) appears.
8. `esptool.py --chip esp32s3 flash_id` → reports a 16 MB flash; `esptool.py chip_id` works. If the chip does not show up: hold the **left front key** (IO0) while re-applying power to force download mode.
9. Flash a test build that: prints over USB serial, toggles `LCD_BL` (IO21), scans I²C (IO8/IO18) → expect **0x29** (LTR-303) and **0x46** (BMP581).

## Display

10. Plug the display FFC into J3 (contacts facing the board, latch closed), init the ST7789 in 4-wire SPI (SCK IO12, MOSI IO11, CS IO10, DC IO9, RST IO14), draw colour bars. Raise the backlight PWM slowly and check the panel stays cool at 100 %.

## GPS

11. Open UART on IO38 (RX) / IO39 (TX) at 9600 baud: NMEA sentences appear within a second of power-up. Outdoors with a clear sky: a 3D fix within ~30–60 s cold.

## BL652 (ANT+/BLE)

12. Connect the Tag-Connect TC2030-NL cable to **J4** and a SWD probe. `nrfjprog --readregs` (or pyOCD) must find an nRF52832. Flash a UART echo test; check it answers the ESP32 on IO41/IO42.

## Audio, keys, charging

13. Enable the amp (IO3 high) and play a 1 kHz tone over I²S (IO15/16/17) → speaker plays.
14. Each key pulls its GPIO low: KEY_L IO0, KEY_C IO4, KEY_R IO5, BTN_PWR IO6, BTN_MENU IO7.
15. With USB-C plugged in and the battery not full: the charge LED lights; battery current ≈ 500 mA while charging (CC phase); VBAT_SENSE (IO1) reads about half the battery voltage.

Write down anything that deviates in an issue or in `docs/DECISIONS.md`.

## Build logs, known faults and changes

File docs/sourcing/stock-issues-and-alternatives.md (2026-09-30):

# Stock issues and alternatives

What didn't work out during sourcing, and what replaced it. Stock status as of 2026-09-29/30.

| Wanted | Problem | Replacement | Notes |
|---|---|---|---|
| Raytac MDBT50Q-1MV2 (nRF52840) | Not at Digi-Key/Mouser | SparkFun WRL-21605 ($8.95) for v0.1; v0.2 moves to ESP32-S3 + BL652 | u-blox NINA-B306 is stocked at DK/Mouser but has no KiCad footprint |
| Sharp LS027B7DH01 | Digi-Key 0 stock, 28-week lead; Adafruit breakout out of stock | Colour TFT for v0.2 | Tindie / AliExpress remain for the mono build |
| JDI LPM027M128C | Switch Science discontinued; AliExpress only | Not used | Best power profile of any colour option |
| Bosch BMP280 (bare) | Digi-Key 0, 10k MOQ | → LPS22HH (v0.1 plan) → BMP581 (v0.2) | |
| ST LPS22HHTR | Mouser/Digi-Key/Newark 0; Future Electronics 6,795 | BMP581 | |
| ST LPS22DFTR | Mouser 0 until Apr 2027 | BMP581 | |
| Infineon DPS368 / DPS310 | Mouser 0 (DPS368 495 due Oct 2026); DPS310 0 at DK | BMP581 | |
| Bosch BMP390 | Mouser 16-week lead | BMP581 | |
| Bosch BMP581 | Mouser 0 (159,933 on order) | **Digi-Key 828-BMP581CT-ND, 462 in stock** | Second vendor needed for this one part |
| ST LIS3DHTR | Mouser 0 (123,866 on order, 24-week lead); Digi-Key 0 | BMA400 (Mouser, 104k) — then dropped for v0.2 | |
| ST LIS2DH12TR | Mouser 0 until Apr 2027 | — | |
| Bosch BMA400 | In stock, but the pin table couldn't be read from the datasheet text | Dropped for v0.2 | Power button handles wake |
| TI TLV75733PDBVR | Mouser 0 until Dec 2026 | Diodes AP7361C-33ER-13 (1 A, SOT-223) | |
| JST SM02B-SRSS-TB | Mouser 0 until Dec 2026 | JST S2B-PH-SM4-TB (matches the Adafruit battery's JST-PH) | |
| Taoglas DSGP patch | Mouser 331 only | Abracon APAE1575R1540AZDB2F-T (pin-fed, $2.11, 1,218) as backup | Abracon datasheet lacks pin position |
| HRO TYPE-C-31-M-12 | Not at US distributors | GCT USB4105-GF-A | |
| Sunlord SWPA3012 inductor | Not at US distributors | Taiyo Yuden NR3015 (v0.1); not needed in v0.2 | |
| MAX98357AETE+T | Mouser says it will stop carrying it | Still in stock at Mouser (10,971) and Digi-Key (30,936) | Buy spares |
| Same Sky speaker variants | -078L100-67 is SMT, non-stocked, 500 MOQ | -078L100 (wires) or -078SP-67 (pads) | |
| Freerouting (autorouter) | Maven/GitHub release downloads blocked in the build environment | Custom router in `pcb/router.py` | Environment issue, not a sourcing one |

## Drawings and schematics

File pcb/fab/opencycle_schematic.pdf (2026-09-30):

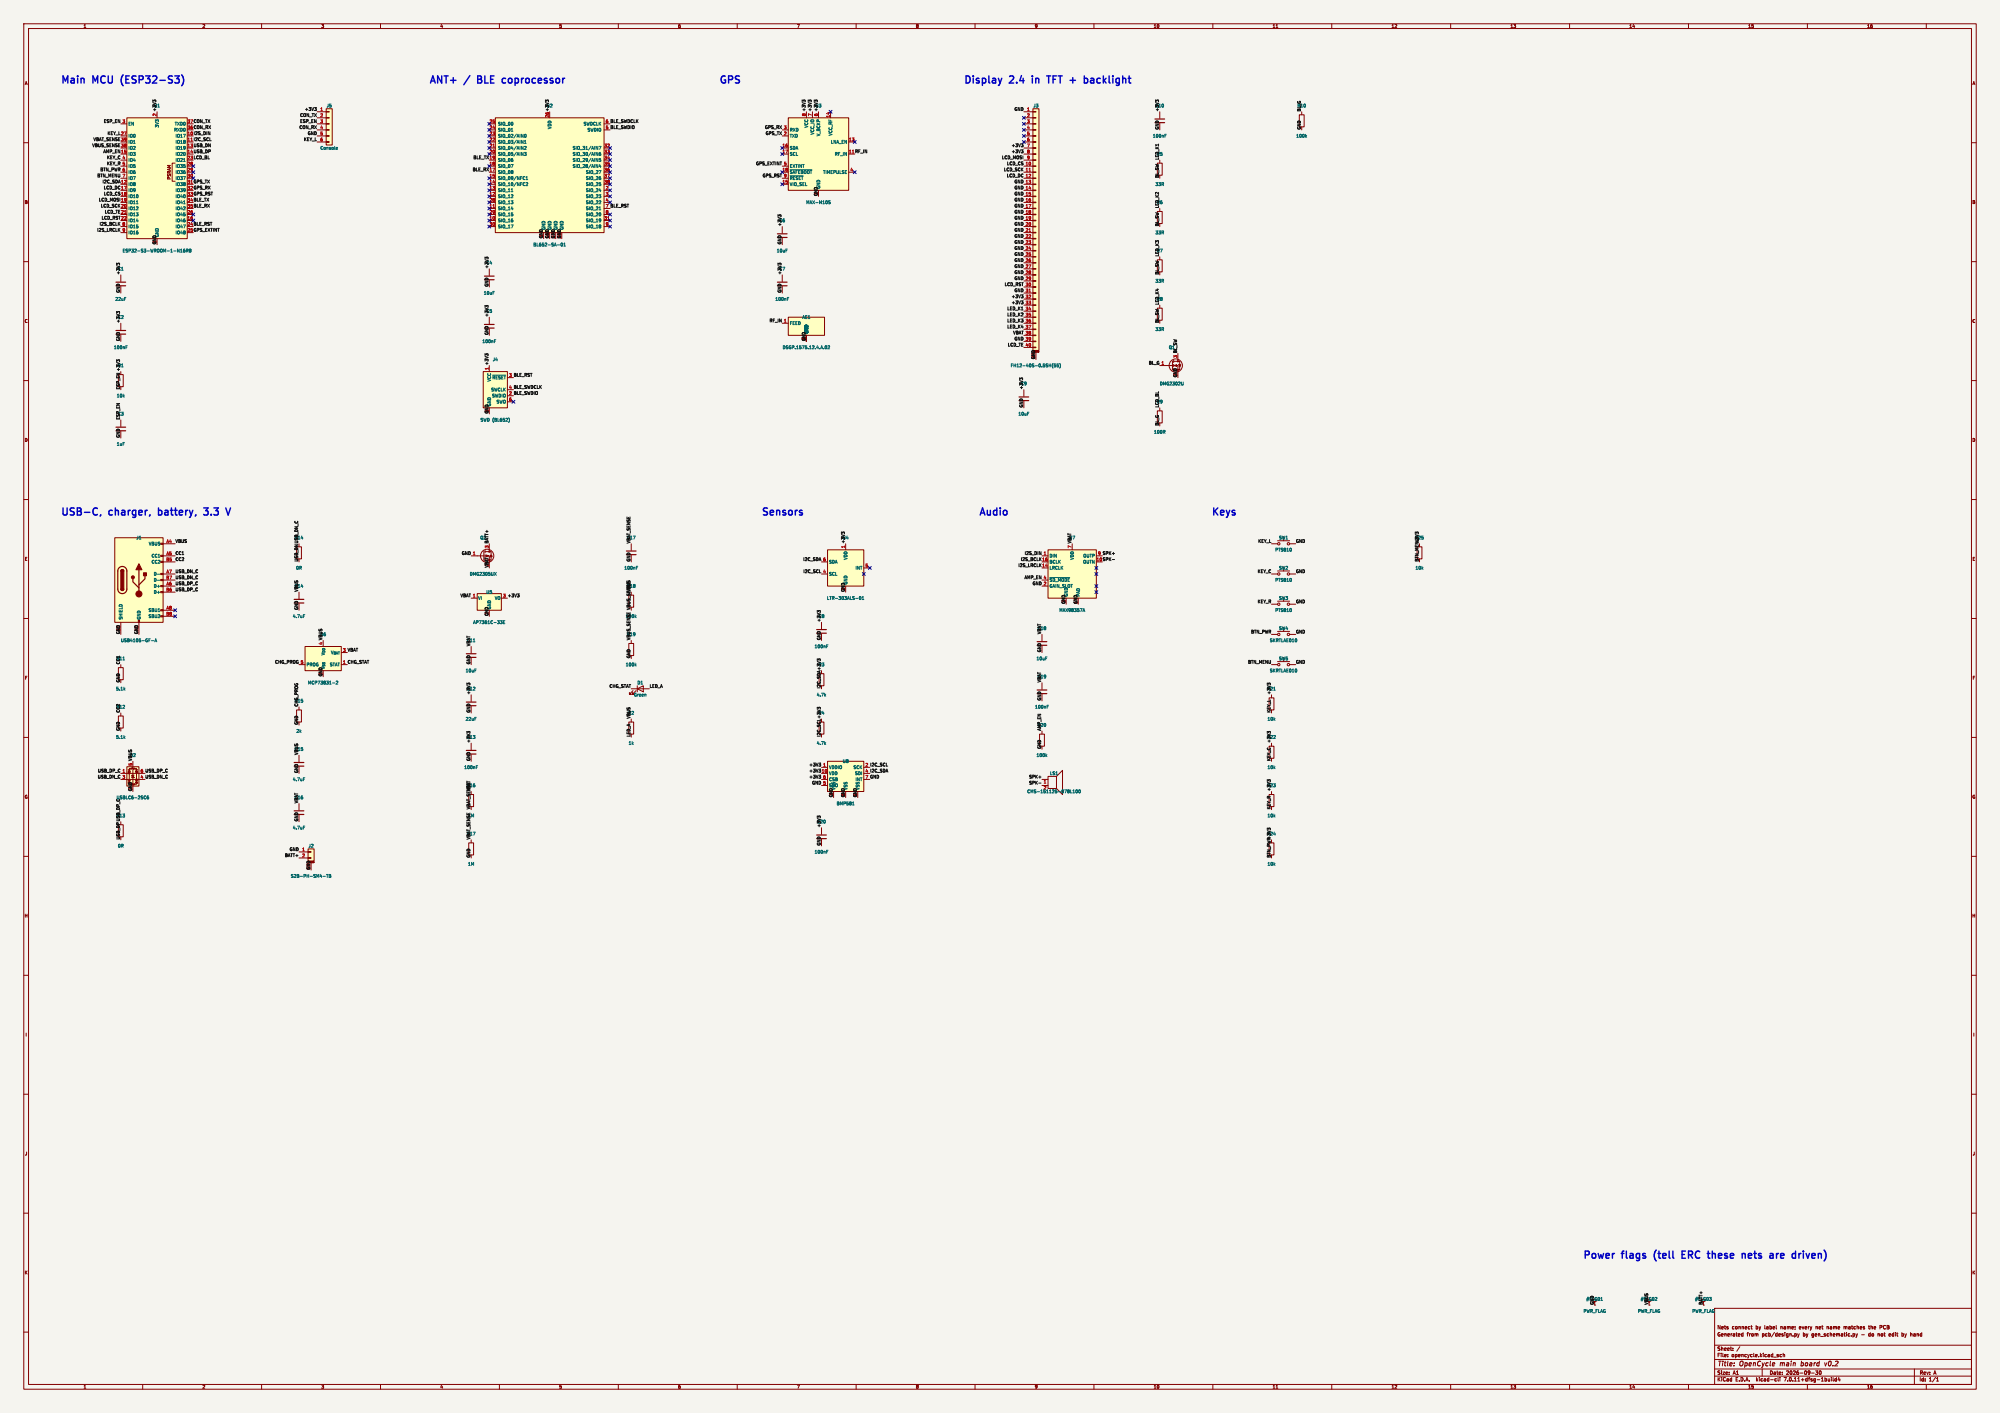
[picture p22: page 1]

Display 2.4 in TFT + backlight

1 SIO_16 10 SIO_14 11 SIO_12 12 SIO_11 13 SIO_10/NFC2 14 SIO_09/NFC1 15 GND 16 SIO_08 17 SIO_07 18 SIO_06 19 SIO_24 2 SIO_05/AIN3 20 SIO_04/AIN2 21 SIO_03/AIN1 22 SIO_02/AIN0 23 SIO_01 24 SIO_00 25 VDD 26 GND 27 SIO_13 28 SIO_15 29 SIO_23 3 SIO_17 30 SIO_19 31 SIO_31/AIN7 32 SIO_30/AIN6 33 SIO_29/AIN5 34 SIO_28/AIN4 35 SIO_27 36 SIO_26 37 SIO_25 38 GND 39 SIO_22 4 SWDIO 5 SWDCLK 6 SIO_21 7 SIO_20 8 SIO_18 9 U2 BL652-SA-01 C5

1 SWDIO 2 ~{RESET}3 SWCLK 4 GND

Power flags (tell ERC these nets are driven)

Id: 1/1 Title: OpenCycle main board v0.2

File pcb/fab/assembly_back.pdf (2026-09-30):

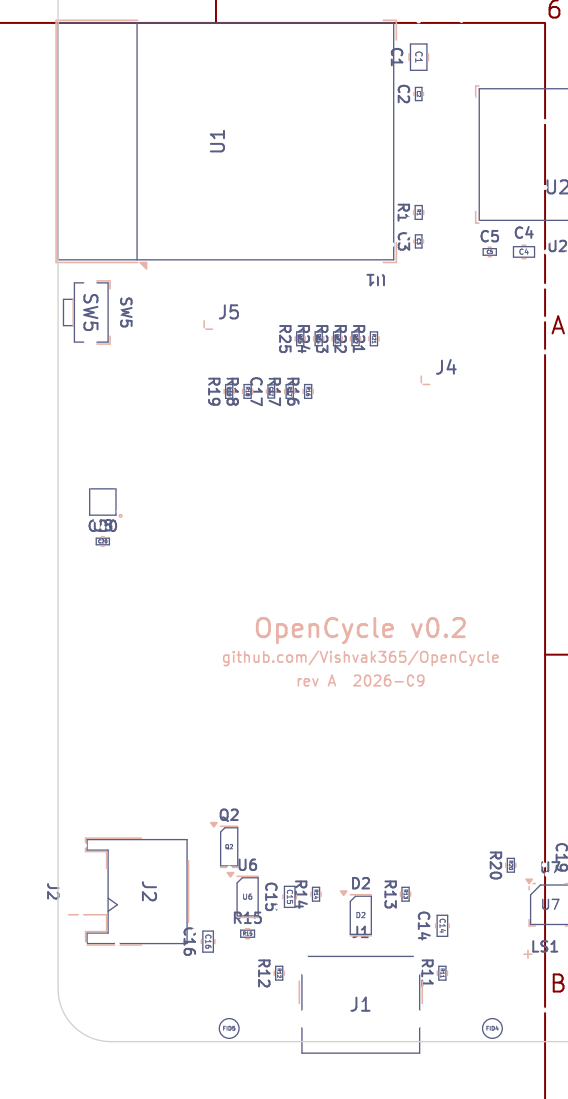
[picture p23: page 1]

FID6 github.com/Vishvak365/OpenCycle OpenCycle v0.2

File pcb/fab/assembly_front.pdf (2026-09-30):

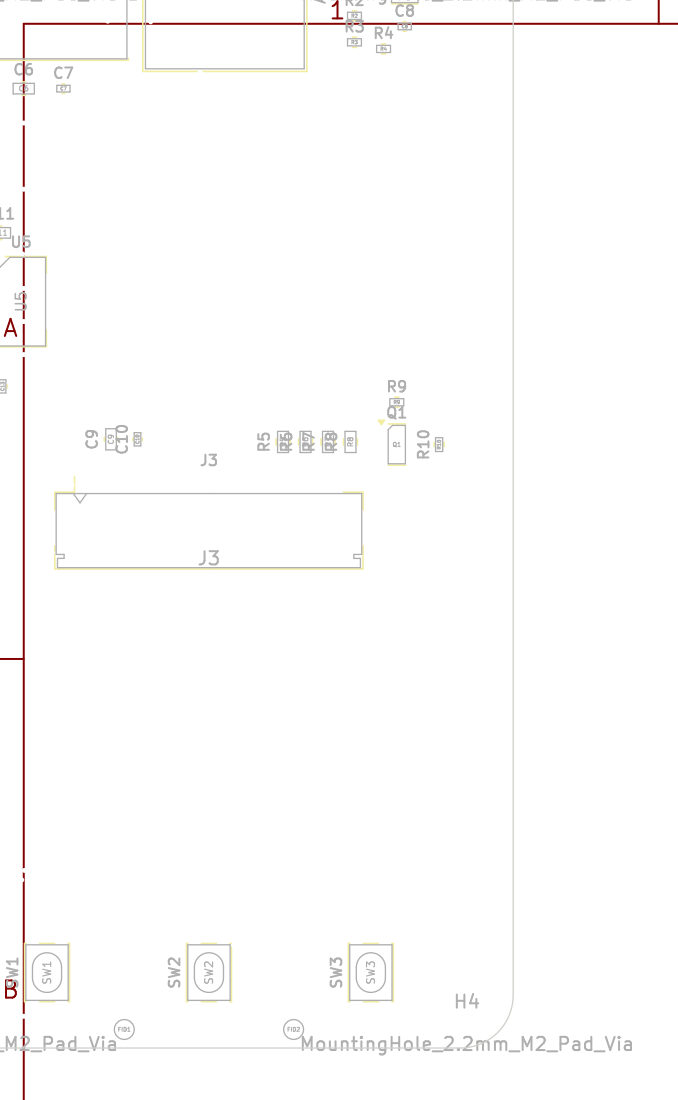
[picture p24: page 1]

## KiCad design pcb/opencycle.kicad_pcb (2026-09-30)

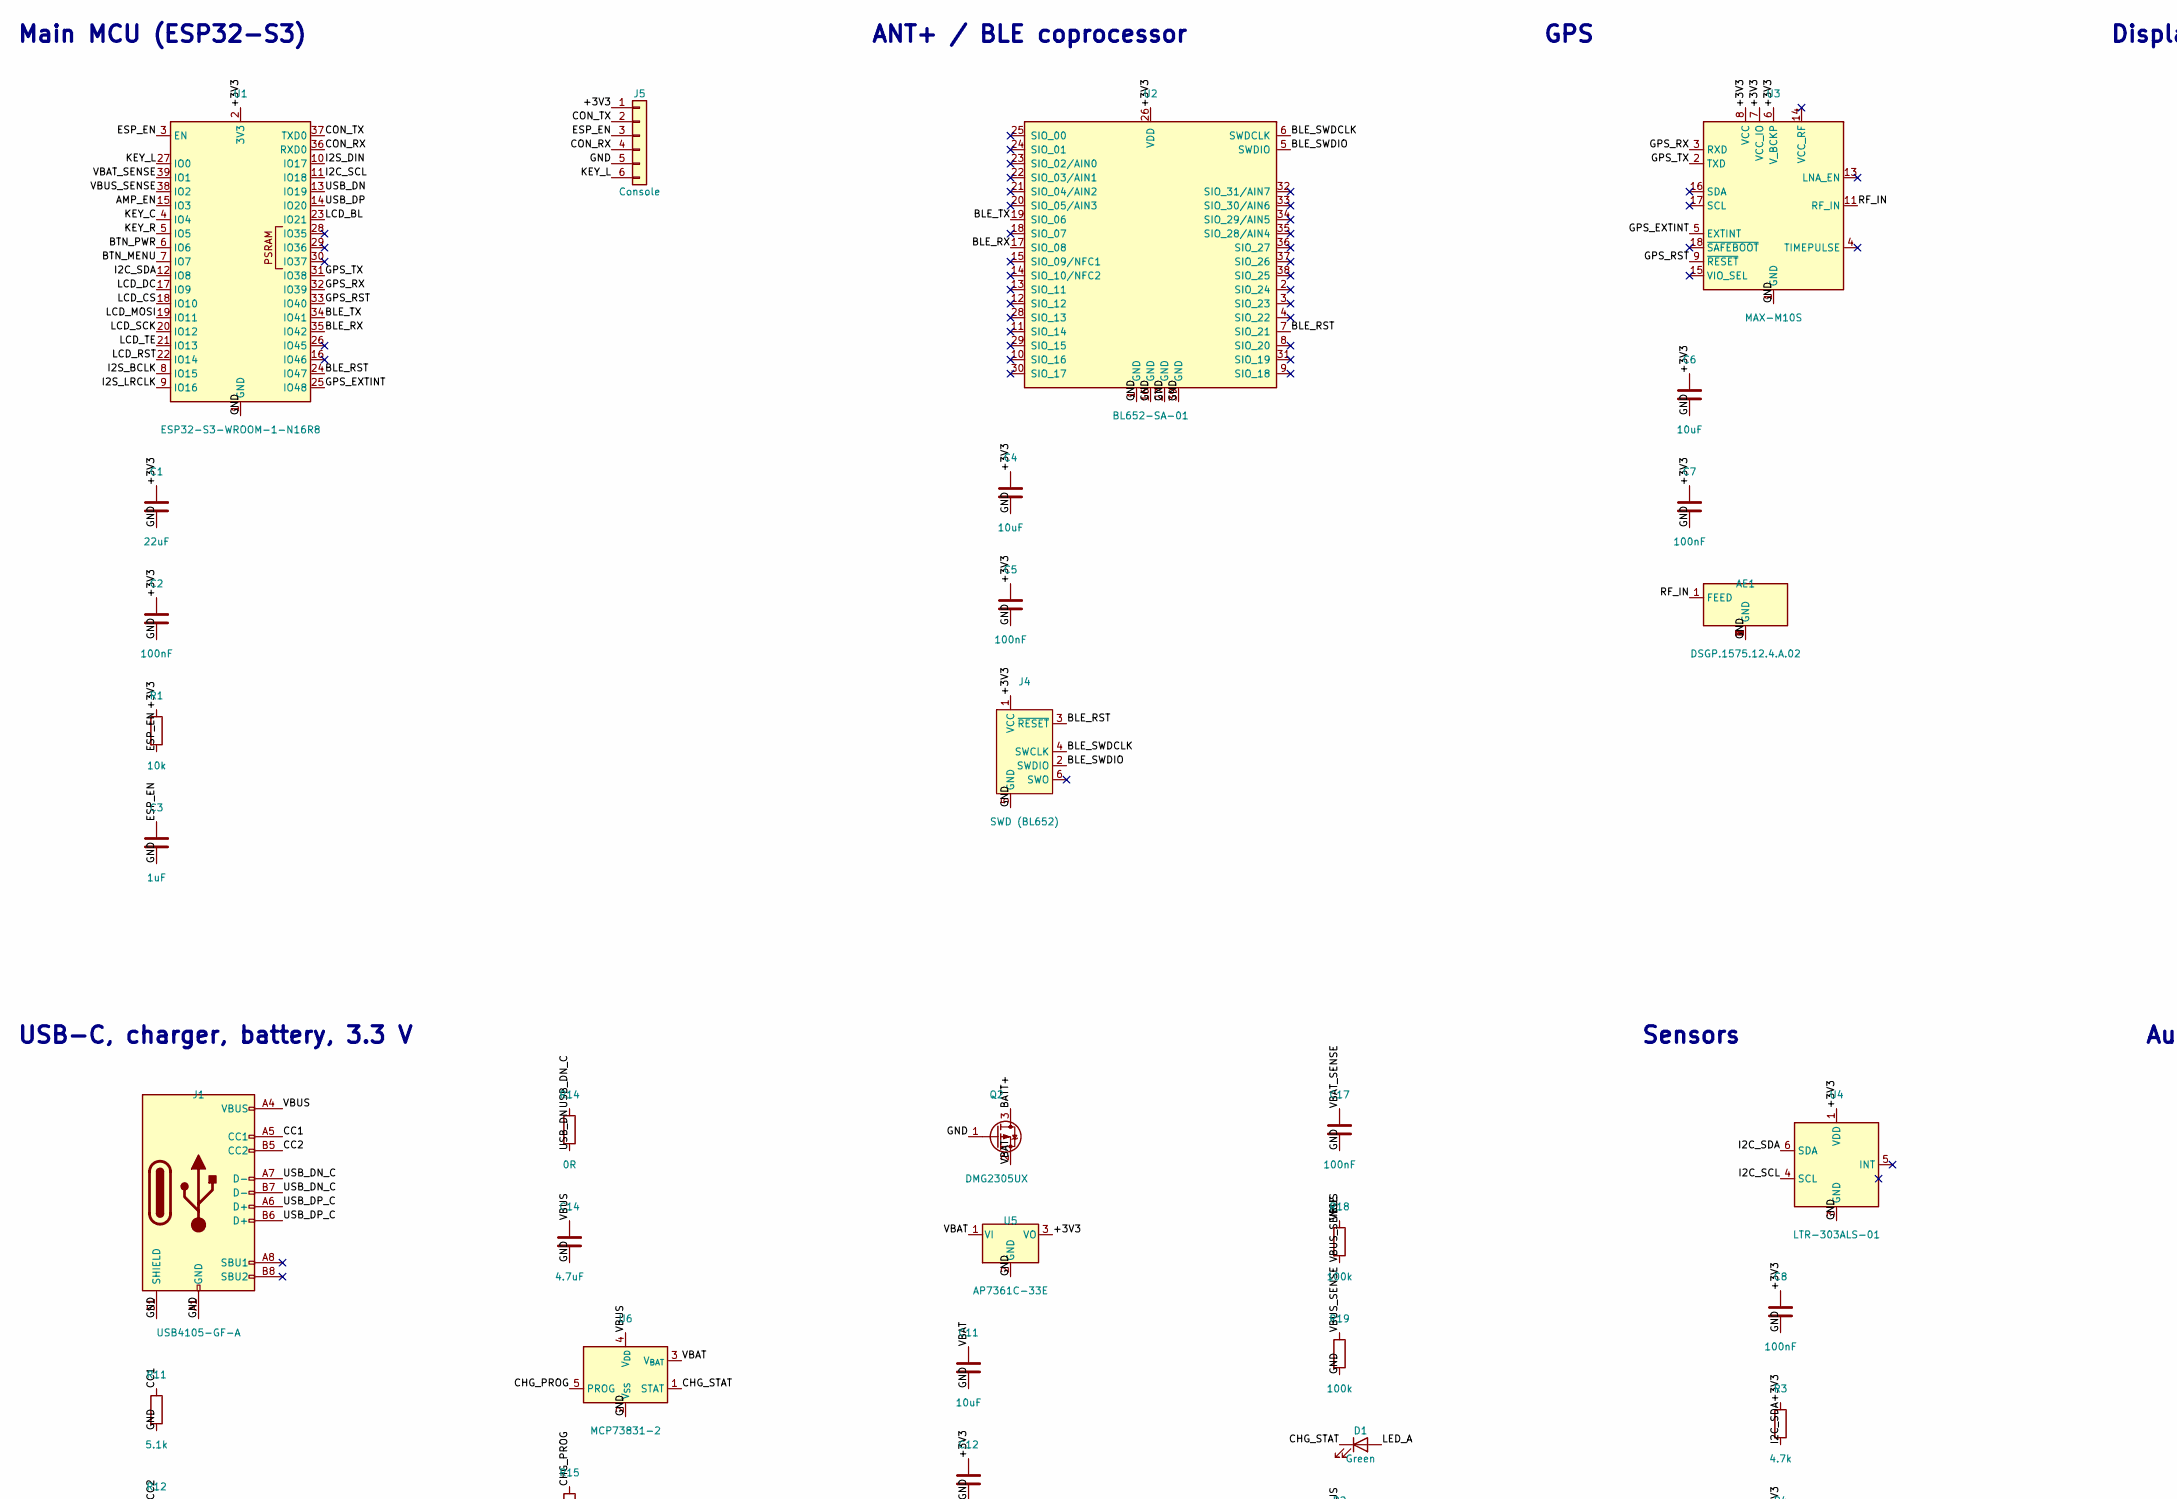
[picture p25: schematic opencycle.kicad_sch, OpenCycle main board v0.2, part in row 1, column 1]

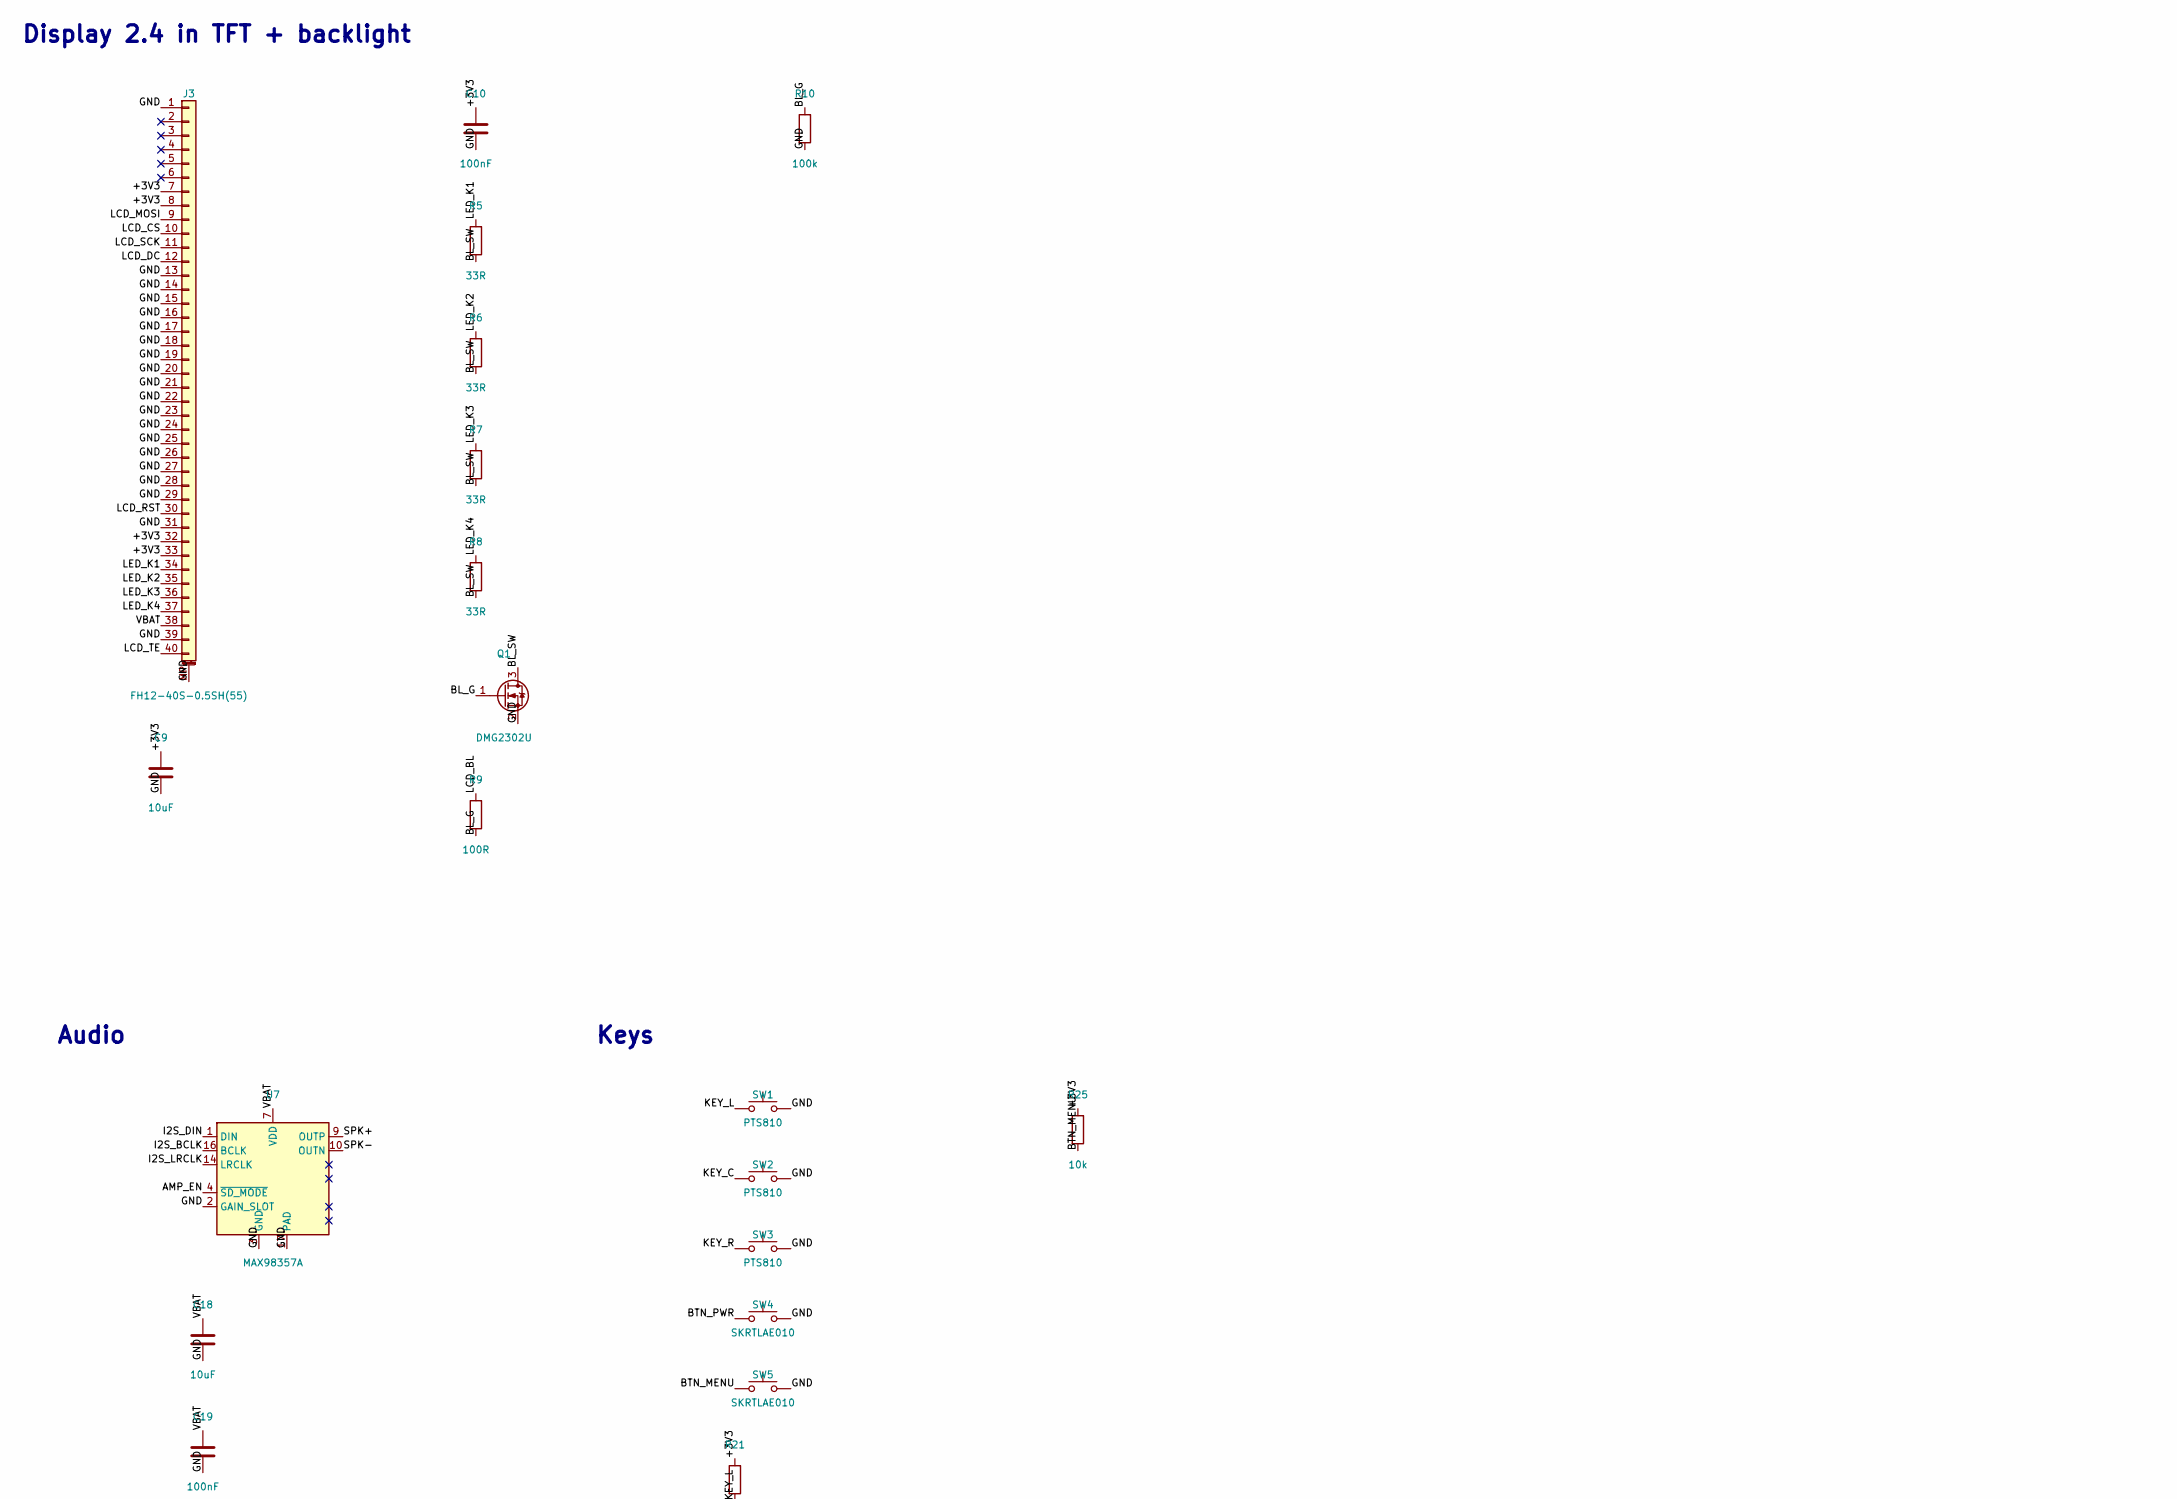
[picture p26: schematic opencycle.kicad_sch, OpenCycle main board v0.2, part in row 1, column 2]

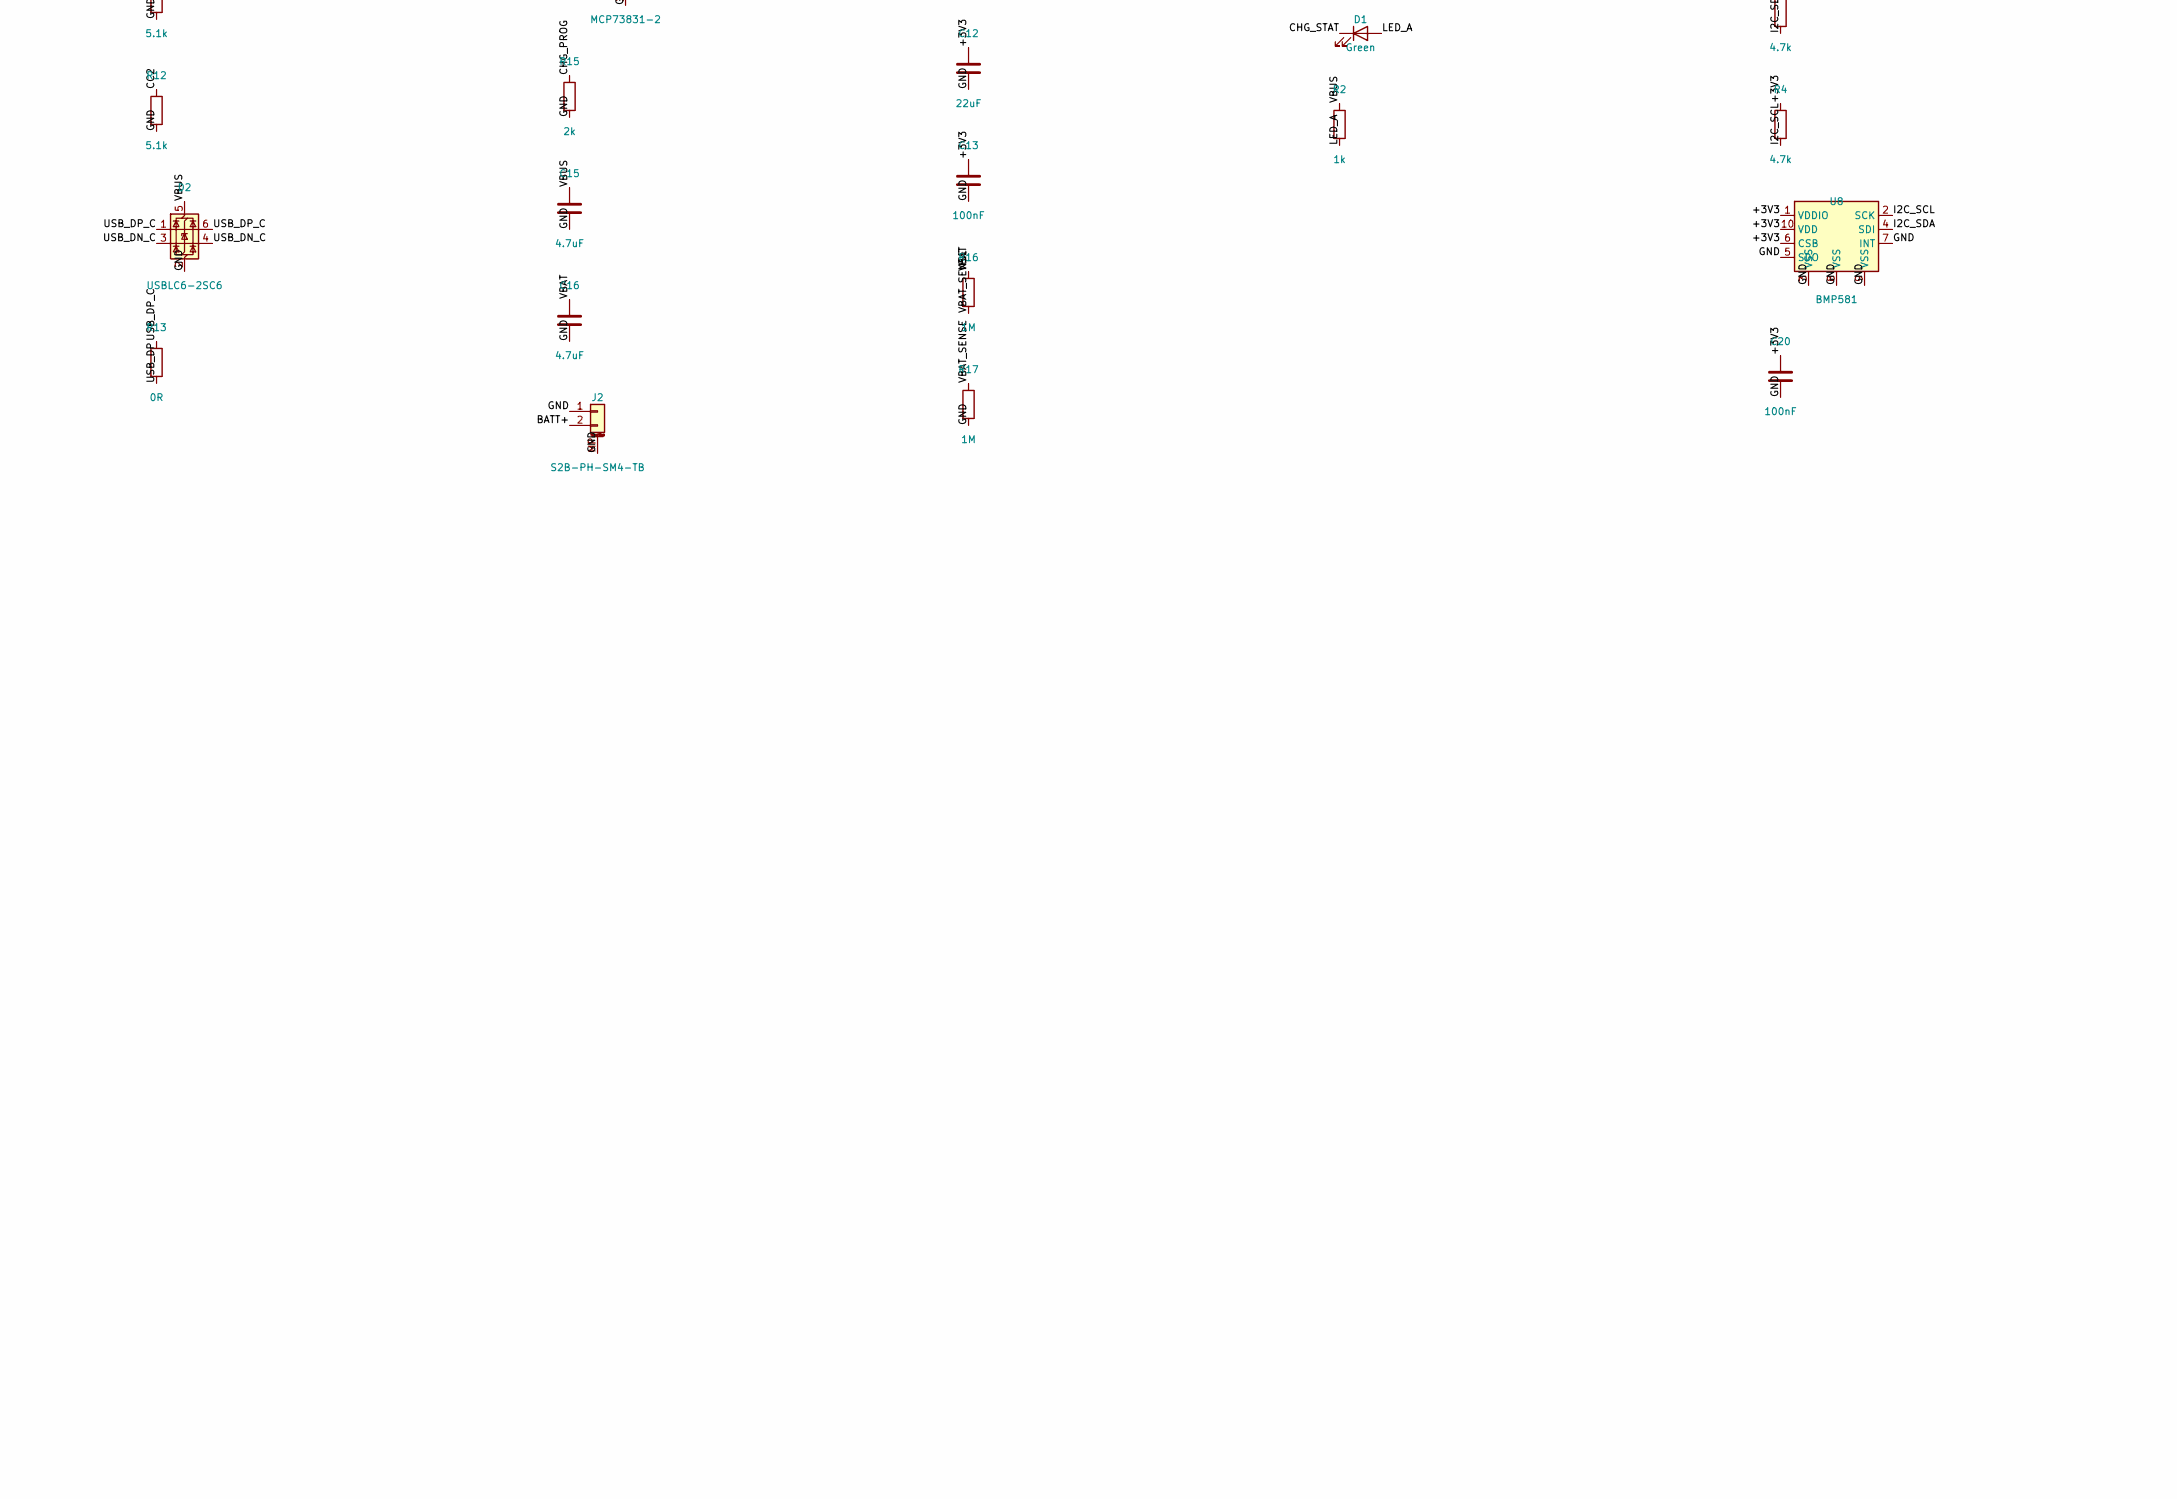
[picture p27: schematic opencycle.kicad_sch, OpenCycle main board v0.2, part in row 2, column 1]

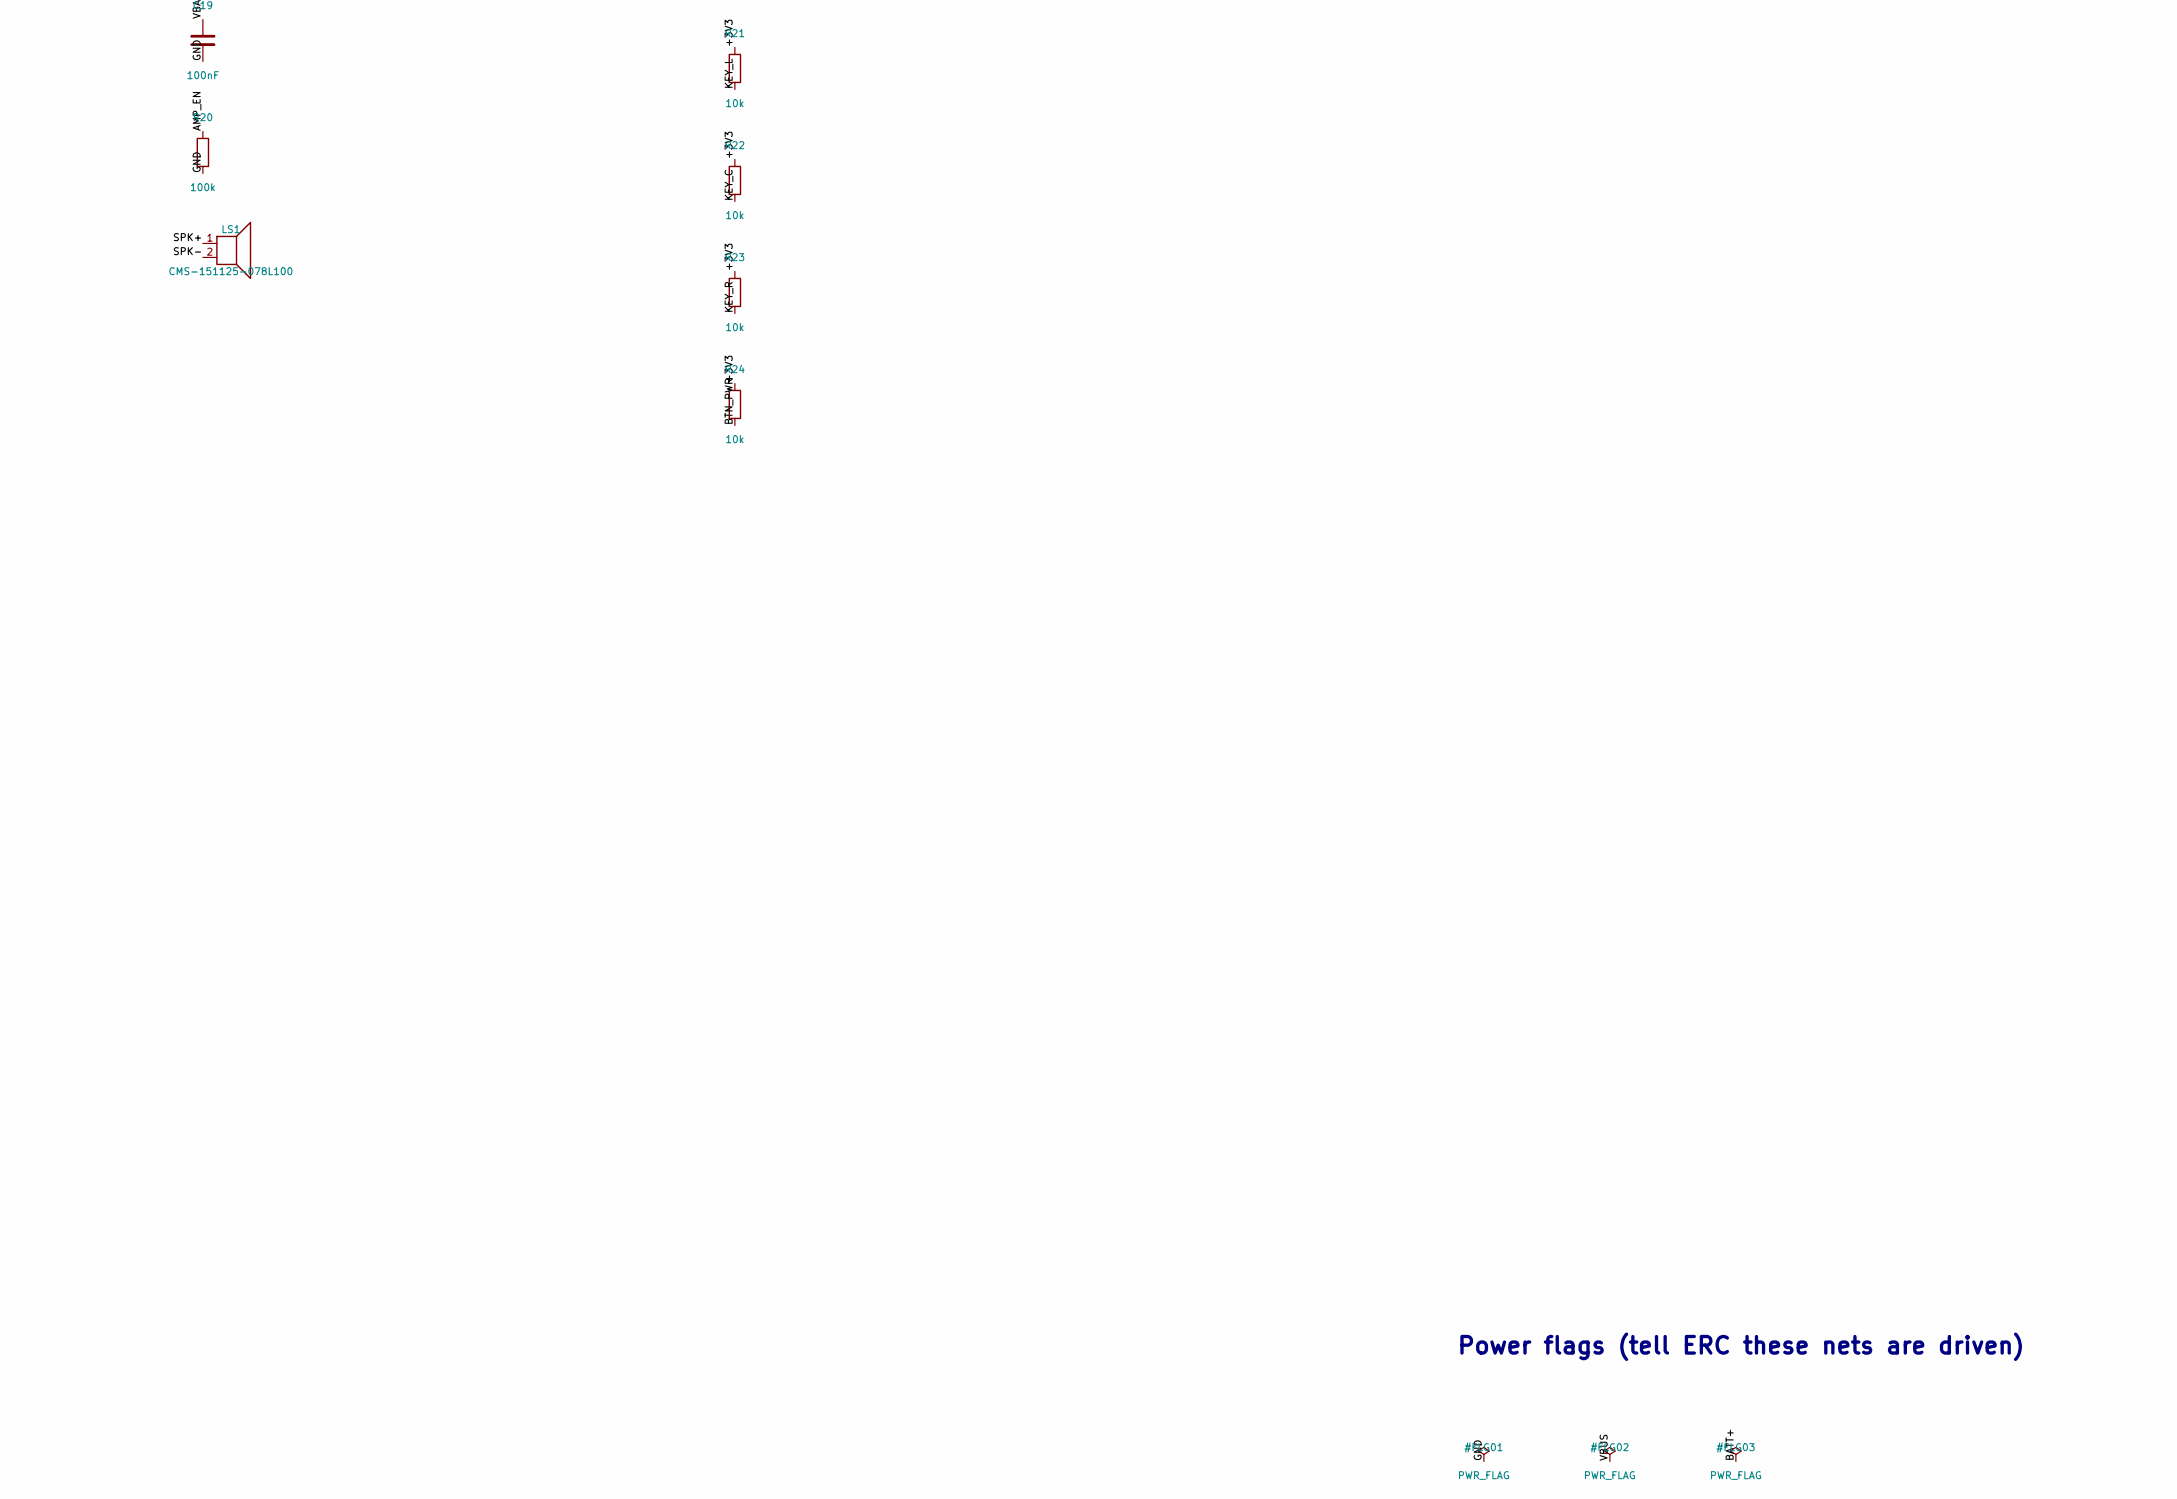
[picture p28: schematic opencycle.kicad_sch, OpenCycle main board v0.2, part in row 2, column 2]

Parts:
AE1: DSGP.1575.12.4.A.02; Taoglas_DSGP.1575.12.4.A.02_12x12mm; MPN DSGP.1575.12.4.A.02
C1, C12: 22uF; C_0805_2012Metric; MPN CL21A226MAQNNNE
C2, C5, C7, C8, C10, C13, C17, C19, C20: 100nF; C_0402_1005Metric; MPN CL05B104KO5NNNC
C3: 1uF; C_0402_1005Metric; MPN CL05A105KO5NNNC
C4, C6, C9, C11, C18: 10uF; C_0603_1608Metric; MPN CL10A106KP8NNNC
C14, C15, C16: 4.7uF; C_0603_1608Metric; MPN CL10A475KO8NNNC
D1: Green; LED_0603_1608Metric; MPN LTST-C191KGKT
D2: USBLC6-2SC6; SOT-23-6; MPN USBLC6-2SC6
J1: USB4105-GF-A; USB_C_Receptacle_GCT_USB4105-xx-A_16P_TopMnt_Horizontal; MPN USB4105-GF-A
J2: S2B-PH-SM4-TB; JST_PH_S2B-PH-SM4-TB_1x02-1MP_P2.00mm_Horizontal; MPN S2B-PH-SM4-TB(LF)(SN)
J3: FH12-40S-0.5SH(55); Hirose_FH12-40S-0.5SH_1x40-1MP_P0.50mm_Horizontal; MPN FH12-40S-0.5SH(55)
J4: SWD (BL652); Tag-Connect_TC2030-IDC-NL_2x03_P1.27mm_Vertical
J5: Console; Tag-Connect_TC2030-IDC-NL_2x03_P1.27mm_Vertical
LS1: CMS-151125-078L100; SpeakerPads_2.6mm; MPN CMS-151125-078L100
Q1: DMG2302U; SOT-23; MPN DMG2302UK-7
Q2: DMG2305UX; SOT-23; MPN DMG2305UX-7
R1, R21, R22, R23, R24, R25: 10k; R_0402_1005Metric; MPN RC0402FR-0710KL
R2: 1k; R_0402_1005Metric; MPN RC0402FR-071KL
R3, R4: 4.7k; R_0402_1005Metric; MPN RC0402FR-074K7L
R5, R6, R7, R8: 33R; R_0603_1608Metric; MPN RC0603FR-0733RL
R9: 100R; R_0402_1005Metric; MPN RC0402FR-07100RL
R10, R18, R19, R20: 100k; R_0402_1005Metric; MPN RC0402FR-07100KL
R11, R12: 5.1k; R_0402_1005Metric; MPN RC0402FR-075K1L
R13, R14: 0R; R_0402_1005Metric; MPN RC0402JR-070RL
R15: 2k; R_0402_1005Metric; MPN RC0402FR-072KL
R16, R17: 1M; R_0402_1005Metric; MPN RC0402FR-071ML
SW1, SW2, SW3: PTS810; SW_SPST_PTS810; MPN PTS810 SJM 250 SMTR LFS
SW4, SW5: SKRTLAE010; SW_Push_1P1T-MP_NO_Horizontal_Alps_SKRTLAE010; MPN SKRTLAE010
U1: ESP32-S3-WROOM-1-N16R8; ESP32-S3-WROOM-1; MPN ESP32-S3-WROOM-1-N16R8
U2: BL652-SA-01; Laird_BL652; MPN BL652-SA-01-T/R
U3: MAX-M10S; ublox_MAX; MPN MAX-M10S-00B
U4: LTR-303ALS-01; Lite-On_LTR-303ALS-01; MPN LTR-303ALS-01
U5: AP7361C-33E; SOT-223-3_TabPin2; MPN AP7361C-33E-13
U6: MCP73831-2; SOT-23-5; MPN MCP73831T-2ACI/OT
U7: MAX98357A; TQFN-16-1EP_3x3mm_P0.5mm_EP1.23x1.23mm; MPN MAX98357AETE+T
U8: BMP581; Bosch_LGA-10_2x2mm_P0.5mm_BMP581; MPN BMP581

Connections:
+3V3: C1.1, C2.1, C4.1, C5.1, C6.1, C7.1, C8.1, C9.1, C10.1, C12.1, C13.1, C20.1, J3.7, J3.8, J3.32, J3.33, J4.1 (VCC), J5.1, R1.1, R3.1, R4.1, R21.1, R22.1, R23.1, R24.1, R25.1, U1.2 (3V3), U2.26 (VDD), U3.6 (V_BCKP), U3.7 (VCC_IO), U3.8 (VCC), U4.1 (VDD), U5.3 (VO), U8.1 (VDDIO), U8.6 (CSB), U8.10 (VDD)
AMP_EN: R20.1, U1.15 (IO3), U7.4 (~SD_MODE)
BATT+: J2.2, Q2.3 (D)
BLE_RST: J4.3 (~RESET), U1.24 (IO47), U2.7 (SIO_21)
BLE_RX: U1.35 (IO42), U2.17 (SIO_08)
BLE_SWDCLK: J4.4 (SWCLK), U2.6 (SWDCLK)
BLE_SWDIO: J4.2 (SWDIO), U2.5 (SWDIO)
BLE_TX: U1.34 (IO41), U2.19 (SIO_06)
BL_G: Q1.1 (G), R9.2, R10.1
BL_SW: Q1.3 (D), R5.2, R6.2, R7.2, R8.2
BTN_MENU: R25.2, SW5.1, U1.7 (IO7)
BTN_PWR: R24.2, SW4.1, U1.6 (IO6)
CC1: J1.A5 (CC1), R11.1
CC2: J1.B5 (CC2), R12.1
CHG_PROG: R15.1, U6.5 (PROG)
CHG_STAT: D1.1 (K), U6.1 (STAT)
CON_RX: J5.4, U1.36 (RXD0)
CON_TX: J5.2, U1.37 (TXD0)
ESP_EN: C3.1, J5.3, R1.2, U1.3 (EN)
GND: AE1.2 (GND), AE1.3 (GND), AE1.4 (GND), AE1.5 (GND), AE1.6 (GND), AE1.7 (GND), AE1.8 (GND), AE1.9 (GND), C1.2, C2.2, C3.2, C4.2, C5.2, C6.2, C7.2, C8.2, C9.2, C10.2, C11.2, C12.2, C13.2, C14.2, C15.2, C16.2, C17.2, C18.2, C19.2, C20.2, D2.2 (GND), J1.A1 (GND), J1.A12 (GND), J1.B1 (GND), J1.B12 (GND), J1.S1 (SHIELD), J2.1, J2.MP (MountPin), J3.1, J3.13, J3.14, J3.15, J3.16, J3.17, J3.18, J3.19, J3.20, J3.21, J3.22, J3.23, J3.24, J3.25, J3.26, J3.27, J3.28, J3.29, J3.31, J3.39, J3.MP (MountPin), J4.5 (GND), J5.5, Q1.2 (S), Q2.1 (G), R10.2, R11.2, R12.2, R15.2, R17.2, R19.2, R20.2, SW1.2, SW2.2, SW3.2, SW4.2, SW4.MP, SW5.2, SW5.MP, U1.1 (GND), U1.40 (GND), U1.41 (GND), U2.1 (GND), U2.16 (GND), U2.27 (GND), U2.39 (GND), U3.1 (GND), U3.10 (GND), U3.12 (GND), U4.3 (GND), U5.2 (GND), U6.2 (V_{SS}), U7.2 (GAIN_SLOT), U7.3 (GND), U7.11 (GND), U7.15 (GND), U7.17 (PAD), U8.3 (VSS), U8.5 (SDO), U8.7 (INT), U8.8 (VSS), U8.9 (VSS); also elsewhere on the board
GPS_EXTINT: U1.25 (IO48), U3.5 (EXTINT)
GPS_RST: U1.33 (IO40), U3.9 (~RESET)
GPS_RX: U1.32 (IO39), U3.3 (RXD)
GPS_TX: U1.31 (IO38), U3.2 (TXD)
I2C_SCL: R4.2, U1.11 (IO18), U4.4 (SCL), U8.2 (SCK)
I2C_SDA: R3.2, U1.12 (IO8), U4.6 (SDA), U8.4 (SDI)
I2S_BCLK: U1.8 (IO15), U7.16 (BCLK)
I2S_DIN: U1.10 (IO17), U7.1 (DIN)
I2S_LRCLK: U1.9 (IO16), U7.14 (LRCLK)
KEY_C: R22.2, SW2.1, U1.4 (IO4)
KEY_L: J5.6, R21.2, SW1.1, U1.27 (IO0)
KEY_R: R23.2, SW3.1, U1.5 (IO5)
LCD_BL: R9.1, U1.23 (IO21)
LCD_CS: J3.10, U1.18 (IO10)
LCD_DC: J3.12, U1.17 (IO9)
LCD_MOSI: J3.9, U1.19 (IO11)
LCD_RST: J3.30, U1.22 (IO14)
LCD_SCK: J3.11, U1.20 (IO12)
LCD_TE: J3.40, U1.21 (IO13)
LED_A: D1.2 (A), R2.2
LED_K1: J3.34, R5.1
LED_K2: J3.35, R6.1
LED_K3: J3.36, R7.1
LED_K4: J3.37, R8.1
RF_IN: AE1.1 (FEED), U3.11 (RF_IN)
SPK+: LS1.1, U7.9 (OUTP)
SPK-: LS1.2, U7.10 (OUTN)
USB_DN: R14.2, U1.13 (IO19)
USB_DN_C: D2.3 (I/O2), D2.4 (I/O2), J1.A7 (D-), J1.B7 (D-), R14.1
USB_DP: R13.2, U1.14 (IO20)
USB_DP_C: D2.1 (I/O1), D2.6 (I/O1), J1.A6 (D+), J1.B6 (D+), R13.1
VBAT: C11.1, C16.1, C18.1, C19.1, J3.38, Q2.2 (S), R16.1, U5.1 (VI), U6.3 (V_{BAT}), U7.7 (VDD), U7.8 (VDD)
VBAT_SENSE: C17.1, R16.2, R17.1, U1.39 (IO1)
VBUS: C14.1, C15.1, D2.5 (VBUS), J1.A4 (VBUS), J1.A9 (VBUS), J1.B4 (VBUS), J1.B9 (VBUS), R2.1, R18.1, U6.4 (V_{DD})
VBUS_SENSE: R18.2, R19.1, U1.38 (IO2)

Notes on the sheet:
Main MCU (ESP32-S3)
ANT+ / BLE coprocessor
GPS
Display 2.4 in TFT + backlight
USB-C, charger, battery, 3.3 V
Sensors
Audio
Keys
Power flags (tell ERC these nets are driven)

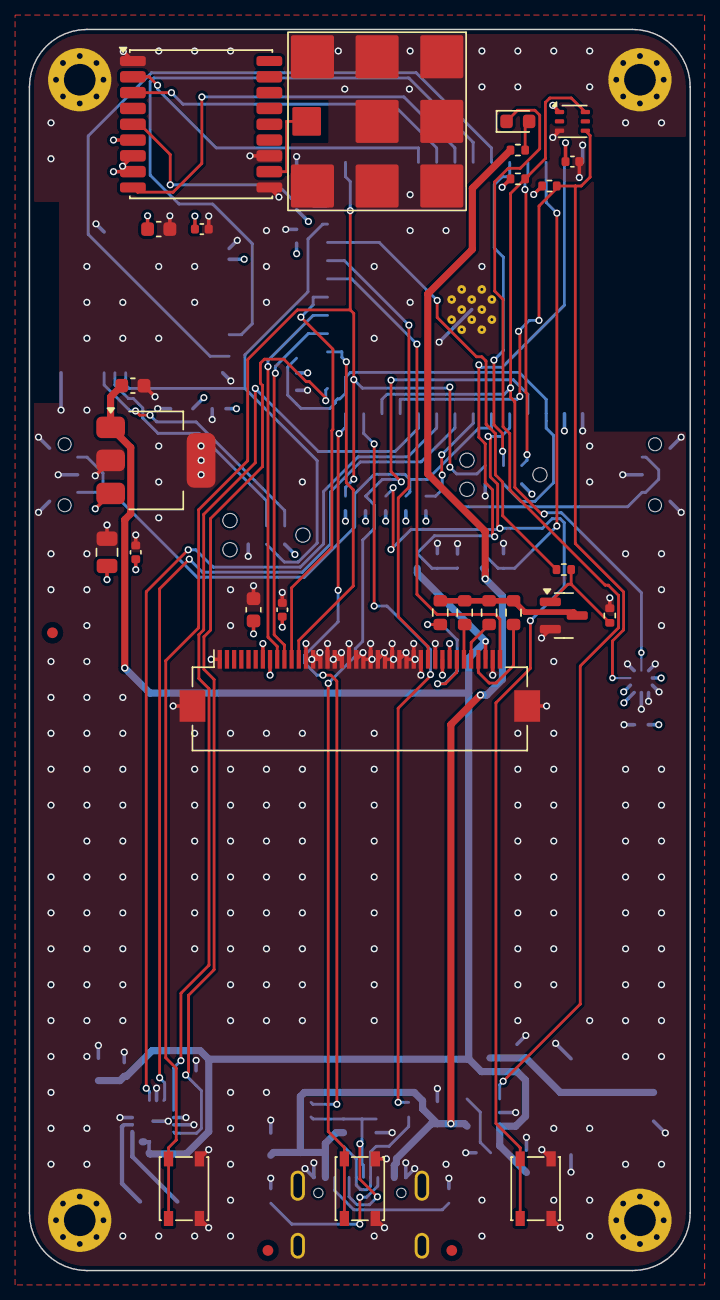
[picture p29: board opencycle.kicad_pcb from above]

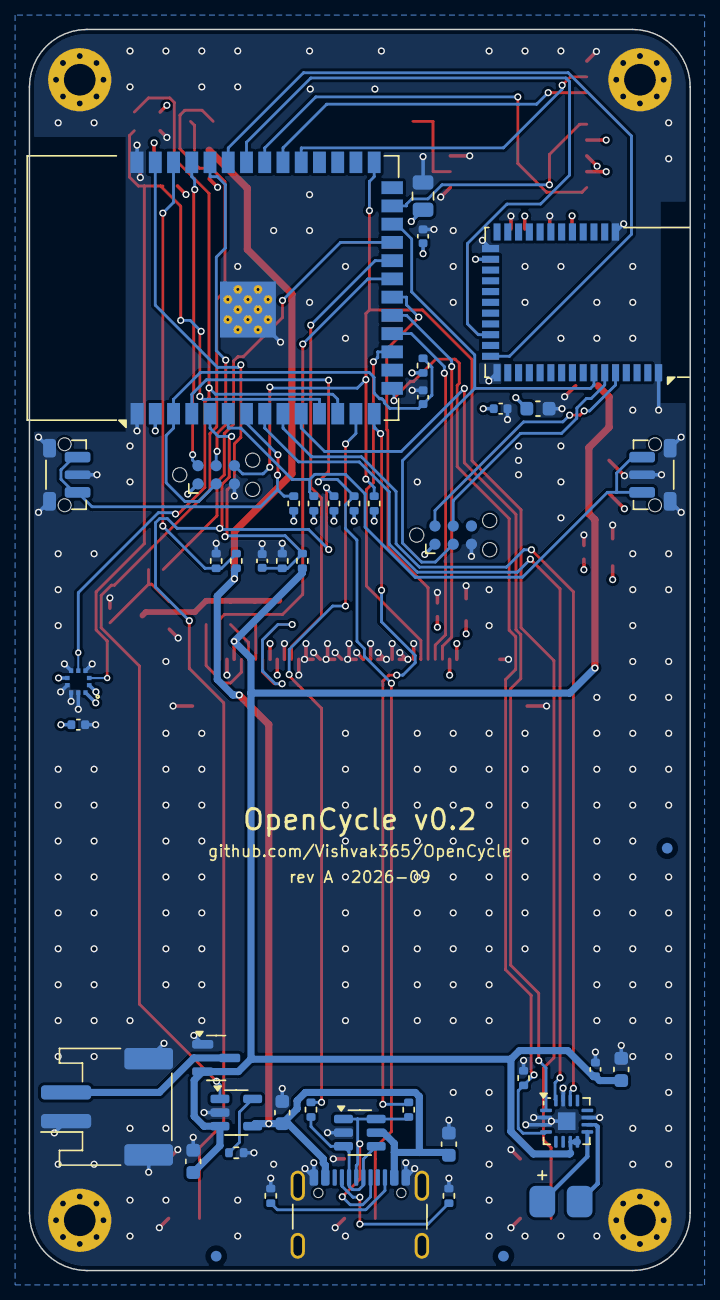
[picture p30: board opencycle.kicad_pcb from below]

Board: 4 copper layers, 46.0 x 86.4 mm, 79 parts (45 on the bottom side), 55 nets.

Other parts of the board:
FID1, FID2, FID3, FID4, FID5, FID6: Fiducial; Fiducial_0.75mm_Mask1.5mm
H1, H2, H3, H4: MountingHole_2.2mm_M2_Pad_Via

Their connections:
GND: H1.1, H2.1, H3.1, H4.1; also elsewhere on the board

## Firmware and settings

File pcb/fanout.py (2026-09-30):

"""Fan out every SMD pad on the plane nets (GND, +3V3) to its inner plane with a short stub and a via.

Freerouting does not reliably drop vias from small SMD pads to planes, so this runs before autorouting.
For each pad it tries via positions around the pad (8 directions, growing distance) and keeps the first
one with clearance to every other-net pad, via and track, outside the via keep-outs. Stubs and vias are
locked so the autorouter leaves them alone.

python fanout.py in.kicad_pcb out.kicad_pcb
"""
import math
import sys
from pathlib import Path

import pcbnew

sys.path.insert(0, str(Path(__file__).parent))
import design as D  # noqa: E402

TM, MM = pcbnew.ToMM, pcbnew.FromMM
VIA_D, VIA_DRILL, STUB = 0.5, 0.3, 0.25
CLR = 0.2                     # a little above the 0.15 mm rule
SKIP_REFS = {"AE1"}           # patch ground pads join the F.Cu pour; stitching vias are added under the patch instead


def rect(item, grow=0.0):
    bb = item.GetBoundingBox()
    return (TM(bb.GetX()) - grow, TM(bb.GetY()) - grow, TM(bb.GetRight()) + grow, TM(bb.GetBottom()) + grow)


def pt_in(r, x, y):
    return r[0] <= x <= r[2] and r[1] <= y <= r[3]


def seg_hits(r, a, b, steps=12):
    return any(pt_in(r, a[0] + (b[0] - a[0]) * k / steps, a[1] + (b[1] - a[1]) * k / steps) for k in range(steps + 1))


def rect_hits_circle(r, x, y, rad):
    cx = min(max(x, r[0]), r[2]); cy = min(max(y, r[1]), r[3])
    return math.hypot(cx - x, cy - y) < rad


def main(src, dst):
    b = pcbnew.LoadBoard(src)
    x0, y0 = D.BOARD["x0"], D.BOARD["y0"]
    x1, y1 = x0 + D.BOARD["w"], y0 + D.BOARD["h"]
    pads = [p for f in b.GetFootprints() for p in f.Pads()]
    no_via = [k["rect"] for k in D.KEEPOUTS] + [k["rect"] for k in D.NO_TRACKS_B]
    no_track_f = [k["rect"] for k in D.NO_TRACKS_F]
    no_track_b = [k["rect"] for k in D.NO_TRACKS_B]
    holes = [(hx, hy) for hx, hy in D.HOLES]
    vias = [(TM(t.GetPosition().x), TM(t.GetPosition().y), t.GetNetname()) for t in b.GetTracks() if t.GetClass() == "PCB_VIA"]
    tracks = [(TM(t.GetStart().x), TM(t.GetStart().y), TM(t.GetEnd().x), TM(t.GetEnd().y), TM(t.GetWidth()), t.GetNetname(),
               t.GetLayer()) for t in b.GetTracks() if t.GetClass() != "PCB_VIA"]
    added = failed = 0
    fails = []
    # escapes for boxed-in signal pads: straight out, away from the part centre, then a via
    for ref, num, sw, direction in D.ESCAPES:
        f = b.FindFootprintByReference(ref)
        p = next(q for q in f.Pads() if q.GetNumber() == num)
        c, fc = p.GetPosition(), f.GetPosition()
        dx, dy = TM(c.x - fc.x), TM(c.y - fc.y)
        if direction:
            ux, uy = direction
        elif abs(dx) >= abs(dy):
            ux, uy = (1 if dx > 0 else -1), 0
        else:
            ux, uy = 0, (1 if dy > 0 else -1)
        L = 1.25
        vx, vy = TM(c.x) + ux * L, TM(c.y) + uy * L
        layer = pcbnew.F_Cu if p.IsOnLayer(pcbnew.F_Cu) else pcbnew.B_Cu
        t = pcbnew.PCB_TRACK(b)
        t.SetStart(c); t.SetEnd(pcbnew.VECTOR2I(MM(vx), MM(vy))); t.SetWidth(MM(sw)); t.SetLayer(layer)
        t.SetNet(p.GetNet()); t.SetLocked(True); b.Add(t)
        v = pcbnew.PCB_VIA(b)
        v.SetPosition(pcbnew.VECTOR2I(MM(vx), MM(vy))); v.SetWidth(MM(0.45)); v.SetDrill(MM(0.25))
        v.SetLayerPair(pcbnew.F_Cu, pcbnew.B_Cu); v.SetNet(p.GetNet()); v.SetLocked(True); b.Add(v)
        vias.append((vx, vy, p.GetNetname()))
        tracks.append((TM(c.x), TM(c.y), vx, vy, sw, p.GetNetname(), layer))
    for f in b.GetFootprints():
        if f.GetReference() in SKIP_REFS:
            continue
        for p in f.Pads():
            net = p.GetNetname()
            if net not in D.PLANE_NETS or p.GetAttribute() not in (pcbnew.PAD_ATTRIB_SMD, pcbnew.PAD_ATTRIB_CONN):
                continue
            pr0 = rect(p)
            if f.GetReference() == "U5" and (pr0[2] - pr0[0]) * (pr0[3] - pr0[1]) > 6.0:
                continue          # regulator tab: gets in-pad thermal vias below
            layer = pcbnew.F_Cu if p.IsOnLayer(pcbnew.F_Cu) else pcbnew.B_Cu
            cx, cy = TM(p.GetPosition().x), TM(p.GetPosition().y)
            pr = rect(p)
            hw, hh = (pr[2] - pr[0]) / 2, (pr[3] - pr[1]) / 2
            fc = f.GetPosition()
            away = math.atan2(cy - TM(fc.y), cx - TM(fc.x))
            dirs = sorted(range(8), key=lambda k: abs(math.remainder(k * math.pi / 4 - away, 2 * math.pi)))
            best = None
            for extra in (0.45, 0.6, 0.8, 1.0, 1.3, 1.6, 2.0):
                for k in dirs:
                    a = k * math.pi / 4
                    dx, dy = math.cos(a), math.sin(a)
                    # distance from the pad centre to its edge in this direction, plus clearance for the via
                    t_edge = min(hw / abs(dx) if abs(dx) > 1e-6 else 1e9, hh / abs(dy) if abs(dy) > 1e-6 else 1e9)
                    vx, vy = cx + dx * (t_edge + extra), cy + dy * (t_edge + extra)
                    if not (x0 + 0.6 <= vx <= x1 - 0.6 and y0 + 0.6 <= vy <= y1 - 0.6):
                        continue
                    if any(pt_in(r, vx, vy) or rect_hits_circle(r, vx, vy, VIA_D / 2) for r in no_via):
                        continue
                    if any(math.hypot(vx - hx, vy - hy) < 2.6 for hx, hy in holes):
                        continue
                    ok = True
                    for q in pads:
                        if q.GetNetname() == net and q.GetParent().GetReference() == f.GetReference():
                            continue
                        r = rect(q)
                        if rect_hits_circle(r, vx, vy, VIA_D / 2 + CLR) and q.GetNetname() != net:
                            ok = False; break
                        if q.GetNetname() != net and q.IsOnLayer(layer) and seg_hits(rect(q, STUB / 2 + CLR), (cx, cy), (vx, vy)) \
                                and q is not p:
                            ok = False; break
                        if q.GetNetname() == net and rect_hits_circle(r, vx, vy, VIA_D / 2 + 0.05):
                            ok = False; break        # no via-in-pad
                    if not ok:
                        continue
                    if any(math.hypot(vx - ux, vy - uy) < VIA_D + CLR for ux, uy, _ in vias):
                        continue
                    if any(_seg_dist((vx, vy), (tx1, ty1), (tx2, ty2)) < VIA_D / 2 + tw / 2 + CLR
                           for tx1, ty1, tx2, ty2, tw, tn, tl in tracks if tn != net):
                        continue
                    stub_rects = no_track_f if layer == pcbnew.F_Cu else no_track_b
                    if any(seg_hits(r, (cx, cy), (vx, vy)) for r in stub_rects):
                        continue
                    best = (vx, vy)
                    break
                if best:
                    break
            if not best:
                failed += 1; fails.append(f"{f.GetReference()}.{p.GetNumber()} {net}")
                continue
            vx, vy = best
            t = pcbnew.PCB_TRACK(b)
            t.SetStart(p.GetPosition()); t.SetEnd(pcbnew.VECTOR2I(MM(vx), MM(vy)))
            t.SetWidth(MM(STUB)); t.SetLayer(layer); t.SetNet(p.GetNet()); t.SetLocked(True); b.Add(t)
            v = pcbnew.PCB_VIA(b)
            v.SetPosition(pcbnew.VECTOR2I(MM(vx), MM(vy))); v.SetWidth(MM(VIA_D)); v.SetDrill(MM(VIA_DRILL))
            v.SetLayerPair(pcbnew.F_Cu, pcbnew.B_Cu); v.SetViaType(pcbnew.VIATYPE_THROUGH)
            v.SetNet(p.GetNet()); v.SetLocked(True); b.Add(v)
            vias.append((vx, vy, net))
            tracks.append((cx, cy, vx, vy, STUB, net, layer))
            added += 1
    # SOT-223 regulator tab: three thermal vias inside the tab pad
    for f in b.GetFootprints():
        if f.GetReference() != "U5":
            continue
        tab = max(f.Pads(), key=lambda q: (rect(q)[2] - rect(q)[0]) * (rect(q)[3] - rect(q)[1]))
        c = tab.GetPosition()
        for dx, dy in ((0, -1.0), (0, 0), (0, 1.0)):
            v = pcbnew.PCB_VIA(b)
            v.SetPosition(pcbnew.VECTOR2I(c.x + MM(dx), c.y + MM(dy))); v.SetWidth(MM(VIA_D)); v.SetDrill(MM(VIA_DRILL))
            v.SetLayerPair(pcbnew.F_Cu, pcbnew.B_Cu); v.SetNet(tab.GetNet()); v.SetLocked(True); b.Add(v)
    # stitching vias under the patch ground (between its ground pads), tying the F.Cu pour to the In1 plane
    ae = b.FindFootprintByReference("AE1")
    gnd = b.FindNet("GND")
    ac = ae.GetPosition()
    for dx, dy in ((-2.25, -2.25), (2.25, -2.25), (-2.25, 2.25), (2.25, 2.25)):
        vx, vy = TM(ac.x) + dx, TM(ac.y) + dy
        # through-via: must clear every non-GND pad on BOTH sides (the ESP32 sits behind the patch)
        if any(q.GetNetname() != "GND" and rect_hits_circle(rect(q), vx, vy, VIA_D / 2 + CLR) for q in pads):
            continue
        v = pcbnew.PCB_VIA(b)
        v.SetPosition(pcbnew.VECTOR2I(ac.x + MM(dx), ac.y + MM(dy))); v.SetWidth(MM(VIA_D)); v.SetDrill(MM(VIA_DRILL))
        v.SetLayerPair(pcbnew.F_Cu, pcbnew.B_Cu); v.SetNet(gnd); v.SetLocked(True); b.Add(v)
    b.Save(dst)
    print(f"fan-out: {added} vias, {failed} pads without a spot")
    for s in fails:
        print("  no spot:", s)


def _seg_dist(p, a, c):
    ax, ay = a; cx, cy = c; px, py = p
    L2 = (cx - ax) ** 2 + (cy - ay) ** 2
    t = 0 if L2 == 0 else max(0, min(1, ((px - ax) * (cx - ax) + (py - ay) * (cy - ay)) / L2))
    return math.hypot(px - (ax + t * (cx - ax)), py - (ay + t * (cy - ay)))


if __name__ == "__main__":
    main(sys.argv[1], sys.argv[2])

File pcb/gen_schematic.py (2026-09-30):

"""Generate the KiCad schematic (opencycle.kicad_sch) from design.py.

The schematic is "label-connected": every symbol from design.py is placed in a functional block and
each connected pin gets a net label with the same net name as on the board; unconnected pins get a
no-connect flag. It is generated from the same table as the PCB, so it cannot drift from it, and
`check_netlist.py` proves that by comparing KiCad's netlist export with the board.

python gen_schematic.py        -> opencycle.kicad_sch (+ lib tables for opening in KiCad)
"""
import copy
import uuid
from pathlib import Path

from kiutils.symbol import SymbolLib

import design as D
from symlib import lib_path

HERE = Path(__file__).parent
G = 2.54

# functional blocks, drawn left-to-right, top-to-bottom on an A1 sheet
BLOCKS = [
    ("Main MCU (ESP32-S3)", ["U1", "C1", "C2", "R1", "C3", "J5"]),
    ("ANT+ / BLE coprocessor", ["U2", "C4", "C5", "J4"]),
    ("GPS", ["U3", "C6", "C7", "AE1"]),
    ("Display 2.4 in TFT + backlight", ["J3", "C9", "C10", "R5", "R6", "R7", "R8", "Q1", "R9", "R10"]),
    ("USB-C, charger, battery, 3.3 V", ["J1", "R11", "R12", "D2", "R13", "R14", "C14", "U6", "R15", "C15", "C16",
                                        "J2", "Q2", "U5", "C11", "C12", "C13", "R16", "R17", "C17", "R18", "R19",
                                        "D1", "R2"]),
    ("Sensors", ["U4", "C8", "R3", "R4", "U8", "C20"]),
    ("Audio", ["U7", "C18", "C19", "R20", "LS1"]),
    ("Keys", ["SW1", "SW2", "SW3", "SW4", "SW5", "R21", "R22", "R23", "R24", "R25"]),
]
POWER_FLAG_NETS = ["GND", "VBUS", "BATT+"]      # +3V3 and VBAT are driven by the LDO / charger outputs


def uid():
    return str(uuid.uuid4())


def snap(v):
    return round(v / 1.27) * 1.27


class Sym:
    def __init__(self, libname, name):
        L = SymbolLib.from_file(lib_path(libname))
        s = next(x for x in L.symbols if x.entryName == name)
        base = next(x for x in L.symbols if x.entryName == s.extends) if s.extends else s
        flat = copy.deepcopy(base)
        if s is not base:        # derived symbol: keep the derived properties
            flat.properties = copy.deepcopy(s.properties)
        flat.libraryNickname = libname
        flat.entryName = name
        flat.extends = None
        for u in flat.units:
            u.entryName = name
            u.libraryNickname = None
        self.flat = flat
        self.lib_id = f"{libname}:{name}"
        self.pins = []
        for u in flat.units:
            for p in u.pins:
                self.pins.append((p.number, p.name, p.position.X, p.position.Y, p.position.angle or 0, p.length))
        xs = [p[2] for p in self.pins] or [0]
        ys = [p[3] for p in self.pins] or [0]
        self.bbox = (min(xs), min(ys), max(xs), max(ys))


def label_dir(angle):
    # pin angle = direction from the connection point into the body; the label goes the other way
    return {0: (180, "right"), 180: (0, "left"), 90: (270, "left"), 270: (90, "left")}[int(angle) % 360]


def main():
    global ROOT
    parts = {p["ref"]: p for p in D.PARTS}
    placed = [r for _, refs in BLOCKS for r in refs]
    missing = [r for r in parts if r not in placed and not r.startswith("FID")]
    assert not missing, f"not placed in a schematic block: {missing}"
    syms, out, texts = {}, [], []
    ROOT = uid()
    page_w, page_h = 841.0, 594.0             # A1 landscape
    LBL = 26.0                                 # room for net labels either side of a symbol
    MAX_H = 150.0                              # column height before wrapping within a block
    bx, by, row_h = 25.4, 35.0, 0.0
    for title, refs in BLOCKS:
        items = []
        for r in refs:
            p = parts[r]
            key = f'{p["slib"]}:{p["sym"]}'
            if key not in syms:
                syms[key] = Sym(p["slib"], p["sym"])
            items.append((r, syms[key]))
        # lay the block out in columns (relative coordinates), then place it
        cols, col, h = [], [], 0.0
        for r, s_ in items:
            x0, y0, x1, y1 = s_.bbox
            sh = (y1 - y0) + 12.7
            if col and h + sh > MAX_H:
                cols.append(col); col, h = [], 0.0
            col.append((r, s_, h)); h += sh
        cols.append(col)
        widths = [max((s_.bbox[2] - s_.bbox[0]) + 2 * LBL for _, s_, _ in c) for c in cols]
        heights = [max(yy + (s_.bbox[3] - s_.bbox[1]) + 12.7 for _, s_, yy in c) for c in cols]
        bw, bh = sum(widths), max(heights) + 12
        if bx + bw > page_w - 20 and bx > 25.4:
            bx, by, row_h = 25.4, by + row_h + 20, 0.0
        texts.append((title, bx, by))
        cx = bx
        for c, w in zip(cols, widths):
            for r, s_, yy in c:
                x0, y0, x1, y1 = s_.bbox
                sx = snap(cx + LBL - x0)
                sy = snap(by + 12 + yy + y1)          # symbol y axis points up
                place(out, parts[r], s_, sx, sy, ROOT)
            cx += w
        bx += bw + 20
        row_h = max(row_h, bh)
    # power flags
    pf = Sym("power", "PWR_FLAG")
    syms["power:PWR_FLAG"] = pf
    fx, fy = page_w - 170, page_h - 45
    texts.append(("Power flags (tell ERC these nets are driven)", fx - 5, fy - 20))
    for i, net in enumerate(POWER_FLAG_NETS):
        x, y = snap(fx + i * 22.86), snap(fy)
        out.append(sym_inst(pf, f"#FLG{i + 1:02d}", "PWR_FLAG", "", x, y, ROOT, in_bom=False, on_board=False))
        out.append(label(net, x, y, 270, "left"))
    body = [f'(kicad_sch (version 20230121) (generator eeschema)\n  (uuid {ROOT})\n  (paper "A1")\n',
            '  (title_block (title "OpenCycle main board v0.2") (date "2026-09-30") (rev "A")\n'
            '    (comment 1 "Generated from pcb/design.py by gen_schematic.py - do not edit by hand")\n'
            '    (comment 2 "Nets connect by label name; every net name matches the PCB"))\n',
            "  (lib_symbols\n"]
    for s_ in syms.values():
        body.append(s_.flat.to_sexpr(indent=4) + "\n")
    body.append("  )\n")
    for t, x, y in texts:
        body.append(f'  (text "{t}" (at {snap(x)} {snap(y)} 0)\n    (effects (font (size 3 3) (thickness 0.6) bold) (justify left bottom))\n    (uuid {uid()})\n  )\n')
    body.extend(out)
    body.append('  (sheet_instances (path "/" (page "1")))\n)\n')
    (HERE / "opencycle.kicad_sch").write_text("".join(body))
    print("wrote opencycle.kicad_sch:", len(parts), "parts")


def label(net, x, y, ang, just):
    return (f'  (label "{net}" (at {x:.2f} {y:.2f} {ang}) (fields_autoplaced)\n'
            f'    (effects (font (size 1.27 1.27)) (justify {just} bottom))\n    (uuid {uid()})\n  )\n')
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

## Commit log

2026-09-30 Initial OpenCycle concept: enclosure CAD, concept PCB, 3D viewer, screen designs, docs
    - cad/: parametric CadQuery enclosure (standard/aero/rugged), fit checks
    - pcb/: design.py-driven KiCad 7 board, pin assignment, custom router,
    zone fill + DRC tooling (concept only: not routed to 100%, not for fab)
    - viewer/: three.js product viewer, PCB net explorer, 1-bit screen UI renderer
    - docs/ + AGENTS.md: setup, hardware, PCB, CAD, UI, firmware plan, decisions
    [opencycle.kicad_pcb]
2026-09-30 Add sourced BOM for the colour-display build (Mouser + Digi-Key)
2026-09-30 BOM: add display mechanical data from Newhaven drawing Rev 2B; drop accelerometer
2026-09-30 docs: add sourcing folder (BOMs, part specs, displays, stock issues, power budget, market reference)
2026-09-30 docs: record front-button + patch-antenna layout decision
2026-09-30 cad: v0.2 front layout - 52x92.4x17 body, 2.4in TFT, three front soft keys, 12 mm patch band, Adafruit 1200 mAh cell; fit check OK
2026-09-30 viewer: v0.2 product view - colour screen on the 3D model, front soft keys, top band print, folded FFC; screens panel at 240x320
2026-09-30 viewer/ui: Meridian design language for the 240x320 colour screen
    Rewrite screens_color.js as a small design system (palette in RGB565-exact
    values, type scale, spacing, components: status bar, soft-key bar, notched
    field, Meridian rail, bezel, halo, chips). Same exported API. Screens: ride,
    hr, climb, map, workout, status, lap overlay, summary, menu, boot.
2026-09-30 pcb: v0.2 colour board definition and placement (ESP32-S3 + BL652 + MAX-M10S + 2.4in TFT); placement checks OK
    Local symbols/footprints for BMP581 (Bosch DS004-13 land pattern) and the Taoglas 12 mm patch;
    height zones from the enclosure stack, antenna keep-outs, locked RF feed trace.
2026-09-30 cad: match the real v0.2 board - switch geometry, patch/GNSS positions, battery pocket, USB-C counterbore, sensor/LED windows; add board_fit.py (real footprints vs case: OK)
2026-09-30 pcb: Freerouting round trip (DSN classes, headless SES import), placement/RF feed fixes; tools: PCB time-lapse renderer + sample
    [autoroute.py, design.py, finish.py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]
2026-09-30 pcb: text-generated local footprints (fixes pads stacked at the origin), work-in-progress routed board + DRC report
    [opencycle.kicad_pcb]
2026-09-30 viewer/ui: Lucent design language - frosted glass over a deep backdrop, Inter fonts, re-rendered screens
    Replaces the Meridian look (chamfers, neon, Chakra Petch/Saira) with calm
    translucent glass panels built only from LVGL-cheap primitives: pre-rendered
    dithered backdrop, recoloured A8 zone light, gradient fill + 1 px edge + top
    highlight. Same API, screen ids and soft-key mapping. Frames are quantised to
    RGB565. Inter/Inter Display (OFL) with tabular figures frozen in by
    docs/ui/make_fonts.py. docs/UI.md rewritten with palette, type, glass recipe,
    per-screen layouts and risks.
2026-09-30 pcb: plane fan-out, dangling clean-up, GND stitching + island vias, custom DRC rules; board down to 2 unrouted (BMP581 I2C)
    [fanned.kicad_pcb, opencycle.kicad_pcb]
2026-09-30 pcb: v0.2 board fully routed - DRC 0 errors, 0 unconnected (5 intentional warnings); refs on fab layer, lib tables; cad: rotated key switches, board_fit OK on the routed board
    [fanned.kicad_pcb, opencycle.kicad_pcb]
2026-09-30 pcb: generated schematic (A1, functional blocks) - netlist matches the board (55 nets / 282 pins), ERC 0 errors (KiCad 9 CLI); schematic PDF
    [fanned.kicad_pcb, opencycle.kicad_sch]
2026-09-30 pcb: fab package - Gerbers/drill zip, JLCPCB BOM + CPL, Mouser/Digi-Key BOM with prices and links, assembly drawings; sourcing.py
    [bom_distributors.csv, bom_jlcpcb.csv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]
2026-09-30 print: print-ready STLs (oriented), STEP files and lens outline DXF; tools/export_print.py
    [back_shell_aero.step, back_shell_aero.stl, back_shell_standard.step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]
2026-09-30 viewer: real routed v0.2 board (pcb.json + textures), v0.2 net explorer, top-band print over the real LED/sensor windows, Lucent UI
2026-09-30 media: final PCB time-lapse of the routed v0.2 board
2026-09-30 docs: v0.2 hardware, PCB, CAD, print and board-status docs; generated BOM doc; decisions log; build_all.sh for the v0.2 pipeline; remove v0.1-only scripts
2026-09-30 instructions: order parts, order PCB (JLC settings), print, assemble (two-sided with low-temp paste), bring-up checklist, final assembly, next steps
2026-09-30 pcb/README: correct backlight ballast guidance (keep 33 R unless duty is capped)
2026-09-30 Product page, v0.2 README, full pipeline rebuild
    - viewer/product.html: photoreal scroll-driven tour of the real CAD case and
    routed board, live Lucent UI with working soft keys, specs, build steps
    - README rewritten for v0.2 (status, build steps, renders)
    - tools/build_all.sh run end to end: fit OK, placement OK, DRC 0 errors /
    0 unconnected, netlist match, board fit OK; regenerated fab, print, viewer
    and time-lapse outputs (GPS patch at x 27.2)
    [back_shell_aero.step, back_shell_standard.step, bumper_rugged.step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]
